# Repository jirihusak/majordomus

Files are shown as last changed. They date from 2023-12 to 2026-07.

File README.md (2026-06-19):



# Majordmus - Open source system for Smart Home
 
## About
 
**Majordomus** is a modular automation system built on open standards. It fills the gap between closed, expensive commercial solutions and unreliable consumer-grade components — designed to be repairable, expandable, and to last for decades.
  
## Features
 
- 🧩 **Modular hardware** — base unit + interchangeable modules ( I/O, sensors)
- 🔌 **Standardized interface** — RS-485 / ModBus HW interface, MQTT SW interface
- 🔓 **Vendor lock-in free** — open hardware, open software, your choice
- 🧠 **Node-RED inside** — visual programming for automation flows
- 🧠 **Home Assistant interface** — MQTT integration for popular platform
- 📡 **Offline-first** — works without internet, cloud is optional
## Use Cases
 
| Domain | Examples |
|---|---|
| 🏠 Smart home | lighting, heating, blinds, security, energy management |
| 🏭 Industry | machine control, data acquisition, monitoring, alarms |
| 📊 Monitoring | weather, air quality, energy meters, IoT sensors |
 
## Architecture
 
```
   ┌─────────────────────┐
   │      node-RED       │
   │   Home Assistant    │
   └──────────┬──────────┘
              │
             MQTT
              │
   ┌──────────┴──────────┐
   │ Majordomus Control  │
   │    MQTT bridge      │
   └──────────┬──────────┘
              │
       Modbus / RS-485
              │
    ┌─────────┼─────────┐
    │         │         │
   Unit A   Unit B   Unit C
  (+ modules) (+ modules) (+ modules)
```
 
## Hardware
 
### 🌡️ RoomSensor
 
All-in-one ambient monitoring unit for indoor environments.
 
- 🌡️ Temperature & humidity
- 💨 CO₂, VOC & NOx measurement
- 🚶 PIR motion detection
- ☀️ Ambient light (lux)
- 🔊 Ambient noise measurement
- 🖥️ Display with 3 buttons
- 🔔 Piezo buzzer for acoustic signaling
- 🔌 Digital I/O for door/window contacts or local buttons
- 🔗 I²C port for external sensors
- 🏠 Wall-mount
RoomSensor

### 🔲 BoxIO
 
Compact relay & input unit for in-wall or junction-box installation.
 
- ⚡ Replaceable relay outputs (electromagnetic or SSR)
- 🔘 Digital inputs for buttons
- 📊 Hardware input counters for energy monitoring
- 🎛️ Manual control of all outputs (AUTO / MAN ON / MAN OFF)
- 🔗 I²C port for external sensors
BoxIO

### 🎛️ RoomIO
 
Multi-purpose I/O unit for room-level automation and control.
 
- 🔘 Digital inputs & outputs
- 📥 Analog inputs (ADC) — 0–10 V
- 📤 Analog outputs (DAC) — 0–10 V for dimming, fan speed, valves
- 📊 Hardware input counters for energy monitoring
- 🔗 I²C port for external sensors
RoomIO

Schematics and BOMs live in [`hardware/`](hardware/).
 
## Software
 
### **Majordomus Control**
Bridge from HW modules to MQTT interface

obrazek

### **Node-RED - Custom Node-RED nodes**

## Documentation

- [Documentation web](https://jirihusak.github.io/majordomus/cs/) 

## Contributing
 
Contributions welcome — hardware, firmware, Node-RED flows, or docs.

## Contact
 
- **Web:** [majordomus.tech](https://majordomus.tech)

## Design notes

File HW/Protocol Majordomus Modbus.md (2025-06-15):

# Protocol Majordomus Modbus
This document describes the communication protocol between Majordomus devices and Main computer. The communication is based on RS-485 physical layer. 
|Serial settings| value|
|--|--|
| Baud rate | 115 200 kbps|
| Data bits | 8 |
| Stop bits | 1 |
| Parity | None |

On the bus is one master computer and the master requests data from all devices. The device sends no data without previous request.
Every Device has Modbus Address (1 - 247). See more information about Modbus protocol: https://en.wikipedia.org/wiki/Modbus

## RoomSensor

| Logical address | Register | Action | Size B | Type | Note |
|--|--|--|--|--|--|
| 0x41001  | 0x1000 | Read | 2 | INT16 | Temperature from front cover [*10 °C] |
| 0x41002  | 0x1001 | Read | 2 | INT16 | Temperature from humidity sensor [*10 °C] |
| 0x41003  | 0x1002 | Read | 2 | UINT16 | Relative humidity [*10 %] |
| 0x41004  | 0x1003 | Read | 2 | INT16 | Temperature from 1-Wire sensor 0 [*10 °C] |
| 0x41005  | 0x1004 | Read | 2 | INT16 | Temperature from 1-Wire sensor 1 [*10 °C] |
| 0x41006  | 0x1005 | Read | 2 | UINT16 | Air Quality VOC index [0-500] |
| 0x41007  | 0x1006 | Read | 2 | UINT16 | CO2 [ppm] |
| 0x41008  | 0x1007 | Read | 4 | UINT32 | Light intensity [lux] |
| 0x4100A  | 0x1009 | Read | 2 | UINT16 | Noise level [db] |
| 0x4100B  | 0x100A | Read | 2 | UINT16 | Motion detector PIR [0/1] |
| 0x4100C  | 0x100B | Read | 2 | UINT16 | Digital inputs state bit array |
| 0x4100D  | 0x100C | Read | 2 | UINT16 | Button inputs bit array rising edge detection |
| 0x4100E  | 0x100D | Read | 2 | UINT16 | ADC0 Analog input voltage [mV] |
| 0x4100F  | 0x100E | Read | 2 | UINT16 | ADC1 Analog input voltage [mV] |
| 0x41010  | 0x100F | Read | 2 | UINT16 | Power voltage voltage [mV] |
| 0x41011  | 0x1010 | Read | 2 | UINT16 | Power voltage for outputs voltage [mV] |
| 0x62001  | 0x2000 | Write | 2 | UINT16 | Digital outputs array |
| 0x62002  | 0x2001 | Write | 2 | UINT16 | DAC0 analog outputs [mV] |
| 0x62003  | 0x2002 | Write | 2 | UINT16 | DAC1 analog outputs [mV] |
| 0x62004  | 0x2003 | Write | 2 | UINT16 | Beep tone [0-4] |
| 0x62005  | 0x2004 | Write | 2 | UINT16 | LED light [0/1] |
| 0x62006  | 0x2005 | Write | 2 | INT16 | LCD Requested temperature [*10 °C] |

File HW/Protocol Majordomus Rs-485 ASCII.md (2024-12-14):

# Protocol Majordomus Rs-485 ASCII
This document describes the communication protocol between Majordomus devices and Main computer. The communication is based on RS-485 physical layer. 
|Serial settings| value|
|--|--|
| Baud rate | 115 200 kbps|
| Data bits | 8 |
| Stop bits | 1 |
| Parity | None |

On the bus is one master computer and the master requests data from all devices. The device sends no data without previous request.
Every Device has `id` string with maximum length of 32 characters.

```mermaid
sequenceDiagram
Master->>Device A: id:A,msg:data,crc:XX
Device A -->>Master: id:A,msg:data,crc:XX
Master->>Device B: id:B,msg:data,crc:XX
Device B-->>Master: id:B,msg:data,crc:XX
```

## Generic message format for all devices
- Message starts with `id:deviceName`. 
- Message ends with `CR LF` characters.
- Message has properties separed by `,` and one property has format `key:value`.
- Last property is `crc`. [CRC Calculation](#crc-calculation)

### Example 1 - Read device status
Main computer sends message to request status from device `test`:
 `id:test,msg:status,crc:8b\r\n`
 Response from device (FW version, power voltages):
`id:test,type:RoomSens,version:0.3(Nov  2 2024),pwr:12.05,pwrOut:12.11,crc:f0`

 ### Example 2 - Read device data
Main computer sends message to request from device `test` data:
 `id:test,msg:data,crc:ea`
 Response from device (digital inputs, temperatures, humidity, etc.. ):
`id:test,di:0,btn:0,t:210,t2:211,rh:540,mo:0,voc:95,lux:569,nl:278,adc0:0.00,adc1:0.00,crc:22`

 ### Example 3 - Read and write device data
Main computer sends message to request from device `test` data and write data to device (digital outputs, DAC, led light etc.. ):
 `id:test,msg:data,do:3,dac0:5.4,dac1:1.2,light:1,reqT:225,crc:93`
 Response from device (digital inputs, temperatures, humidity, etc.. ):
`id:test,di:0,btn:0,t:210,t2:211,rh:540,mo:0,voc:95,lux:569,nl:278,adc0:0.00,adc1:0.00,crc:22`

### Example 4 - Change device id
Main computer sends config message to device `test` to change id to `test2`.
 `id:test,msg:config,newId:test2,crc:ea`

### Example 5 - Restart device
Main computer sends config message to device `test` to restart
 `id:test,msg:config,cmd:reset,crc:07`

> If you don't know device `id`, you can replace `deviceName` with string `all`. So the message is for all devices on the bus. In this case respond all devices for the request. To prevent bus colision on RS-485 every device add random delay before start sending response. This fetature is not recomended for normal operation.

### Status message
    id:device_id,msg:status,...
| From RoomIO| Note|
|--|--|
| type | type of device (RoomIO) |
| version | FW version X.Y (Build date) |
| pwr | Power voltage in volts |
| pwrOut | Power voltage in volts after fuse for digital outputs and inputs |
### Config message
    id:device_id,msg:config,...
| To RoomIO| Note|
|--|--|
| newId | Change id to new string (max 32 characters) |
| newId5050| The same as newID, but the commands will executed with 50:50 propability (depends on random generator on device). This command can be helpful when we have two same id on the bus|
| reset| Restart the device |

## RoomIO
### Data message

    id:device_id,msg:data,...

| From RoomIO| Note|
|--|--|
| adc0  | Analog input voltage |
| adc1  | Analog input voltage |
| di  | Digital inputs bit array |
| btn | Digital buttons bit array. Sends only once rising edges. |
| t0| Temperature in °C from 1-Wire sensor|
| t1| Temperature in °C from 1-Wire sensor|

| To RoomIO| note|
|--|--|
| dac0 | Set Digital to Analog voltage |
| dac1 | Set Digital to Analog voltage |
| do | Set digital outputs bit array (bit 0 = digital output 0, etc.. )|

## RoomSensor
### Data message

    id:device_id,msg:data,...

| From RoomSensor| Note|
|--|--|
| adc0  | Analog input voltage |
| adc1  | Analog input voltage |
| di  | Digital inputs bit array |
| btn | Digital buttons bit array. Sends only once rising edges. |
| t0| Temperature in °C from front cover|
| t1| Temperature in °C from humidity sensor|
| t2| Temperature in °C from 1-Wire sensor|
| t3| Temperature in °C from 1-Wire sensor|
| rh| Relative humidity in % |
| mo| Motion detector PIR [0/1] |
| voc| Air Quality VOC [0-500] |
| lux| Light intensity in lux |
| nl| Noise level in db |
| newReqT| New Temperature set request from display - send once when user confirm |

| To RoomSensor| note|
|--|--|
| dac0 | Set Digital to Analog voltage |
| dac1 | Set Digital to Analog voltage |
| do | Set digital outputs bit array (bit 0 = digital output 0, etc.. )|
| reqT| Actual temperature set displayed on LCD |
| beep| Start beeping [0-4] |
| light| Control LED light [0-1] |

## TinySensor
### Data message

    id:device_id,msg:data,...

| From TinySensor| Note|
|--|--|
| di  | Digital inputs bit array |
| btn | Digital buttons bit array. Sends only once rising edges. |
| t0| Temperature in °C |
| rh| Relative humidity in % |
| t1| Temperature in °C from 1-Wire sensor|
| t2| Temperature in °C from 1-Wire sensor|

| To RoomSensor| note|
|--|--|
| do | Set digital outputs bit array (bit 0 = digital output 0, etc.. )|

### CRC calculation

    static unsigned char const crc8_table[] = {
	    0xea, 0xd4, 0x96, 0xa8, 0x12, 0x2c, 0x6e, 0x50, 0x7f, 0x41, 0x03, 0x3d,
	    0x87, 0xb9, 0xfb, 0xc5, 0xa5, 0x9b, 0xd9, 0xe7, 0x5d, 0x63, 0x21, 0x1f,
	    0x30, 0x0e, 0x4c, 0x72, 0xc8, 0xf6, 0xb4, 0x8a, 0x74, 0x4a, 0x08, 0x36,
	    0x8c, 0xb2, 0xf0, 0xce, 0xe1, 0xdf, 0x9d, 0xa3, 0x19, 0x27, 0x65, 0x5b,
	    0x3b, 0x05, 0x47, 0x79, 0xc3, 0xfd, 0xbf, 0x81, 0xae, 0x90, 0xd2, 0xec,
	    0x56, 0x68, 0x2a, 0x14, 0xb3, 0x8d, 0xcf, 0xf1, 0x4b, 0x75, 0x37, 0x09,
	    0x26, 0x18, 0x5a, 0x64, 0xde, 0xe0, 0xa2, 0x9c, 0xfc, 0xc2, 0x80, 0xbe,
	    0x04, 0x3a, 0x78, 0x46, 0x69, 0x57, 0x15, 0x2b, 0x91, 0xaf, 0xed, 0xd3,
	    0x2d, 0x13, 0x51, 0x6f, 0xd5, 0xeb, 0xa9, 0x97, 0xb8, 0x86, 0xc4, 0xfa,
	    0x40, 0x7e, 0x3c, 0x02, 0x62, 0x5c, 0x1e, 0x20, 0x9a, 0xa4, 0xe6, 0xd8,
	    0xf7, 0xc9, 0x8b, 0xb5, 0x0f, 0x31, 0x73, 0x4d, 0x58, 0x66, 0x24, 0x1a,
	    0xa0, 0x9e, 0xdc, 0xe2, 0xcd, 0xf3, 0xb1, 0x8f, 0x35, 0x0b, 0x49, 0x77,
	    0x17, 0x29, 0x6b, 0x55, 0xef, 0xd1, 0x93, 0xad, 0x82, 0xbc, 0xfe, 0xc0,
	    0x7a, 0x44, 0x06, 0x38, 0xc6, 0xf8, 0xba, 0x84, 0x3e, 0x00, 0x42, 0x7c,
	    0x53, 0x6d, 0x2f, 0x11, 0xab, 0x95, 0xd7, 0xe9, 0x89, 0xb7, 0xf5, 0xcb,
	    0x71, 0x4f, 0x0d, 0x33, 0x1c, 0x22, 0x60, 0x5e, 0xe4, 0xda, 0x98, 0xa6,
	    0x01, 0x3f, 0x7d, 0x43, 0xf9, 0xc7, 0x85, 0xbb, 0x94, 0xaa, 0xe8, 0xd6,
	    0x6c, 0x52, 0x10, 0x2e, 0x4e, 0x70, 0x32, 0x0c, 0xb6, 0x88, 0xca, 0xf4,
	    0xdb, 0xe5, 0xa7, 0x99, 0x23, 0x1d, 0x5f, 0x61, 0x9f, 0xa1, 0xe3, 0xdd,
	    0x67, 0x59, 0x1b, 0x25, 0x0a, 0x34, 0x76, 0x48, 0xf2, 0xcc, 0x8e, 0xb0,
	    0xd0, 0xee, 0xac, 0x92, 0x28, 0x16, 0x54, 0x6a, 0x45, 0x7b, 0x39, 0x07,
	    0xbd, 0x83, 0xc1, 0xff};
	    
	uint8_t crc8(uint8_t seed = 0, unsigned char const *data, size_t len)
	{
		uint8_t crc = seed;
		if (data == NULL)
	        return 0;
	    crc &= 0xff;
	    unsigned char const *end = data + len;
	    while (data < end)
	        crc = crc8_table[crc ^ *data++];
	    return crc;
	}

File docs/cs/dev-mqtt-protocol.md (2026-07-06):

# MQTT protokol

Referenční popis MQTT rozhraní, které poskytuje Majordomus Control. Hodí se všem, kdo chtějí systém integrovat mimo Home Assistant — do Node-RED, openHAB, vlastních skriptů nebo čehokoliv dalšího, co umí MQTT.

Majordomus Control funguje jako brána: čte data z jednotek po RS-485 a publikuje je do MQTT témat. Zároveň odebírá příkazová témata a přijaté příkazy předává zpět jednotkám.

```
[RS-485 jednotky] <--serial--> [Majordomus Control] <--MQTT--> [Broker] <--> [HA / Node-RED / klient]
```

Anglický originál této reference: [MQTT_PROTOCOL.md](https://github.com/jirihusak/majordomus/blob/main/SW/MajordomusControl/MQTT_PROTOCOL.md)

---

## Struktura témat

Každé téma má tvar:

```
<prefix>/<zařízení>/<kategorie>/<klíč>
```

| Segment | Popis | Příklad |
|---|---|---|
| `<prefix>` | Nastavený MQTT prefix včetně koncového `/` | `majordomus/` |
| `<zařízení>` | Název zařízení dle konfigurace | `living_room` |
| `<kategorie>` | `tele`, `evt`, `state` nebo `cmd` | `tele` |
| `<klíč>` | Konkrétní vlastnost | `temperature0` |

**Příklad:** `majordomus/living_room/tele/temperature0`

### Kategorie témat

| Kategorie | Kdy se publikuje | Retained | Účel |
|---|---|---|---|
| `tele` | Periodicky (každý cyklus vyčítání RS-485) | **Ano** | Naměřené hodnoty senzorů |
| `evt` | Pouze při změně | **Ne** | Události: stisk tlačítka, pohyb |
| `state` | Při změně | **Ano** | Metadata zařízení a stavy výstupů |
| `cmd` | Publikuje klient (vy) | — | Příkazy pro zařízení |

Všechny zprávy se posílají s **QoS 0**. Payload je vždy UTF-8 řetězec — číslo (`22.5`, `420`), řetězec, nebo JSON pole.

---

## Odesílání příkazů

Příkaz zařízení pošlete publikováním do tématu:

```
<prefix>/<zařízení>/cmd/<klíč_příkazu>
```

**Příklad — zapnutí digitálního výstupu 0 na zařízení `living_room`:**

```
Téma:    majordomus/living_room/cmd/do0
Payload: 1
```

---

## Dostupnost zařízení

Každé zařízení publikuje svůj stav do retained tématu:

```
<prefix>/<zařízení>/state/online
```

| Payload | Význam |
|---|---|
| `online` | Zařízení odpovídá na dotazy po RS-485 |
| `offline` | Bez odpovědi déle než 3 sekundy |

Toto téma se používá jako `availability_topic` v Home Assistant discovery.

---

## Konvence hodnot

**NaN** — firmware používá hodnotu `INT16_MIN` (`-32768`) pro senzor, který není dostupný (nepřipojen, chyba čtení). Brána ji před publikováním převádí na řetězec `"NaN"`. Payload `"NaN"` vždy interpretujte jako nedostupnou hodnotu.

**Škálované hodnoty** — některá zařízení posílají po sběrnici celočíselné hodnoty, které je nutné dělit koeficientem. Převod provádí brána — přes MQTT vždy dostanete finální hodnotu jako float.

**Pocitová teplota** — pokud jsou platné `temperature0` i `humidity`, brána automaticky počítá a publikuje pocitovou teplotu (Steadmanův vzorec) do tématu `tele/apparentTemperature`.

---

## Mapy témat podle typu zařízení

### RoomIO

Univerzální I/O jednotka s teploměry, digitálními vstupy/výstupy, analogovými vstupy a čítači impulsů.

**Publikuje — `tele/` (retained):**

| Klíč | Jednotka | Typ | Poznámka |
|---|---|---|---|
| `temperature0` – `temperature2` | °C | float | Teploměry; `NaN` pokud nedostupný |
| `humidity` | % | float | Relativní vlhkost |
| `voc` | index | int | Kvalita vzduchu VOC |
| `co2` | ppm | int | Koncentrace CO₂ |
| `illuminance` | lux | int | Osvětlení |
| `distance` | — | float | Snímač vzdálenosti |
| `analog0`, `analog1` | V | float | Analogové vstupy |
| `counter0` – `counter7` | — | int | Čítače impulsů |
| `input0` – `input7` | — | `0`/`1` | Stavy digitálních vstupů |
| `apparentTemperature` | °C | float | Vypočtená pocitová teplota |

**Publikuje — `evt/` (bez retain):** `button0` – `button7` (`0`/`1`) při změně stavu tlačítka.

**Publikuje — `state/` (retained):** `version` (verze FW), `power` (napájecí napětí, V), `powerOut` (napětí za pojistkou výstupů, V), `online`.

**Příkazy — `cmd/`:**

| Klíč | Payload | Účinek |
|---|---|---|
| `do0` – `do7` | `0` / `1` | Nastavení digitálního výstupu |
| `dac0`, `dac1` | `0`–`255` | Úroveň analogového výstupu (DAC/PWM) |
| `setCnt0` – `setCnt7` | celé číslo | Přednastavení hodnoty čítače |
| `reboot` | cokoliv | Restart zařízení |

---

### RoomSensor

Pokojová jednotka se senzory prostředí, detekcí pohybu, kapacitními tlačítky a výstupy.

**Publikuje — `tele/` (retained):**

| Klíč | Jednotka | Typ | Poznámka |
|---|---|---|---|
| `temperature0` – `temperature3` | °C | float | Až 4 teploměry |
| `humidity` | % | float | Relativní vlhkost |
| `voc` | index | int | VOC index (SGP41) |
| `nox` | index | int | NOx index (SGP41) |
| `co2` | ppm | int | Koncentrace CO₂ |
| `illuminance` | lux | int | Osvětlení (VEML7700) |
| `noise` | dB | int | Hladina hluku |
| `analog0`, `analog1` | V | float | Analogové vstupy |
| `input0` – `input3` | — | `0`/`1` | Stavy digitálních vstupů |
| `apparentTemperature` | °C | float | Vypočtená pocitová teplota |

**Publikuje — `evt/` (bez retain):**

| Klíč | Typ | Kdy |
|---|---|---|
| `motion` | `0`/`1` | Změna stavu PIR čidla |
| `lastMotion` | ISO datetime | Čas poslední detekce pohybu |
| `button0` – `button3` | `0`/`1` | Stisk kapacitního tlačítka |

**Publikuje — `state/` (retained):** `version`, `power`, `powerOut`, `requestedTemperature` (aktuální žádaná teplota), `online`.

**Příkazy — `cmd/`:**

| Klíč | Payload | Účinek |
|---|---|---|
| `do0` – `do3` | `0` / `1` | Nastavení digitálního výstupu |
| `dac0`, `dac1` | `0`–`255` | Úroveň analogového výstupu |
| `beep` | celé číslo | Pípnutí piezo pípáku |
| `reqT` | float `10`–`35` | Nastavení žádané teploty |
| `light` | `0`–`100` | Úroveň LED přísvitu (%) |
| `reboot` | cokoliv | Restart zařízení |

---

### TempOutBoard

Deska pro venkovní měření s až 8 teploměry DS18B20 a digitálními výstupy.

**Publikuje — `tele/` (retained):** `temperature0` – `temperature7` (°C, float).

**Publikuje — `state/` (retained):** `version`, `power`, `powerOut`, `online`.

**Příkazy — `cmd/`:** `do0` – `do9` (`0`/`1`), `ro` (`0`–`255`, PWM výstup).

---

### RoomIR

Modul termální infrakamery (MLX90640, 32×24 pixelů).

**Publikuje — `tele/` (retained):** `irImage` — JSON pole 768 hodnot (32 sloupců × 24 řádků, po řádcích zleva shora), teploty v °C:

```json
[25.1, 25.3, 24.8, 26.0, ...]
```

**Publikuje — `state/` (retained):** `version`, `resolution` (škálovací faktor), `offset`, `online`.

---

## Home Assistant discovery

Po připojení k brokeru publikuje brána automaticky discovery zprávy pro všechna nakonfigurovaná zařízení — Home Assistant si díky nim vytvoří entity bez ručního YAML.

**Formát tématu:** `<ha_prefix>/<typ_entity>/<unique_id>/config` — např. `homeassistant/sensor/living_room_t0/config`.

**Payload (JSON, retained):**

```json
{
  "name": "temperature0",
  "unique_id": "living_room_t0",
  "state_topic": "majordomus/living_room/tele/temperature0",
  "unit_of_measurement": "°C",
  "device_class": "temperature",
  "state_class": "measurement",
  "availability_topic": "majordomus/living_room/state/online",
  "payload_available": "online",
  "payload_not_available": "offline",
  "device": {
    "identifiers": ["living_room"],
    "manufacturer": "Majordomus",
    "model": "RoomSensor",
    "name": "living_room"
  }
}
```

Discovery zprávy se znovu publikují při každém obnovení spojení s brokerem (řeší restart brokeru).

---

## Připojení k brokeru

| Parametr | Hodnota |
|---|---|
| Verze MQTT | 3.1.1 |
| URL brokeru | `tcp://host:1883` nebo `ssl://host:8883` |
| QoS | 0 (všechny zprávy) |
| Timeout připojení | 30 s |
| Keep-alive | 5 s |
| Automatický reconnect | Ano |
| TLS | Systémový Java TrustStore, nebo vlastní PEM CA certifikát |

---

## Rychlý tahák

```
ČTENÍ hodnoty senzoru:
  Subscribe: <prefix>/<zařízení>/tele/<klíč>
  Subscribe: <prefix>/<zařízení>/state/<klíč>

POSLECH událostí:
  Subscribe: <prefix>/<zařízení>/evt/<klíč>

PŘÍKAZ:
  Publish:   <prefix>/<zařízení>/cmd/<klíč>   payload: <hodnota>

DOSTUPNOST:
  Subscribe: <prefix>/<zařízení>/state/online   → "online" | "offline"

VŠE NAJEDNOU:
  Subscribe: <prefix>/#
```

!!! tip "Rychlý test z příkazové řádky"
    ```bash
    # sledování všech dat
    mosquitto_sub -h localhost -t "majordomus/#" -v

    # zapnutí výstupu do0 na zařízení living_room
    mosquitto_pub -h localhost -t "majordomus/living_room/cmd/do0" -m "1"
    ```

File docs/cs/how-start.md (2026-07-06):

# Co potřebuji pro start

Majordomus je navržen tak, aby ho zvládl zprovoznit i nadšenec bez hlubokých znalostí elektroniky nebo programování. Přesto je dobré vědět, jaké základní vybavení budete potřebovat.

---

## Minimální hardware

Pro první spuštění a vyzkoušení systému vám stačí:

- **Řídící jednotka** — například Raspberry Pi 4 nebo jakýkoliv mini PC s Linuxem. Pro první test postačí i běžný stolní počítač nebo notebook.
- **[Převodník USB → RS-485](https://majordomus.tech/rs485-2-usb/)** — propojuje řídící jednotku se sběrnicí Majordomus.
- **Modul Majordomus** — pro test stačí jeden kus [RoomIO](https://majordomus.tech/roomio/) nebo [RoomSensor](https://majordomus.tech/roomsensor/).
- **Napájecí zdroj** — 12 V DC (systém akceptuje rozsah 7–27 V DC).
- **Propojovací kabel** — běžný UTP kabel (Cat5e nebo Cat6) pro napájení a komunikaci.
- **Volitelně pro testování** — tlačítka, 12V LED indikátory, senzory apod.

!!! tip "Chci to jen vyzkoušet"
    Nepotřebujete hned kupovat Raspberry Pi ani tahat kabely po domě. Stačí notebook, USB převodník, jeden modul a kus UTP kabelu na stole — a za pár minut máte funkční systém, se kterým si můžete hrát.

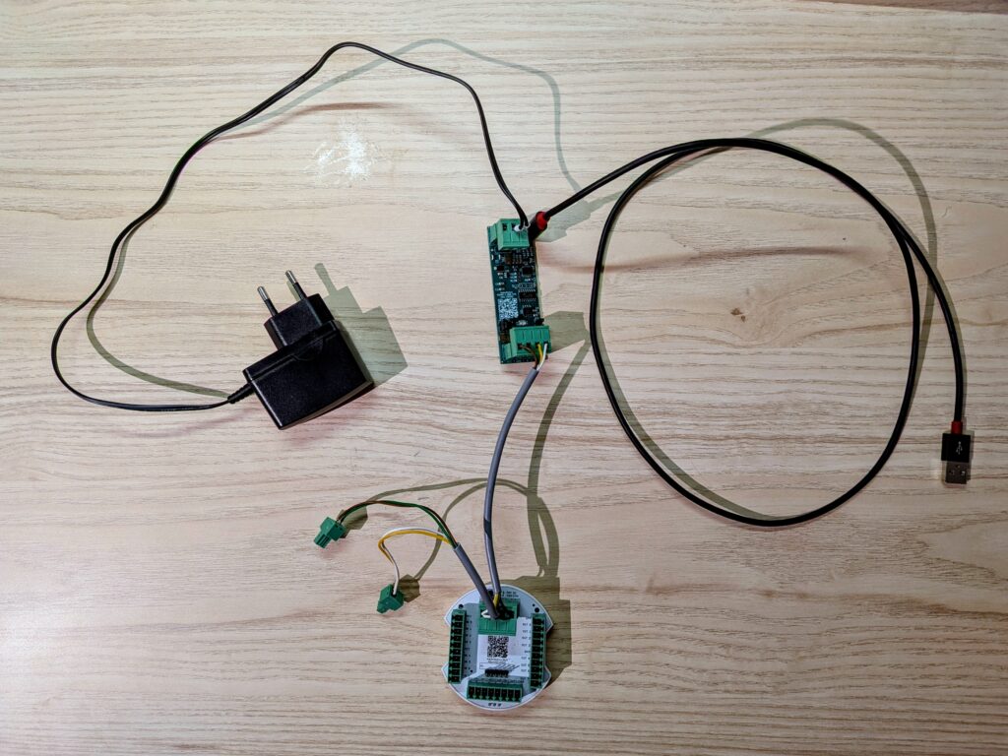
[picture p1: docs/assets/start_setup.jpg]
Minimální zapojení na vyzkoušení


---

## Software

Majordomus využívá výhradně open-source software. Nemusíte kupovat žádné licence ani řídící software — všechny nástroje jsou zdarma ke stažení.

- **OS Linux nebo Windows** — řídící jednotka běží na obojím.
- **[MajordomusControl](sw-architecture.md)** — jádro systému, které komunikuje s hardwarem a poskytuje MQTT rozhraní.
- **Aplikační software** — například [Node-RED](sw-node-red.md) pro tvorbu logiky a automatizací.

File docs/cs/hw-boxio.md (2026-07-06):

# BoxIO

BoxIO je multifunkční jednotka do rozvaděče s rozhraním RS-485 a USB. Poskytuje 8 digitálních vstupů, 6 silových výstupů a 2 analogové vstupy a výstupy. Montuje se na DIN lištu a zabírá šířku 6 modulů.

Silové výstupy jsou řešeny jako **výměnné moduly** — podle potřeby je osadíte elektromagnetickým relé (max. 16 A) nebo polovodičovým SSR (max. 2 A).

---

## Vlastnosti

- Průmyslové rozhraní RS-485
- Rozhraní USB-C (vestavěný FTDI převodník) — jednotku lze připojit i přímo do PC
- **Manuální ovládání výstupů** — třístavový přepínač pro každý výstup: manuálně zapnuto / manuálně vypnuto / automatika (řízení ze sběrnice)
- LED indikace aktivních vstupů a výstupů
- 8× digitální vstup s optickým oddělením
- Funkce čítače digitálních vstupů s pamětí FRAM
- 6× výměnný modul výstupu (relé max. 16 A, nebo SSR max. 2 A)
- 2× analogový vstup 0–30 V
- 2× analogový výstup 0–10 V
- 2× port 1-Wire pro externí teploměry DS18B20
- 1× port I2C pro externí zařízení

!!! tip "Manuální režim — dům funguje i bez serveru"
    Třístavové přepínače umožňují ovládat výstupy ručně přímo v rozvaděči. Pokud řídící počítač vypadne nebo probíhá servis, zapnete topení či světla přepínačem — bez software, bez počítače.

---

## Parametry

| Parametr | Hodnota |
|---|---|
| Vstupní napájení | 10–30 V DC |
| Komunikační rozhraní | RS-485 (ASCII protokol), Modbus, USB-C |
| Instalace | DIN lišta (šířka 6 modulů) |
| Mikrokontrolér | PIC18F57K42 |
| Aktualizace FW po RS-485 | Ano |
| Stupeň krytí | IP20 |
| Teplotní rozsah | −20 až +60 °C |

---

## Typické použití

BoxIO je určen do rozvaděče — tam, kde se sbíhá silová elektroinstalace:

- Spínání okruhů osvětlení přes relé moduly
- Ovládání ventilů topení, čerpadel a bojleru
- Spínání zásuvkových okruhů
- Odečty elektroměrů a vodoměrů s impulsním výstupem (čítače na digitálních vstupech)
- Řízení stmívatelných LED zdrojů a proporcionálních ventilů přes výstupy 0–10 V

!!! tip "Objednání a aktuální ceny"
    Aktuální ceny a objednávkový formulář najdete na [majordomus.tech/boxio](https://majordomus.tech/boxio/).

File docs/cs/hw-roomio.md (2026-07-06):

# RoomIO

RoomIO je multifunkční jednotka vstupů a výstupů s rozhraním RS-485. Poskytuje 8 digitálních vstupů, 8 digitálních výstupů, 2 analogové vstupy, 2 analogové výstupy a 2 open-drain výstupy. Lze ji rozšířit o teploměry a další senzory přes 1-Wire a I2C.

Díky kompaktnímu designu je možné jednotku snadno skrýt — instaluje se přímo do instalační krabice (KP 68) a překryje záslepkou, případně se umístí do podhledu.

---

## Vlastnosti

- Průmyslové rozhraní RS-485
- 8× digitální vstup s optickým oddělením
- Funkce čítače digitálních vstupů s pamětí FRAM (64bit čítač — hodnoty přežijí výpadek napájení)
- 8× digitální výstup (6–30 V dle napájení, do 100 mA)
- 2× analogový vstup 0–30 V
- 2× analogový výstup 0–10 V
- 2× port 1-Wire pro externí teploměry DS18B20
- 1× port I2C pro externí zařízení
- 2× open-drain výstup pro ovládání RGB LED WS2812

---

## Parametry

| Parametr | Hodnota |
|---|---|
| Vstupní napájení | 6–30 V DC |
| Komunikační rozhraní | RS-485 (ASCII protokol), Modbus |
| Instalační krabice | Přístrojová krabice KP 68 |
| Mikrokontrolér | PIC18F57K42 |
| Aktualizace FW po RS-485 | Ano |
| Stupeň krytí | IP30 |
| Teplotní rozsah | −20 až +60 °C |

---

## Typické použití

**Digitální vstupy** — připojení tlačítek, magnetických (okenních/dveřních) kontaktů nebo mikrospínačů. Každý vstup má 64bitový čítač impulsů s pamětí FRAM — ideální pro odečty elektroměrů, vodoměrů a plynoměrů s impulsním výstupem.

**Digitální výstupy** — spínání elektromagnetických relé, SSR relé nebo indikačních LED. Vstupy i výstupy pracují s napájecím napětím jednotky (typicky 12 nebo 24 V DC).

**Analogové vstupy 0–30 V** — snímače tlaku, ultrazvukové snímače vzdálenosti (např. hladina v nádrži) a podobně.

**Analogové výstupy 0–10 V** — stmívatelné zdroje LED osvětlení nebo proporcionální ventily topení.

**1-Wire** — až několik teploměrů DS18B20 na jednom portu, např. pro měření teploty podlahy nebo venkovní teploty.

!!! tip "Objednání a aktuální ceny"
    Aktuální ceny a objednávkový formulář najdete na [majordomus.tech/roomio](https://majordomus.tech/roomio/).

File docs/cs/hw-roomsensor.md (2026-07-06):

# RoomSensor

RoomSensor je švýcarský nožík mezi senzory do místnosti. Instaluje se do běžné elektroinstalační krabice (KP 68) a v jediném kompaktním zařízení pokryje vše, co v místnosti potřebujete — místo čtyř různých krabiček stačí jeden RoomSensor:

- **Jednotka vstupů a výstupů** — 4× digitální vstup, 4× digitální výstup, 2× analogový vstup, 2× analogový výstup
- **Měření veličin prostředí** — teplota, relativní vlhkost, kvalita vzduchu (VOC, NOx, CO₂)
- **Detekce přítomnosti** — PIR senzor, hlukoměr, intenzita osvětlení
- **Rozhraní pro uživatele** — grafický displej, kapacitní tlačítka a akustická signalizace

---

## Vlastnosti

### Senzory prostředí

| Veličina | Senzor |
|---|---|
| Teplota | TMP1075 |
| Relativní vlhkost | SHT-45 (s ochrannou membránou) |
| CO₂ | STCC4 |
| VOC a NOx | SGP-41 |
| Intenzita osvětlení | VEML7700 |
| Hluk | MEMS mikrofon MP34DT05-A |
| Pohyb | PIR EKMC1607113 |

### Vstupy a výstupy

- 4× digitální vstup s optickým oddělením
- 4× digitální výstup
- 2× analogový vstup 0–30 V
- 2× analogový výstup 0–10 V
- 2× port 1-Wire pro externí teploměry DS18B20
- 1× port I2C pro externí zařízení

### Uživatelské rozhraní

- Grafický displej 128×32 px (NHD-C12832A1Z)
- 3 kapacitní tlačítka (mínus, enter, plus)
- Piezo pípák pro akustické upozornění
- LED přísvit

---

## Parametry

| Parametr | Hodnota |
|---|---|
| Vstupní napájení | 7–27 V DC |
| Komunikační rozhraní | RS-485 (ASCII protokol), Modbus |
| Instalační krabice | Přístrojová krabice KP 68 |
| Design | ABB Tango |
| Mikrokontrolér | PIC18F57K42 |
| Aktualizace FW po RS-485 | Ano |
| Stupeň krytí | IP30 |
| Teplotní rozsah | −20 až +60 °C |

---

## Typické použití

Jeden RoomSensor v každé obytné místnosti — obývák, ložnice, dětský pokoj, kuchyň:

- Řízení topení podle skutečné teploty v místnosti
- Spouštění ventilace / rekuperace podle CO₂ a vlhkosti
- Automatické osvětlení podle přítomnosti a intenzity denního světla
- Ovládání světel a žaluzií kapacitními tlačítky
- Zobrazení teploty a dalších hodnot na displeji

Přes digitální a analogové vstupy/výstupy lze navíc přímo z jednotky ovládat stmívatelné LED osvětlení (0–10 V), číst okenní kontakty nebo spínat relé.

!!! tip "Objednání a aktuální ceny"
    Aktuální ceny a objednávkový formulář najdete na [majordomus.tech/roomsensor](https://majordomus.tech/roomsensor/).

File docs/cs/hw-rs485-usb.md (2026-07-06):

# Převodník RS485 2 USB

RS485 2 USB propojuje řídící počítač (Raspberry Pi, mini PC) se sběrnicí RS-485. Do počítače se připojuje konektorem USB-C a poskytuje jednu galvanicky izolovanou linku RS-485 — na ni doporučujeme připojit maximálně 10 jednotek Majordomus.

Každá linka (sběrnice) v domě potřebuje svůj převodník — viz [Topologie](topology.md).

---

## Vlastnosti

- Průmyslové rozhraní RS-485 s **galvanickým oddělením** — rušení z dlouhých linek se nepřenáší do řídícího počítače
- 1 nebo 4 komunikační linky včetně rozvodu napájení
- **Vratná pojistka** — chrání UTP kabel při zkratu na lince
- Indikační LED pro RX a TX — okamžitá vizuální kontrola komunikace
- Zakončovací odpor volitelný jumperem
- Vyrovnání GND potenciálu linky přes impedanci na PE
- Možnost připojit se přímo na UART

---

## Parametry

| Parametr | Hodnota |
|---|---|
| Vstupní napájení | 7–27 V DC |
| Komunikační rozhraní | USB (konektor USB-C) |
| Převodník | FTDI FT230XS |
| Montáž | DIN lišta |
| Stupeň krytí | IP30 |
| Teplotní rozsah | −20 až +60 °C |

---

## Připojení k počítači

Převodník používá čip FTDI, který mají Linux i Windows ve výbavě — po připojení se objeví jako sériový port bez instalace ovladačů:

| Systém | Název portu |
|---|---|
| Linux / Raspberry Pi OS | `/dev/ttyUSB0` (další převodníky `ttyUSB1`, `ttyUSB2`...) |
| Windows | `COM3`, `COM4`... |

Tento port poté nastavíte v Majordomus Control v sekci **Serial Connections** — viz [Konfigurace SW](sw-configuration.md).

!!! note "Práva k sériovému portu na Linuxu"
    Pokud Majordomus Control nemůže port otevřít, přidejte uživatele do skupiny `dialout` a znovu se přihlaste:

    ```bash
    sudo usermod -a -G dialout $USER
    ```

!!! tip "Objednání a aktuální ceny"
    Aktuální ceny a objednávkový formulář najdete na [majordomus.tech/rs485-2-usb](https://majordomus.tech/rs485-2-usb/).

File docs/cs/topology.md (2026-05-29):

# Topologie systému
 
Základem je jeden hlavní počítač (např. Raspberry Pi), ke kterému jsou přes USB připojeny RS485 převodníky. Každý převodník obsluhuje jednu **linku** — sběrnici, na které visí zařízení v dané části domu.
 
Typické rozložení pro rodinný dům:
 
```mermaid
graph TD
    PC[Mini PC / Raspberry Pi] -->|USB| L1[Linka 1 — 1. NP]
    PC -->|USB| L2[Linka 2 — 2. NP]
    PC -->|USB| L3[Linka 3 — podkroví / zahrada]
    
    L1 -->|RS-485| R1[RoomSensor — obývák]
    R1 -->|RS-485| R2[RoomSensor — kuchyň]
    R2 -->|RS-485| R3[RoomIO — chodba]
    R3 -->|RS-485| B1[BoxIO — rozvaděč 1. NP]
    
    L2 -->|RS-485| R4[RoomSensor — ložnice]
    R4 -->|RS-485| R5[RoomSensor — dětský pokoj]
    R5 -->|RS-485| R6[RoomSensor — koupelna]
    R6 -->|RS-485| B2[BoxIO — rozvaděč 2. NP]
```
 
Doporučujeme **jednu linku na patro** (nebo logickou zónu — zahrada, garáž, dílna). Na každé lince může být přibližně **10–15 zařízení**. Tento limit není technický, ale praktický — zajišťuje rychlou odezvu tlačítek a spínačů.
 
---
 
## Kabeláž
 
### Doporučený kabel
 
Sběrnice RS485 využívá standardní ethernetový kabel, který je levný, všude dostupný a snadno se s ním pracuje:
 
- **Typ:** UTP-S (stíněný) nebo UTP-F (fóliově stíněný), kategorie Cat5e nebo Cat6
- **Provedení:** doporučujeme **lanko** (flexible), ne drát (solid) — snadnější manipulace v instalačních krabicích

### Zapojení vodičů
 
UTP kabel má 8 vodičů, vždy 2 vodiče tvoří barevný pár. Vodiče zdvojíme podle barev a využijeme 4 páry:
 
| Signál | Barva vodiče | Popis |
|---|---|---|
| **+12 V** | oranžový pár | Napájení zařízení |
| **GND** | modrý pár | Zem |
| **A** | zelený pár | RS485 datový vodič A |
| **B** | hnědý pár | RS485 datový vodič B |
 
!!! tip "Proč zrovna tyto barvy?"
    Barevné přiřazení vychází ze standardního značení UTP kabelů a je jednotné napříč celým systémem Majordomus. Díky tomu se při zapojování nemůžete splést — a pokud vám někdy bude zapojení dělat někdo jiný, okamžitě se zorientuje.
 
### Maximální délka linky
 
Sběrnice RS485 při komunikační rychlosti 115 200 Bd zvládne teoreticky až **1 000 m** v ideálních podmínkách. Pro běžné domácí instalace doporučujeme:
 
- **Do 200 m na linku** — spolehlivý provoz bez kompromisů

---
 
## Napájení
 
Všechna zařízení na sběrnici se napájí přímo z linky napětím **12 V DC**. Stačí jeden zdroj na celý systém.
 
- **Standardní instalace:** 12V spínaný zdroj s dostatečným výkonem pro všechna zařízení na lince (např. 25W - 75W)
- **Instalace s UPS:** zdroj s akumulátorovou zálohou na napětí **13,8 V** — systém běží i při výpadku elektřiny
 
---

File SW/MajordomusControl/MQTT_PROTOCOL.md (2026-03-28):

# MajordomusControl — MQTT Protocol Reference

**Version:** 1.0
**System:** MajordomusControl — RS-485 to MQTT Gateway
**Protocol:** MQTT v3.1.1

---

## Overview

MajordomusControl is a gateway that bridges RS-485 sensor devices to an MQTT broker.
It reads sensor data from physical devices over serial RS-485 and publishes it to MQTT topics.
It also subscribes to command topics and forwards received commands back to devices via RS-485.

```
[RS-485 Devices] <--serial--> [MajordomusControl] <--MQTT--> [Broker] <--> [HA / AI / Client]
```

---

## Table of Contents

1. [Topic Structure](#1-topic-structure)
2. [Topic Categories](#2-topic-categories)
3. [QoS and Retain Policy](#3-qos-and-retain-policy)
4. [Sending Commands](#4-sending-commands)
5. [Availability](#5-availability)
6. [Sensor Value Conventions](#6-sensor-value-conventions)
7. [Device Types and Topic Maps](#7-device-types-and-topic-maps)
   - [RoomIO](#71-roomio)
   - [RoomSensor](#72-roomsensor)
   - [TempOutBoard](#73-tempoutboard)
   - [RoomIR](#74-roomir)
8. [Home Assistant Discovery](#8-home-assistant-discovery)
9. [Connection and Configuration](#9-connection-and-configuration)
10. [Quick Reference Cheatsheet](#10-quick-reference-cheatsheet)

---

## 1. Topic Structure

Every topic follows this pattern:

```
<prefix>/<device_name>/<category>/<key>
```

| Segment | Description | Example |
|---|---|---|
| `<prefix>` | Configured MQTT topic prefix, including trailing `/` | `majordomus/` |
| `<device_name>` | Device name as defined in `config.xml` | `living_room` |
| `<category>` | One of: `tele`, `evt`, `state` | `tele` |
| `<key>` | Specific property name | `temperature0` |

**Full example:**
```
majordomus/living_room/tele/temperature0
```

---

## 2. Topic Categories

| Category | Trigger | Retained | Purpose |
|---|---|---|---|
| `tele` | Periodic polling (every RS-485 poll cycle) | **Yes** | Sensor measurements |
| `evt` | On-change only | **No** | Events: button presses, motion |
| `state` | On change | **Yes** | Device metadata and output states |

---

## 3. QoS and Retain Policy

- **QoS:** `0` (at most once) for all messages
- **Retain:**
  - `tele/` → `true`
  - `state/` → `true`
  - `evt/` → `false`
  - Home Assistant discovery → `true`

---

## 4. Sending Commands

To control a device, publish to:

```
<prefix>/<device_name>/cmd/<command_key>
```

**Payload:** plain UTF-8 string (numeric value or string constant)

The gateway subscribes to `<prefix>/#` to receive all commands under the prefix.

**Command routing:**
- Topic must have at least 4 levels
- Level `[2]` must be exactly `cmd`
- Level `[1]` is the device name
- Level `[3]` is the command key
- Payload is the command value

**Example — turn on digital output 0 on device `living_room`:**
```
Topic:   majordomus/living_room/cmd/do0
Payload: 1
```

---

## 5. Availability

Every device publishes its online status to:

```
<prefix>/<device_name>/state/online
```

| Payload | Meaning |
|---|---|
| `online` | Device is responding to RS-485 polls |
| `offline` | No response for more than 3 seconds |

- Retained: **Yes**
- This topic is used as `availability_topic` in Home Assistant discovery configs.

---

## 6. Sensor Value Conventions

### Payload format

All payloads are UTF-8 encoded strings.

| Data type | Example payload |
|---|---|
| Float | `22.5` |
| Integer | `420` |
| Unavailable sensor | `NaN` |
| JSON array | `[25.1, 25.3, ...]` |

### NaN sentinel

The firmware uses `INT16_MIN` (`-32768`) to indicate that a sensor is not available
(hardware not connected, read error, etc.).
The gateway converts this value to the string `"NaN"` before publishing.

**Rule for consumers:** If the payload is `"NaN"`, the reading should be treated as unavailable/unknown.

### Scaled values

Some devices (e.g., TempOutBoard) transmit raw integer values that must be divided by a scaling factor.
This conversion is done by the gateway before publishing — consumers always receive the final scaled float.

### Apparent temperature

When both `temperature0` (key `t0`) and `humidity` (key `rh`) are valid,
the gateway automatically calculates and publishes an apparent ("feels like") temperature using the Steadman formula:

```
e  = (rh / 100) × 6.105 × exp(17.27 × T / (237.7 + T))
AT = T + 0.33 × e − 4.00
```

Published to: `<prefix>/<device_name>/tele/apparentTemperature`

---

## 7. Device Types and Topic Maps

### 7.1 RoomIO

General-purpose I/O module with temperature sensors, digital inputs/outputs, analog inputs, and pulse counters.

#### Published — `tele/` (retained)

| Topic key | Unit | Type | Notes |
|---|---|---|---|
| `temperature0` | °C | float | Sensor 0; `NaN` if unavailable |
| `temperature1` | °C | float | Sensor 1; `NaN` if unavailable |
| `temperature2` | °C | float | Sensor 2 (optional); `NaN` if unavailable |
| `humidity` | % | float | Relative humidity; `NaN` if unavailable |
| `voc` | index | integer | VOC air quality index; `NaN` if unavailable |
| `co2` | ppm | integer | CO₂ concentration; `NaN` if unavailable |
| `illuminance` | lux | integer | Ambient light; `NaN` if unavailable |
| `distance` | unit | float | Distance sensor; `NaN` if unavailable |
| `analog0` | V | float | ADC channel 0 |
| `analog1` | V | float | ADC channel 1 |
| `counter0` – `counter7` | — | integer | Pulse counters 0–7 |
| `input0` – `input7` | — | `0`/`1` | Digital input states (decoded from bitfield) |
| `apparentTemperature` | °C | float | Calculated; published when `temperature0` and `humidity` are valid |

#### Published — `evt/` (not retained)

| Topic key | Type | Trigger |
|---|---|---|
| `button0` – `button7` | `0`/`1` | Published on button state change (decoded from bitfield) |

#### Published — `state/` (retained)

| Topic key | Type | Notes |
|---|---|---|
| `version` | string | Firmware version string |
| `power` | V | Supply voltage |
| `powerOut` | V | Output supply voltage |
| `online` | `online`/`offline` | Device availability |

#### Commands — `cmd/` (subscribe)

| Command key | Payload | Effect |
|---|---|---|
| `do0` – `do7` | `0` or `1` | Set digital output state |
| `dac0`, `dac1` | `0`–`255` | Set DAC/PWM analog output level |
| `setCnt0` – `setCnt7` | integer string | Preset pulse counter value |
| `reboot` | any | Reboot the device |

---

### 7.2 RoomSensor

Room sensor unit with temperature, humidity, air quality, motion, light, and noise sensors,
plus capacitive touch buttons and optional heating/lighting outputs.

#### Published — `tele/` (retained)

| Topic key | Unit | Type | Notes |
|---|---|---|---|
| `temperature0` – `temperature3` | °C | float | Up to 4 temperature sensors; `NaN` if unavailable |
| `humidity` | % | float | Relative humidity; `NaN` if unavailable |
| `voc` | index | integer | VOC index (Sensirion SGP40/41); `NaN` if unavailable |
| `nox` | index | integer | NOx index (Sensirion SGP41); `NaN` if unavailable |
| `co2` | ppm | integer | CO₂ concentration; `NaN` if unavailable |
| `illuminance` | lux | integer | Ambient light (VEML7700); `NaN` if unavailable |
| `noise` | dB | integer | Ambient noise level; `NaN` if unavailable |
| `analog0`, `analog1` | V | float | ADC channels |
| `input0` – `input3` | — | `0`/`1` | Digital input states |
| `apparentTemperature` | °C | float | Calculated; published when `temperature0` and `humidity` are valid |

#### Published — `evt/` (not retained)

| Topic key | Type | Trigger |
|---|---|---|
| `motion` | `0`/`1` | Motion detector (PIR) state change |
| `lastMotion` | ISO datetime string | Timestamp of last motion event |
| `button0` – `button3` | `0`/`1` | Capacitive touch button state change |

#### Published — `state/` (retained)

| Topic key | Type | Notes |
|---|---|---|
| `version` | string | Firmware version |
| `power` | V | Supply voltage |
| `powerOut` | V | Output supply voltage |
| `requestedTemperature` | °C | Current setpoint (floor heating / HVAC) |
| `online` | `online`/`offline` | Device availability |

#### Commands — `cmd/` (subscribe)

| Command key | Payload | Effect |
|---|---|---|
| `do0` – `do3` | `0` or `1` | Set digital output |
| `dac0`, `dac1` | `0`–`255` | Set DAC output level |
| `beep` | integer | Trigger piezo beep (duration or pattern code) |
| `reqT` | float `10`–`35` | Set requested temperature setpoint |
| `light` | `0`–`100` | Set light level (%) |
| `reboot` | any | Reboot the device |

---

### 7.3 TempOutBoard

Outdoor temperature board with up to 8 temperature sensors (DS18B20) and digital outputs.

#### Published — `tele/` (retained)

| Topic key | Unit | Type | Notes |
|---|---|---|---|
| `temperature0` – `temperature7` | °C | float | DS18B20 sensors; `NaN` if unavailable |

#### Published — `state/` (retained)

| Topic key | Type | Notes |
|---|---|---|
| `version` | string | Firmware version |
| `power` | V | Supply voltage |
| `powerOut` | V | Output supply voltage |
| `online` | `online`/`offline` | Device availability |

#### Commands — `cmd/` (subscribe)

| Command key | Payload | Effect |
|---|---|---|
| `do0` – `do9` | `0` or `1` | Set digital output |
| `ro` | `0`–`255` | Set resistor/PWM output level |

---

### 7.4 RoomIR

Thermal infrared camera module (MLX90640, 32×24 pixels).

#### Published — `tele/` (retained)

| Topic key | Type | Notes |
|---|---|---|
| `irImage` | JSON array string | 768 float values (32×24 pixels) representing temperature in °C |

**IR image format:**
```json
[25.1, 25.3, 24.8, 26.0, ...]
```
- Array length: **768 elements** (32 columns × 24 rows)
- Row-major order, top-left first
- Values in °C (float)
- Raw bytes from device are received as base64-encoded RS-485 chunks,
  assembled in memory, scaled by the device's resolution factor,
  then published as a single JSON array string.

#### Published — `state/` (retained)

| Topic key | Type | Notes |
|---|---|---|
| `version` | string | Firmware version |
| `resolution` | float | Scaling factor used for raw→°C conversion |
| `offset` | integer | Byte offset (internal assembly parameter) |
| `online` | `online`/`offline` | Device availability |

---

## 8. Home Assistant Discovery

When the gateway connects to the broker, it automatically publishes
MQTT discovery messages for all configured devices.
This allows Home Assistant to auto-configure entities without manual YAML.

### Discovery topic format

```
<ha_prefix>/<entity_type>/<unique_id>/config
```

| Segment | Example |
|---|---|
| `<ha_prefix>` | `homeassistant` (configured separately from MQTT prefix) |
| `<entity_type>` | `sensor`, `binary_sensor`, `switch`, `number` |
| `<unique_id>` | `living_room_t0` |

### Discovery payload (JSON, retained)

```json
{
  "name": "temperature0",
  "unique_id": "living_room_t0",
  "state_topic": "majordomus/living_room/tele/temperature0",
  "unit_of_measurement": "°C",
  "device_class": "temperature",
  "state_class": "measurement",
  "availability_topic": "majordomus/living_room/state/online",
  "payload_available": "online",
  "payload_not_available": "offline",
  "device": {
    "identifiers": ["living_room"],
    "manufacturer": "Majordomus",
    "model": "RoomSensor",
    "name": "living_room"
  }
}
```

### Re-publish trigger

Discovery configs are re-published on every MQTT reconnect
(`connectComplete` callback) to handle broker restarts.

---

## 9. Connection and Configuration

### Broker URL formats

| Scheme | Description |
|---|---|
| `tcp://host:port` | Plain TCP (default port: 1883) |
| `ssl://host:port` | TLS/SSL (default port: 8883) |

### Connection parameters

| Parameter | Value |
|---|---|
| MQTT version | 3.1.1 |
| QoS (all messages) | 0 |
| Connection timeout | 30 s |
| Keep-alive interval | 5 s |
| Automatic reconnect | Yes |

### SSL/TLS options

| Setting | Description |
|---|---|
| Default CA | Uses system Java TrustStore |
| Self-signed CA | Path to a PEM-encoded CA certificate file |

### config.xml structure

```xml
<MQTT>
  <broker
    address="tcp://broker.example.com:1883"
    username="user"
    passwd="password"
    topic="majordomus/"
    selfsigned="false"
    cert="/path/to/ca.crt"
  />
</MQTT>

<HomeAssistant>
  <settings
    enable="true"
    topic="homeassistant/"
  />
</HomeAssistant>
```

---

## 10. Quick Reference Cheatsheet

```
READ sensor value:
  Subscribe: <prefix>/<device>/tele/<key>
  Subscribe: <prefix>/<device>/state/<key>

LISTEN for events:
  Subscribe: <prefix>/<device>/evt/<key>

SEND command:
  Publish:   <prefix>/<device>/cmd/<key>   payload: <value>

CHECK availability:
  Subscribe: <prefix>/<device>/state/online   → "online" | "offline"

WILDCARD (all devices, all data):
  Subscribe: <prefix>/#
```

### Common sensor keys across device types

| MQTT key | Description | Unit |
|---|---|---|
| `tele/temperature0` | Primary temperature | °C |
| `tele/humidity` | Relative humidity | % |
| `tele/voc` | VOC air quality index | — |
| `tele/co2` | CO₂ concentration | ppm |
| `tele/illuminance` | Ambient light | lux |
| `tele/noise` | Ambient noise | dB |
| `tele/apparentTemperature` | Feels-like temperature | °C |
| `evt/motion` | Motion detection | `0`/`1` |
| `evt/button0` | Button 0 press | `0`/`1` |
| `state/online` | Availability | `online`/`offline` |
| `state/version` | Firmware version | string |
| `cmd/do0` | Digital output 0 | `0`/`1` |
| `cmd/reboot` | Reboot device | any |

---

*Generated from MajordomusControl source code analysis.*

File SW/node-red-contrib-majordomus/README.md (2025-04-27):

# Majordomus for node-red

## Light

The Light node allows control your light with buttons, presense senor and luxmeter. The node supports ON/OFF or dimmable light.

### Features
- Control with buttons (toggle output)
- Automatic turn on the light on motion
- Automatic on only in night based on luxmeter
- Automatic turn off the light after no presense timeout
- Fade in and fade out for dimmable lights

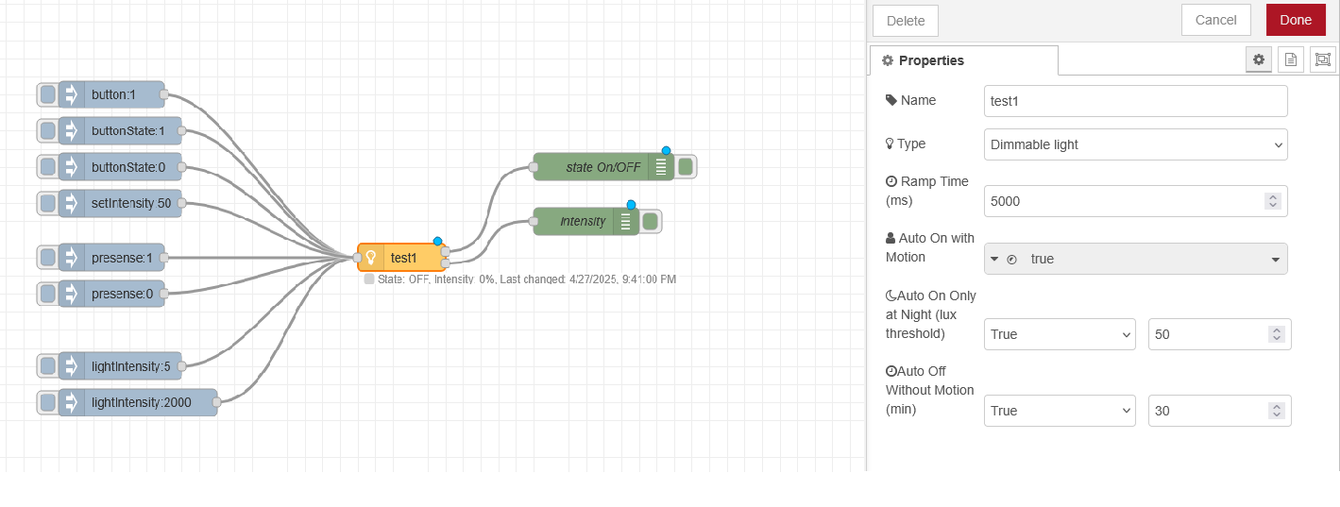
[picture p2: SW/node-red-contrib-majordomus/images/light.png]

Scheduler

## Scheduler

The Scheduler node allows you to configure time-based rules to control your application.

### Features
- Define rules for specific days or day ranges.
- Set start and end times for each rule.
- Assign a value to output during active periods.
- Visualize rules in a weekly schedule preview.

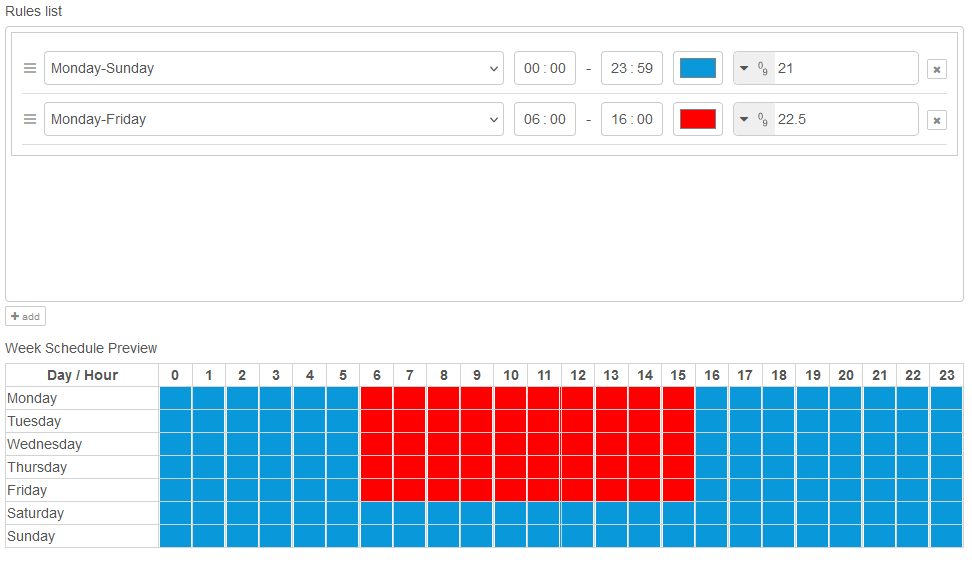
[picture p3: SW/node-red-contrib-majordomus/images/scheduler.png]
Scheduler

Scheduler

### Configuration Options

### Name
Specify a unique name for the node.

### Rules List
Manage a list of time-based rules:
- **Day Range**: Select specific days or day ranges (e.g., Monday-Sunday).
- **Start Time**: Define when the rule becomes active.
- **End Time**: Define when the rule becomes inactive.
- **Value**: Set the value to output during the active period.
- **Color**: Assign a color to visualize the rule in the preview table.

### Outputs
The node outputs a value defined in the rules when the current time falls within a rule's active period.

##### Examples

### Workday Schedule
- **Day Range**: Monday-Friday
- **Time**: 09:00 - 17:00
- **Output Value**: "Working Hours"

### Weekend Relaxation
- **Day Range**: Saturday-Sunday
- **Time**: 10:00 - 22:00
- **Output Value**: "Relaxing"

### Status Indicators
- **Green dot**: Indicates an active rule is being executed.
- **Gray ring**: No active rules match the current time.

## More Information
Visit the [project's GitHub repository](https://github.com/jirihusak/majordomus) or (https://www.majordomus.tech)

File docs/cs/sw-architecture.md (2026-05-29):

# Architektura software

Softwarová vrstva systému Majordomus běží na nízkoenergetickém počítači (typicky Raspberry Pi). Celý systém je navržen tak, aby byl spolehlivý, otevřený, snadno rozšiřitelný a **nezávislý na cloudu** — vše běží lokálně u vás doma.

---

## Majordomus Control

Jádro celého systému. Majordomus Control je most mezi fyzickým hardwarem a světem aplikací.

- Komunikuje přímo s HW jednotkami po sběrnici RS-485
- Překládá zprávy mezi jednotkami a **MQTT** protokolem
- Řídí konfiguraci, aktualizaci firmware a diagnostiku jednotek
- Poskytuje **webové rozhraní** pro konfiguraci a servis
- Běží na Raspberry Pi nebo jakémkoliv jiném PC s Linuxem/Windows

!!! info "Majordomus Control je jediný software, který potřebujete od Majordomu"
    Vše ostatní — MQTT broker, Node-RED, Home Assistant — jsou standardní open-source nástroje, které si nainstalujete sami podle svých potřeb.

---

## MQTT Broker

Komunikační páteř mezi Majordomus Control a všemi aplikacemi. Doporučujeme [Eclipse Mosquitto](https://mosquitto.org/) — lehký, spolehlivý a ověřený miliony instalací po celém světě.

- Slouží jako komunikační vrstva mezi Majordomus Control a aplikacemi třetích stran
- Umožňuje integraci s Home Assistant, Node-RED, openHAB a dalšími
- Standardní protokol — jakýkoliv software s podporou MQTT se dokáže připojit

---

## Aplikace pro automatizaci

Majordomus vám nediktuje, jaký software máte používat. Díky MQTT si zvolíte to, co vám vyhovuje:

### Node-RED

Vizuální programovací nástroj pro tvorbu automatizací. Ideální pro řízení klíčových funkcí domu — topení, osvětlení, žaluzie, ventilace. Logiku vytváříte přetahováním bloků, bez nutnosti psát kód.

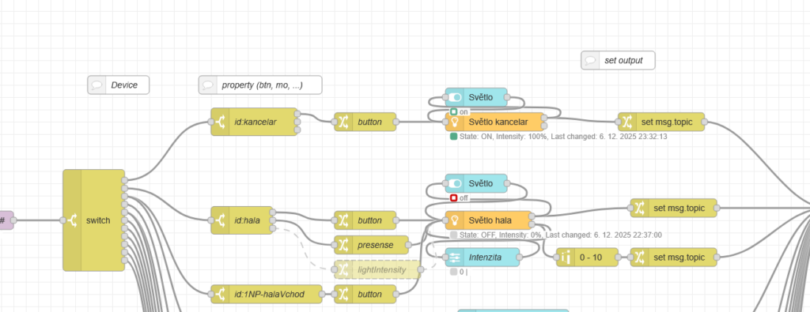
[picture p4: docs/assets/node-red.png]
Majordomus COntrol Web interface


### Home Assistant

Populární platforma pro chytrou domácnost. Slouží jako uživatelské rozhraní — mobilní aplikace, dashboardy, hlasové ovládání. Umožňuje také integraci s dalšími zařízeními mimo Majordomus (televize, FVE, elektromobil, meteostanice a stovky dalších).

### Jiný software

Díky otevřenému MQTT rozhraní můžete použít jakýkoliv systém, který MQTT podporuje — openHAB, Domoticz, vlastní skripty v Pythonu nebo cokoliv dalšího.

---

## Jak spolu jednotlivé vrstvy komunikují

```mermaid
graph LR
    HW[HW jednotky] -->|RS-485| MC[Majordomus Control]
    MC -->|MQTT| BR[MQTT Broker]
    BR -->|MQTT| NR[Node-RED]
    BR -->|MQTT| HA[Home Assistant]
    BR -->|MQTT| OTHER[Další software]
    NR -->|MQTT| BR
    HA -->|MQTT| BR
```

Komunikace je **obousměrná** — aplikace čtou data ze senzorů (teplota, pohyb, stav tlačítka) a zároveň posílají příkazy zpět do systému (rozsvítit světlo, spustit žaluzii, přepnout relé).

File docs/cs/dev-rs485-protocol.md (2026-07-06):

# Protokol RS-485

Referenční popis komunikace mezi jednotkami Majordomus a řídícím počítačem po sběrnici RS-485. Jednotky podporují dva protokoly:

- **ASCII protokol** — nativní protokol systému Majordomus, používá ho Majordomus Control
- **Modbus RTU** — standardní průmyslový protokol pro integraci s PLC a SCADA systémy

Anglické originály: [ASCII protokol](https://github.com/jirihusak/majordomus/blob/main/HW/Protocol%20Majordomus%20Rs-485%20ASCII.md) · [Modbus](https://github.com/jirihusak/majordomus/blob/main/HW/Protocol%20Majordomus%20Modbus.md)

---

## Parametry sériové linky

| Parametr | Hodnota |
|---|---|
| Rychlost | 115 200 bps |
| Datové bity | 8 |
| Stop bity | 1 |
| Parita | žádná |

Na sběrnici je jeden **master** (řídící počítač) — jednotky nikdy nevysílají samy od sebe, pouze odpovídají na dotaz. Každé zařízení má textové `id` o maximální délce 32 znaků.

```mermaid
sequenceDiagram
    Master->>Zařízení A: id:A,msg:data,crc:XX
    Zařízení A-->>Master: id:A,msg:data,crc:XX
    Master->>Zařízení B: id:B,msg:data,crc:XX
    Zařízení B-->>Master: id:B,msg:data,crc:XX
```

---

## ASCII protokol

### Formát zprávy

- Zpráva začíná `id:<název_zařízení>`.
- Končí znaky `CR LF`.
- Vlastnosti jsou odděleny čárkou, každá má formát `klíč:hodnota`.
- Poslední vlastností je vždy `crc` — [výpočet níže](#vypocet-crc).

### Příklady

**Čtení stavu zařízení** (verze FW, napájecí napětí):

```
→  id:test,msg:status,crc:8b\r\n
←  id:test,type:RoomSens,version:0.3(Nov  2 2024),pwr:12.05,pwrOut:12.11,crc:f0
```

**Čtení dat:**

```
→  id:test,msg:data,crc:ea
←  id:test,di:0,btn:0,t:210,t2:211,rh:540,mo:0,voc:95,lux:569,nl:278,adc0:0.00,adc1:0.00,crc:22
```

**Čtení a zápis v jedné zprávě** (digitální výstupy, DAC, přísvit, žádaná teplota):

```
→  id:test,msg:data,do:3,dac0:5.4,dac1:1.2,light:1,reqT:225,crc:93
←  id:test,di:0,btn:0,t:210,t2:211,rh:540,mo:0,voc:95,lux:569,nl:278,adc0:0.00,adc1:0.00,crc:22
```

**Změna id zařízení:**

```
→  id:test,msg:config,newId:test2,crc:ea
```

**Restart zařízení:**

```
→  id:test,msg:config,cmd:reset,crc:07
```

!!! tip "Neznám id zařízení"
    Místo názvu zařízení lze použít `all` — zprávu pak zpracují všechna zařízení na sběrnici. Aby nedošlo ke kolizi, každé zařízení před odpovědí čeká náhodnou dobu. Pro běžný provoz se to nedoporučuje, hodí se pro prvotní zjištění zařízení na lince.

### Zpráva `status`

```
id:<zařízení>,msg:status,...
```

| Odpověď | Význam |
|---|---|
| `type` | Typ zařízení (např. `RoomSens`) |
| `version` | Verze FW: `X.Y (datum sestavení)` |
| `pwr` | Napájecí napětí ve voltech |
| `pwrOut` | Napájecí napětí za pojistkou vstupů/výstupů |

### Zpráva `config`

```
id:<zařízení>,msg:config,...
```

| Klíč | Význam |
|---|---|
| `newId` | Změna id na nový řetězec (max. 32 znaků) |
| `newId5050` | Jako `newId`, ale zařízení příkaz provede s pravděpodobností 50 % — řeší situaci, kdy mají dvě zařízení na sběrnici stejné id |
| `cmd:reset` | Restart zařízení |

### Zpráva `data` — RoomIO

| Ze zařízení | Význam |
|---|---|
| `adc0`, `adc1` | Napětí analogových vstupů |
| `di` | Bitové pole digitálních vstupů |
| `btn` | Bitové pole tlačítek — posílá se jednou při náběžné hraně |
| `t0`, `t1` | Teploty z 1-Wire senzorů (°C) |

| Do zařízení | Význam |
|---|---|
| `dac0`, `dac1` | Nastavení analogových výstupů |
| `do` | Bitové pole digitálních výstupů (bit 0 = výstup 0, ...) |

### Zpráva `data` — RoomSensor

| Ze zařízení | Význam |
|---|---|
| `adc0`, `adc1` | Napětí analogových vstupů |
| `di` | Bitové pole digitálních vstupů |
| `btn` | Bitové pole tlačítek — posílá se jednou při náběžné hraně |
| `t0` | Teplota z předního krytu (°C) |
| `t1` | Teplota ze senzoru vlhkosti (°C) |
| `t2`, `t3` | Teploty z 1-Wire senzorů (°C) |
| `rh` | Relativní vlhkost (%) |
| `mo` | PIR detektor pohybu (`0`/`1`) |
| `voc` | Kvalita vzduchu VOC (0–500) |
| `lux` | Intenzita osvětlení (lux) |
| `nl` | Hladina hluku (dB) |
| `newReqT` | Nová žádaná teplota zadaná uživatelem na displeji — posílá se jednou při potvrzení |

| Do zařízení | Význam |
|---|---|
| `dac0`, `dac1` | Nastavení analogových výstupů |
| `do` | Bitové pole digitálních výstupů |
| `reqT` | Žádaná teplota zobrazená na LCD |
| `beep` | Spuštění pípání (0–4) |
| `light` | Ovládání LED přísvitu (`0`/`1`) |

### Zpráva `data` — TinySensor

| Ze zařízení | Význam |
|---|---|
| `di` | Bitové pole digitálních vstupů |
| `btn` | Bitové pole tlačítek |
| `t0` | Teplota (°C) |
| `rh` | Relativní vlhkost (%) |
| `t1`, `t2` | Teploty z 1-Wire senzorů (°C) |

| Do zařízení | Význam |
|---|---|
| `do` | Bitové pole digitálních výstupů |

!!! note "Formát číselných hodnot"
    Teploty a vlhkost se po sběrnici posílají jako celá čísla ×10 — např. `t:210` znamená 21,0 °C, `rh:540` znamená 54,0 %.

### Výpočet CRC

Kontrolní součet je CRC-8 počítaný tabulkou z celé zprávy před vlastností `crc`:

```c
static unsigned char const crc8_table[] = {
    0xea, 0xd4, 0x96, 0xa8, 0x12, 0x2c, 0x6e, 0x50, 0x7f, 0x41, 0x03, 0x3d,
    0x87, 0xb9, 0xfb, 0xc5, 0xa5, 0x9b, 0xd9, 0xe7, 0x5d, 0x63, 0x21, 0x1f,
    0x30, 0x0e, 0x4c, 0x72, 0xc8, 0xf6, 0xb4, 0x8a, 0x74, 0x4a, 0x08, 0x36,
    0x8c, 0xb2, 0xf0, 0xce, 0xe1, 0xdf, 0x9d, 0xa3, 0x19, 0x27, 0x65, 0x5b,
    0x3b, 0x05, 0x47, 0x79, 0xc3, 0xfd, 0xbf, 0x81, 0xae, 0x90, 0xd2, 0xec,
    0x56, 0x68, 0x2a, 0x14, 0xb3, 0x8d, 0xcf, 0xf1, 0x4b, 0x75, 0x37, 0x09,
    0x26, 0x18, 0x5a, 0x64, 0xde, 0xe0, 0xa2, 0x9c, 0xfc, 0xc2, 0x80, 0xbe,
    0x04, 0x3a, 0x78, 0x46, 0x69, 0x57, 0x15, 0x2b, 0x91, 0xaf, 0xed, 0xd3,
    0x2d, 0x13, 0x51, 0x6f, 0xd5, 0xeb, 0xa9, 0x97, 0xb8, 0x86, 0xc4, 0xfa,
    0x40, 0x7e, 0x3c, 0x02, 0x62, 0x5c, 0x1e, 0x20, 0x9a, 0xa4, 0xe6, 0xd8,
    0xf7, 0xc9, 0x8b, 0xb5, 0x0f, 0x31, 0x73, 0x4d, 0x58, 0x66, 0x24, 0x1a,
    0xa0, 0x9e, 0xdc, 0xe2, 0xcd, 0xf3, 0xb1, 0x8f, 0x35, 0x0b, 0x49, 0x77,
    0x17, 0x29, 0x6b, 0x55, 0xef, 0xd1, 0x93, 0xad, 0x82, 0xbc, 0xfe, 0xc0,
    0x7a, 0x44, 0x06, 0x38, 0xc6, 0xf8, 0xba, 0x84, 0x3e, 0x00, 0x42, 0x7c,
    0x53, 0x6d, 0x2f, 0x11, 0xab, 0x95, 0xd7, 0xe9, 0x89, 0xb7, 0xf5, 0xcb,
    0x71, 0x4f, 0x0d, 0x33, 0x1c, 0x22, 0x60, 0x5e, 0xe4, 0xda, 0x98, 0xa6,
    0x01, 0x3f, 0x7d, 0x43, 0xf9, 0xc7, 0x85, 0xbb, 0x94, 0xaa, 0xe8, 0xd6,
    0x6c, 0x52, 0x10, 0x2e, 0x4e, 0x70, 0x32, 0x0c, 0xb6, 0x88, 0xca, 0xf4,
    0xdb, 0xe5, 0xa7, 0x99, 0x23, 0x1d, 0x5f, 0x61, 0x9f, 0xa1, 0xe3, 0xdd,
    0x67, 0x59, 0x1b, 0x25, 0x0a, 0x34, 0x76, 0x48, 0xf2, 0xcc, 0x8e, 0xb0,
    0xd0, 0xee, 0xac, 0x92, 0x28, 0x16, 0x54, 0x6a, 0x45, 0x7b, 0x39, 0x07,
    0xbd, 0x83, 0xc1, 0xff};

uint8_t crc8(uint8_t seed, unsigned char const *data, size_t len)
{
    uint8_t crc = seed;
    if (data == NULL)
        return 0;
    crc &= 0xff;
    unsigned char const *end = data + len;
    while (data < end)
        crc = crc8_table[crc ^ *data++];
    return crc;
}
```

---

## Modbus

Jednotky podporují i standardní protokol **Modbus RTU** se stejnými parametry sériové linky. Každé zařízení má Modbus adresu 1–247.

### Registry — RoomSensor

| Logická adresa | Registr | Přístup | Velikost | Typ | Význam |
|--|--|--|--|--|--|
| 0x41001 | 0x1000 | čtení | 2 B | INT16 | Teplota z předního krytu [×10 °C] |
| 0x41002 | 0x1001 | čtení | 2 B | INT16 | Teplota ze senzoru vlhkosti [×10 °C] |
| 0x41003 | 0x1002 | čtení | 2 B | UINT16 | Relativní vlhkost [×10 %] |
| 0x41004 | 0x1003 | čtení | 2 B | INT16 | Teplota z 1-Wire senzoru 0 [×10 °C] |
| 0x41005 | 0x1004 | čtení | 2 B | INT16 | Teplota z 1-Wire senzoru 1 [×10 °C] |
| 0x41006 | 0x1005 | čtení | 2 B | UINT16 | Kvalita vzduchu VOC index [0–500] |
| 0x41007 | 0x1006 | čtení | 2 B | UINT16 | CO₂ [ppm] |
| 0x41008 | 0x1007 | čtení | 4 B | UINT32 | Intenzita osvětlení [lux] |
| 0x4100A | 0x1009 | čtení | 2 B | UINT16 | Hladina hluku [dB] |
| 0x4100B | 0x100A | čtení | 2 B | UINT16 | PIR detektor pohybu [0/1] |
| 0x4100C | 0x100B | čtení | 2 B | UINT16 | Bitové pole digitálních vstupů |
| 0x4100D | 0x100C | čtení | 2 B | UINT16 | Bitové pole tlačítek (náběžná hrana) |
| 0x4100E | 0x100D | čtení | 2 B | UINT16 | ADC0 — napětí analogového vstupu [mV] |
| 0x4100F | 0x100E | čtení | 2 B | UINT16 | ADC1 — napětí analogového vstupu [mV] |
| 0x41010 | 0x100F | čtení | 2 B | UINT16 | Napájecí napětí [mV] |
| 0x41011 | 0x1010 | čtení | 2 B | UINT16 | Napájecí napětí výstupů [mV] |
| 0x62001 | 0x2000 | zápis | 2 B | UINT16 | Bitové pole digitálních výstupů |
| 0x62002 | 0x2001 | zápis | 2 B | UINT16 | DAC0 — analogový výstup [mV] |
| 0x62003 | 0x2002 | zápis | 2 B | UINT16 | DAC1 — analogový výstup [mV] |
| 0x62004 | 0x2003 | zápis | 2 B | UINT16 | Pípák [0–4] |
| 0x62005 | 0x2004 | zápis | 2 B | UINT16 | LED přísvit [0/1] |
| 0x62006 | 0x2005 | zápis | 2 B | INT16 | Žádaná teplota na LCD [×10 °C] |

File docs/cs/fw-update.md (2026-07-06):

# Aktualizace firmware

Všechny jednotky Majordomus podporují **aktualizaci firmware přímo po sběrnici RS-485**. Nemusíte nic demontovat ze zdi, nepotřebujete programátor — nový firmware nahrajete z webového rozhraní Majordomus Control a jednotka se aktualizuje na dálku.

Jak to funguje: každá jednotka obsahuje kromě aplikačního firmware i **zavaděč (bootloader)**, který se stará o přijetí nového firmware po sběrnici. Majordomus Control rozparsuje soubor `.hex`, po blocích ho odešle jednotce a po dokončení jednotku restartuje do nové aplikace.

---

## 1. Stažení firmware

Aktuální soubory firmware najdete na GitHubu v sekci Releases pod tagem **FW**:

→ [github.com/jirihusak/majordomus/releases](https://github.com/jirihusak/majordomus/releases)

Např. `RoomSens.v0.2.hex` pro RoomSensor nebo `RoomIO.v0.2.hex` pro RoomIO.

---

## 2. Umístění souborů do složky `updateFW`

Majordomus Control hledá firmware ve složce `updateFW` ve svém pracovním adresáři (u klasické instalace tedy typicky `~/majordomus/updateFW`). Uvnitř vytvořte podsložku **s přesným názvem typu zařízení** a do ní vložte soubor `.hex`:

```
~/majordomus/
├── config.xml
└── updateFW/
    ├── RoomSensor/
    │   └── RoomSens.v0.2.hex
    └── RoomIO/
        └── RoomIO.v0.2.hex
```

Název podsložky musí odpovídat typu zařízení tak, jak je uveden v konfiguraci:

| Typ zařízení | Název složky |
|---|---|
| RoomSensor | `updateFW/RoomSensor/` |
| RoomIO | `updateFW/RoomIO/` |
| BoxIO | `updateFW/BoxIO/` |
| TempOutBoard | `updateFW/TempOutBoard/` |
| RoomIR | `updateFW/RoomIR/` |

!!! note "Instalace v Dockeru"
    Pracovní adresář aplikace v kontejneru je `/app`. Přimapujte složku s firmwarem jako volume v `docker-compose.yml`:

    ```yaml
    volumes:
      - ./majordomus:/config
      - ./updateFW:/app/updateFW
    ```

---

## 3. Spuštění aktualizace

1. Otevřete webové rozhraní Majordomus Control (`http://<IP_ADRESA>:8899`).
2. Přejděte do sekce **Firmware Update**.
3. V poli **Device** vyberte jednotku, kterou chcete aktualizovat — nabídka firmware se automaticky omezí na soubory odpovídající jejímu typu.
4. V poli **Select Firmware** vyberte verzi.
5. Klikněte na **Start Update** a sledujte průběh na ukazateli.

Během aktualizace je jednotka mimo provoz (neodpovídá na dotazy, výstupy drží poslední stav). Aktualizace trvá řádově desítky sekund až jednotky minut.

!!! warning "Během aktualizace"
    Neodpojujte napájení jednotky ani převodník RS-485 a nerestartujte Majordomus Control. Pokud se aktualizace přesto přeruší, jednotka zůstane v zavaděči — nic se neztratí, aktualizaci jednoduše spusťte znovu.

---

## 4. Ověření

Po dokončení se jednotka restartuje do nového firmware. Verzi ověříte:

- ve **webovém rozhraní** Majordomus Control v detailu zařízení, nebo
- přes MQTT v tématu `<prefix>/<zařízení>/state/version`.

Verze obsahuje číslo a datum sestavení, např. `0.3(Nov  2 2024)`.

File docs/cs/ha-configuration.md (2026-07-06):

# Konfigurace Home Assistant

Po instalaci zbývají dva kroky: nastavit doplněk Majordomus a propojit Home Assistant s MQTT brokerem. Poté se všechna zařízení Majordomus objeví v Home Assistantu automaticky.

---

## Konfigurace doplňku Majordomus

Nastavení najdete v **Nastavení → Aplikace → Majordomus → Konfigurace** (při instalaci přes Docker odpovídají tyto volby proměnným prostředí v `docker-compose.yml`).

| Volba | Výchozí hodnota | Význam |
|---|---|---|
| `mqtt_host` | `core-mosquitto` | Adresa MQTT brokeru. Výchozí hodnota ukazuje na doplněk Mosquitto v HAOS. |
| `mqtt_port` | `1883` | Port MQTT brokeru. |
| `mqtt_user` | *(prázdné)* | Uživatelské jméno pro MQTT. |
| `mqtt_password` | *(prázdné)* | Heslo pro MQTT. |
| `mqtt_topic` | `majordomus/` | Kořenové MQTT téma, pod kterým Majordomus publikuje data. |
| `ha_discovery` | `true` | Automatické ohlašování zařízení do Home Assistantu (auto-discovery). |
| `ha_topic` | `homeassistant/` | Téma pro auto-discovery — musí odpovídat nastavení MQTT integrace v HA (výchozí hodnotu neměňte). |

Po změně konfigurace doplněk restartujte.

!!! note "Nastavení HW jednotek"
    Sériové porty a seznam HW jednotek se nenastavují zde, ale ve webovém rozhraní Majordomus Control (položka **Majordomus** v bočním panelu). Podrobnosti v kapitole [Konfigurace SW](sw-configuration.md).

---

## Připojení Home Assistant k MQTT

Aby Home Assistant viděl data z Majordomu, musí se připojit ke stejnému MQTT brokeru:

1. Přejděte do **Nastavení → Zařízení a služby**.
2. Pokud používáte doplněk Mosquitto, Home Assistant broker sám objeví — stačí kliknout na **Konfigurovat** u nalezené integrace MQTT a potvrdit.
3. Jinak klikněte na **Přidat integraci**, vyhledejte **MQTT** a zadejte adresu brokeru, uživatelské jméno a heslo ručně.

!!! tip "Ověření komunikace"
    V integraci MQTT klikněte na **Konfigurovat → Naslouchat tématu** a zadejte `majordomus/#`. Pokud vše funguje, uvidíte proud zpráv z vašich jednotek.

---

## Auto-discovery — zařízení se objeví sama

Majordomus Control s povoleným `ha_discovery` ohlašuje všechna zařízení automaticky. V **Nastavení → Zařízení a služby → integrace MQTT** se objeví každá HW jednotka jako samostatné zařízení se všemi svými entitami:

- **RoomSensor** — teplota, vlhkost, CO₂, VOC, osvětlení, hluk, pohyb, tlačítka, stmívání světel
- **RoomIO / BoxIO** — digitální vstupy a výstupy, relé

Žádné YAML soubory, žádná ruční konfigurace entit. Přidáte-li později novou jednotku v Majordomus Control, v Home Assistantu se objeví sama.

---

## Dashboard a mobilní aplikace

Jakmile jsou entity v Home Assistantu, můžete je začít používat:

- **Dashboard** — v **Nastavení → Dashboardy** vytvořte přehled domu; entity Majordomus přidáváte jako jakékoliv jiné (karty s teplotou, grafy, přepínače světel...).
- **Mobilní aplikace** — nainstalujte [Home Assistant Companion](https://companionapp.home-assistant.io/) pro Android nebo iOS a ovládejte dům odkudkoliv.
- **Historie** — data ze všech senzorů se automaticky ukládají; grafy najdete u každé entity nebo v záložce **Historie**.

!!! tip "Automatizace: Home Assistant, nebo Node-RED?"
    Jednoduché automatizace (notifikace na mobil, rozsvícení při pohybu) zvládne Home Assistant sám v **Nastavení → Automatizace**. Kritickou logiku domu — topení, žaluzie, ventilaci — doporučujeme držet v [Node-RED](sw-node-red.md), který běží nezávisle na Home Assistantu.

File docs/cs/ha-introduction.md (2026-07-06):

# Home Assistant

## Co je Home Assistant?

Home Assistant je nejpopulárnější open-source platforma pro chytrou domácnost na světě. Běží lokálně u vás doma, funguje bez cloudu a podporuje **tisíce integrací** — od světel a termostatů přes televize a fotovoltaiku až po elektromobily.

Kolem Home Assistantu existuje obrovská komunita: pravidelné měsíční aktualizace, tisíce návodů a doplňků a aktivní fóra, kde najdete řešení téměř na cokoliv.

Home Assistant je open-source a zcela zdarma → [home-assistant.io](https://www.home-assistant.io/)

---

## Proč Home Assistant v chytrém domě?

V rámci chytré domácnosti slouží Home Assistant především jako **uživatelské rozhraní celého domu**:

- **Dashboardy** — přehled celého domu na jedné obrazovce: teploty, spotřeba, stav světel, žaluzií a topení.
- **Mobilní aplikace** — ovládání domu odkudkoliv, notifikace na mobil (pro Android i iOS).
- **Hlasové ovládání** — propojení s hlasovými asistenty.
- **Integrace třetích stran** — televize, fotovoltaika, elektromobil, meteostanice, chytré spotřebiče a stovky dalších zařízení mimo Majordomus.
- **Historie a grafy** — automatické ukládání a vizualizace dat ze všech senzorů.

---

## Home Assistant a Majordomus

V systému Majordomus má každý nástroj svou roli:

- **Majordomus Control** zajišťuje spolehlivý sběr a řízení dat na úrovni hardwaru (RS-485 → MQTT).
- **Node-RED** zpracovává kritickou logiku domu — topení, osvětlení, žaluzie.
- **Home Assistant** je výkladní skříň celého systému — dashboardy, mobilní aplikace a integrace s okolním světem.

```mermaid
graph LR
    HW[HW jednotky] -->|RS-485| MC[Majordomus Control]
    MC -->|MQTT| BR[MQTT Broker]
    BR -->|MQTT| HA[Home Assistant]
    HA --> APP[Mobilní aplikace / Dashboardy]
```

!!! tip "Auto-discovery — zařízení se objeví sama"
    Majordomus Control podporuje **MQTT auto-discovery**. Všechny senzory, spínače a další zařízení Majordomus se v Home Assistantu objeví automaticky — bez ruční konfigurace, bez psaní YAML souborů.

Home Assistant přitom není podmínkou — systém Majordomus funguje i bez něj. Pokud vám stačí Node-RED a jeho dashboard, Home Assistant instalovat nemusíte. Většina uživatelů ale ocení jeho mobilní aplikaci a snadnou tvorbu přehledných dashboardů.

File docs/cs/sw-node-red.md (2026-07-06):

# Node-RED

## Co je Node-RED?

Node-RED je vizuální nástroj pro tvorbu automatizací a logiky pomocí takzvaných „flow" (toků). Místo klasického programování skládáte jednotlivé funkční bloky (uzly) graficky a propojujete je mezi sebou. Každý uzel má jasně danou funkci — může přijímat data ze senzorů, zpracovávat je, vyhodnocovat podmínky nebo ovládat výstupy.

Výsledek? Přehledné automatizace, které zvládnete vytvořit i bez programátorských zkušeností. A pokud programovat umíte, můžete v jednotlivých uzlech psát vlastní funkce v JavaScriptu.

Node-RED je open-source a zcela zdarma → [nodered.org](https://nodered.org/)

Node-RED rozhraní

---

## Proč Node-RED v chytrém domě?

V rámci chytré domácnosti slouží Node-RED jako **centrální mozek automatizace**. Proudí do něj data ze senzorů — teplota, vlhkost, osvětlení, pohyb, spotřeby — a na jejich základě rozhoduje o akcích:

- Klesla teplota pod 20 °C? → Zapni topení.
- Nikdo není doma déle než 30 minut? → Zhasni všechna světla.
- Vlhkost v koupelně přesáhla 80 %? → Spusť ventilaci.
- Otevřelo se okno? → Vypni topení v dané místnosti.
- CO₂ přesáhl 1000 ppm? → Otevři rekuperaci.

Velkou výhodou je možnost snadno propojit různé technologie a protokoly (MQTT, HTTP, databáze, cloudové služby) na jednom místě.

---

## Node-RED a Majordomus

V systému Majordomus má každý nástroj svou roli:

- **Majordomus Control** zajišťuje spolehlivý sběr a řízení dat na úrovni hardwaru.
- **Node-RED** přebírá tato data a přidává jim smysl — propojuje informace ze senzorů s akcemi, přizpůsobuje chování domu konkrétním potřebám uživatele.

Automatizace tak můžete postupně rozšiřovat, upravovat a ladit **bez zásahu do firmware zařízení**. Přidáte nový senzor? Stačí přidat pár uzlů do flow. Chcete změnit logiku topení? Přepojíte bloky v prohlížeči. Žádné překládání kódu, žádné nahrávání firmware.

!!! tip "Deploy jedním kliknutím"
    Rozhraní Node-RED běží jako webová služba v prohlížeči. Změny v programu se nasadí kliknutím na tlačítko **Deploy** — okamžitě, bez restartu, bez složitého překládání a nahrávání.

---

## Instalace Node-RED

Na Raspberry Pi s Raspberry Pi OS:

```bash
bash <(curl -sL https://raw.githubusercontent.com/node-red/linux-installers/master/deb/update-nodejs-and-nodered)
```

Povolení automatického spouštění:

```bash
sudo systemctl enable nodered.service
sudo systemctl start nodered.service
```

Rozhraní bude dostupné na `http://<IP_ADRESA>:1880`.

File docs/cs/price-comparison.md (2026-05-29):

# Cenové srovnání

Představte si, že kupujete tričko. V obchodě máte tři možnosti: levné tričko za 50 Kč, které se po třech praních roztáhne. Kvalitní tričko za 500 Kč z poctivého materiálu, které vám vydrží roky. A značkové tričko za 1 500 Kč — stejný materiál jako to za 500, ale platíte za logo a krabičku.
Se systémy pro chytrou domácnost je to stejné.

Majordomus je jako to tričko za 500 Kč. Kvalitní komponenty, spolehlivá drátová komunikace, kompaktní návrh — ale bez příplatku za značku a uzavřený ekosystém. Platíte za reálnou hodnotu, ne za krabičku a logo.

Pojďme se podívat na příklad nákupu HW pro modelový dům s 5 zónami od různých výrobců.

## Modelový dům / byt s 5 zónami

Scénář: **5 místností**, v každé pokrýváme vnitřní klima, osvětlení, žaluzie a detekci přítomnosti, integrace s rekuperací, apod.

### Co potřebujeme v každé zóně

**Senzory (měření):** teplota + vlhkost, CO₂, intenzita osvětlení, pohybový senzor, 4 tlačítka na zdi, vstupy na záplavový senzor a okenní kontakty

**Akční členy (ovládání):** spínání 230VAC pro topné ventily, osvětlení, spínání žaluzií, ovládání výstupu 0-10V pro stmívání osvětlení

**Rozhraní pro integraci** Digitální rozhraní ModBus pro integraci rekuperace, klimatizace apod. zařízení třetích stran.

---

### Cena s využitím HW Loxone — 5 zón

| Komponenta | Ks | Cena/ks s DPH (Kč) | Celkem (Kč) |
|---|---|---|---|
| Centrální jednotka (miniserver) | 1 | 19 842 | 19 842 |
| Teplotní + vlhkostní senzor + CO₂ + tlačítka | 5 | 7 350 | 36 750 |
| PIR / přítomnostní senzor + intenzita osvětlení | 5 | 3 321 | 16 605|
| Vstupy níkonapěťové (okenní kontakty, záplavový senzor, tlačítka) | 5 | 2 478 | 12 390 |
| Výstupy 230 VAC (akční člen) | 2 | 10 222 | 20 444 |
| Ovládání AO (0-10V) | 2 | 8 202 | 16 404 |
| Rozhraní ModBus | 2 | 7577 | 15 154 |
| **Celkem** | | | **137 589** |

Cena vychází z oficiálních stránek shop.loxone.com, 2Q/26. V ceně není zahrnut projekt, instalace, SW apod. Cena je pouze za klíčové prvky HW.

---

### Levná asijská řešení ( ZigBee + logika na cloudu) — 5 zón

| Komponenta | Ks | Cena/ks (Kč) | Celkem (Kč) |
|---|---|---|---|
| ZigBee brána (Gateway) | 1 | 500 | 500 |
| Senzor teploty + vlhkosti (ZigBee) | 5 | 300 | 1 500 |
| Senzor CO₂ (ZigBee, většinou pouze eCO₂) | 5 | 1 200 | 6 000 |
| PIR pohybový senzor (ZigBee) | 5 | 250 | 1 250 |
| Senzor osvětlení (ZigBee) | 5 | 350 | 1 750 |
| Tlačítkový ovladač / scény (ZigBee) | 5 | 400 | 2 000 |
| Relé modul 230 V | 10 | 350 | 3 500 |
| **Celkem** | | | **16 500** |

Ceny z AliExpress, 2Q/26. Na první pohled nejlevnější varianta — ale je třeba počítat s tím, co v ceně není vidět:

- **5 krabiček na zeď v každé místnosti** — senzor T+RH, CO₂, PIR, lux a tlačítka jsou samostatná zařízení.
- **Bezdrátové spojení** — závislost na Wi-Fi/ZigBee, výpadky signálu, rušení.
- **Baterie** — většina senzorů běží na CR2450/CR2032, výměna každých 6–12 měsíců × 25 senzorů = nekonečný kolotoč.
- **eCO₂ ≠ CO₂** — levné senzory neměří skutečný CO₂, pouze odhadují z VOC. Přesnost je nesrovnatelná.
- **Žádná záruka dlouhodobé dostupnosti** — výrobce z AliExpressu může kdykoliv zmizet.
- **0–10 V výstupy** — v ZigBee ekosystému prakticky neexistují, nelze ovládat stmívání profesionálních svítidel.
- **Cloudová závislost** — většina Tuya zařízení vyžaduje cloudové připojení. Server vypnou = nefunguje.

---

### Cena s komponenty Majordomus

| Komponenta | Ks | Cena/ks (Kč) | Celkem (Kč) |
|---|---|---|---|
| Mini PC / Raspberry Pi + zdroj | 1 | 4 500 | 4 500 |
| RoomSensor (teplota, vlhkost, CO₂, VOC, světlo, PIR, 4 tlačítka — vše v 1 ks) | 5 | 5 900| 29 500|
| BoxIO (spínání 230 VAC výstupů, AO) | 4 | 3 500 | 14 000 |
| RS485 / ModBus převodník USB | 3 | 850 | 2 550 |
| **Celkem** | | | **50 550**|

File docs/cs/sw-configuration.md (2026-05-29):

# Konfigurace Majordomus Control

Veškerá konfigurace se provádí přes webové rozhraní na adrese `http://<IP_ADRESA>:8899`. Žádné ruční editování konfiguračních souborů není potřeba — vše nastavíte z prohlížeče.

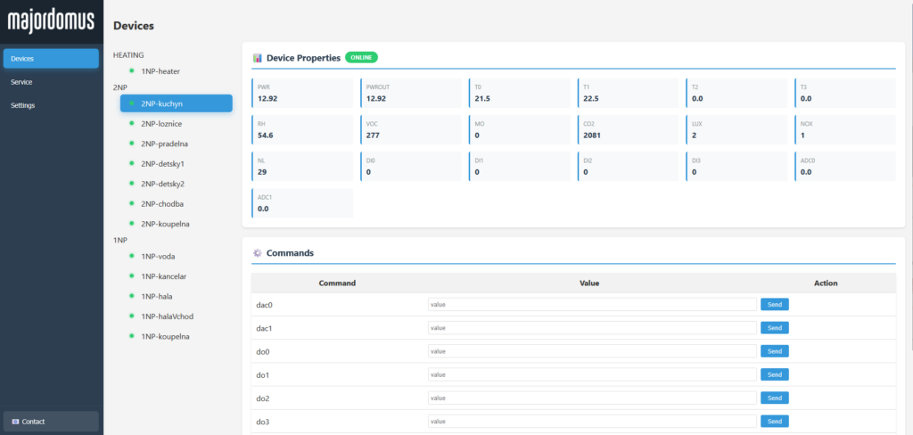
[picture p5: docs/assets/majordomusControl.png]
Webové rozhraní Majordomus Control


---

## MQTT Broker

Nastavení připojení k MQTT brokeru (Mosquitto), který slouží jako komunikační vrstva mezi Majordomus Control a aplikacemi (Node-RED, Home Assistant...).

- **IP adresa a port** — adresa MQTT brokeru (typicky `localhost:1883`, pokud běží na stejném zařízení)
- **Autentizace** — uživatelské jméno a heslo pro připojení
- **TLS certifikáty** — pro šifrovanou komunikaci v produkčním nasazení

---

## Home Assistant Integration

Povolí automatické odesílání konfiguračních informací o zařízeních Majordomus do Home Assistantu. Díky tomu se vaše senzory, spínače a další zařízení **automaticky objeví** v Home Assistantu bez nutnosti ruční konfigurace.

!!! tip "Auto-discovery"
    Po povolení této integrace stačí v Home Assistantu přejít do Nastavení → Zařízení a služby — vaše Majordomus jednotky se tam samy zobrazí.

---

## Serial Connections

Nastavení sériových portů, na kterých jsou připojeny převodníky USB → RS-485. Každý sériový port odpovídá jedné lince sběrnice.

Typické názvy portů:

| Systém | Příklad |
|---|---|
| Linux | `/dev/ttyUSB0`, `/dev/ttyUSB1`, `/dev/ttyUSB2` |
| Windows | `COM3`, `COM4`, `COM5` |

!!! note "Více linek"
    Pokud máte v domě více linek (např. jednu na patro), každá linka má svůj převodník a tedy svůj sériový port. Všechny porty nastavíte zde.

---

## Devices

Seznam všech HW jednotek v systému a jejich přiřazení k jednotlivým sériovým portům (linkám). Podle tohoto seznamu Majordomus Control ví, s jakými zařízeními má komunikovat a na které lince je hledat.

Pro každé zařízení nastavíte:

- **Typ** — RoomSensor, RoomIO, BoxIO
- **Adresa** — unikátní adresa zařízení na sběrnici
- **Sériový port** — na které lince je zařízení připojeno
- **Název** — volitelný popisek pro snadnou orientaci (např. „Obývák", „Koupelna 2.NP")

---

## Konfigurační soubor

Konfigurace se automaticky ukládá do souboru `config.xml` v pracovním adresáři aplikace Majordomus Control (typicky `~/majordomus/config.xml`). Soubor se generuje automaticky přes webové rozhraní — ruční editace není nutná, ale je možná.

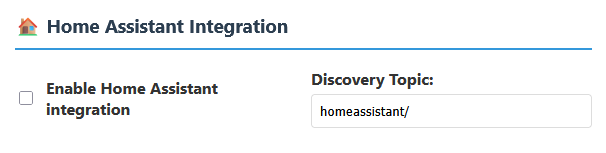
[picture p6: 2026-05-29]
docs/assets/mc_ha.png

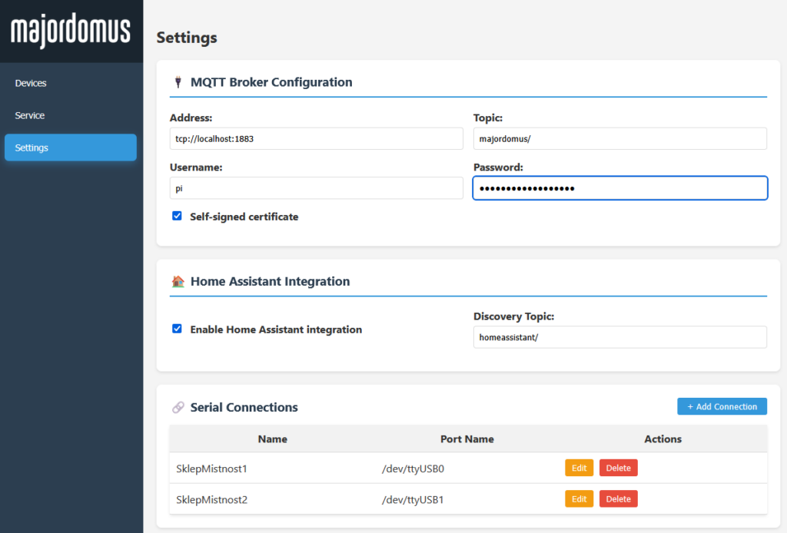
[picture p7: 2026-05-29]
docs/assets/mc_settings.png

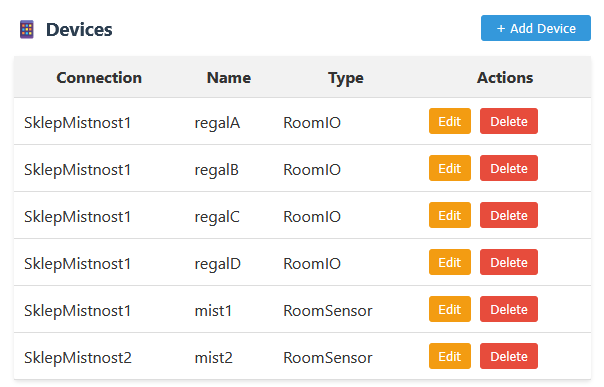
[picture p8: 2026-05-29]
docs/assets/mc_devices.png

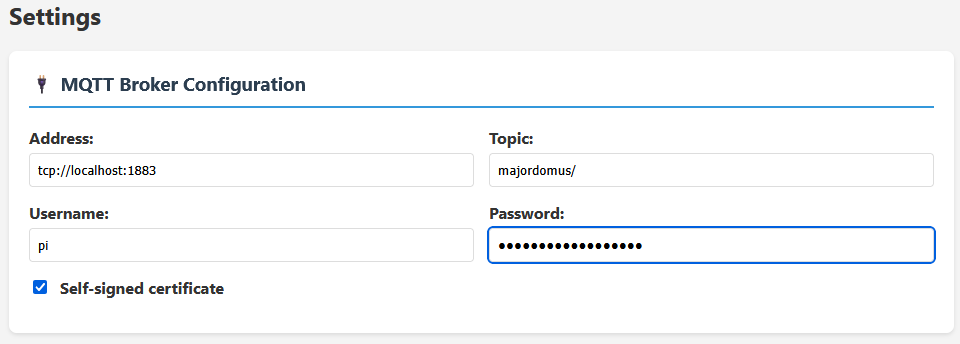
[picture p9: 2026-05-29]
docs/assets/mc_mqtt_broker.png

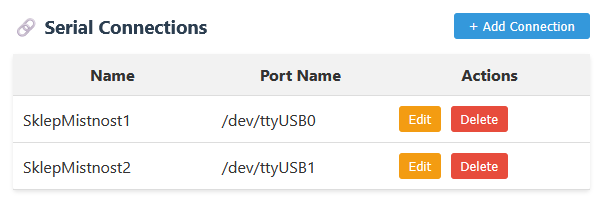
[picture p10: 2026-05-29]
docs/assets/mc_serial.png

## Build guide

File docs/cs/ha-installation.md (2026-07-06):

# Instalace Home Assistant

Home Assistant lze provozovat dvěma základními způsoby a pro oba existuje připravená instalace Majordomus Control:

| Varianta | Pro koho | Majordomus Control |
|---|---|---|
| **Home Assistant OS (HAOS)** | Doporučeno pro většinu uživatelů | Doplněk (add-on) přímo v Home Assistantu |
| **Docker** | Pro pokročilé, kteří už Docker používají | Samostatný kontejner přes Docker Compose |

---

## Varianta A: Home Assistant OS + doplněk Majordomus

Home Assistant OS je kompletní operační systém — nainstalujete ho na Raspberry Pi (nebo jiný mini PC) a o nic dalšího se nestaráte. Aktualizace, zálohy i instalace doplňků probíhají přímo z webového rozhraní.

### 1. Instalace Home Assistant OS

1. Stáhněte si [Raspberry Pi Imager](https://www.raspberrypi.com/software/).
2. Zvolte **Choose OS → Other specific-purpose OS → Home assistants and home automation → Home Assistant**.
3. Zapište systém na SD kartu (doporučujeme min. 32 GB) a vložte ji do Raspberry Pi.
4. Po několika minutách bude Home Assistant dostupný na adrese `http://homeassistant.local:8123`.

Podrobný oficiální návod: [home-assistant.io/installation](https://www.home-assistant.io/installation/)

### 2. Instalace MQTT brokeru (Mosquitto)

Majordomus komunikuje s Home Assistantem přes MQTT. V HAOS nainstalujete broker jedním kliknutím:

1. Přejděte do **Nastavení → Aplikace → Obchod s doplňky**.
2. Vyhledejte **Mosquitto broker** a klikněte na **Nainstalovat**.
3. Po instalaci doplněk **Spusťte** a zapněte **Spustit při startu**.
4. V **Nastavení → Lidé → Uživatelé** vytvořte nového uživatele (např. `mqtt`) — jeho jméno a heslo použijete pro připojení Majordomu k brokeru.

### 3. Přidání repozitáře Majordomus

1. Přejděte do **Nastavení → Aplikace → Obchod s doplňky**.
2. Klikněte na menu **⋮** (vpravo nahoře) → **Repozitáře**.
3. Vložte adresu repozitáře a potvrďte:

```
https://github.com/jirihusak/majordomus-ha-addon
```

### 4. Instalace doplňku Majordomus

1. V obchodě s doplňky se nyní objeví sekce **Majordomus** — klikněte na doplněk **Majordomus**.
2. Klikněte na **Nainstalovat**.
3. Na záložce **Konfigurace** vyplňte přihlašovací údaje k MQTT (uživatel vytvořený v kroku 2). Výchozí `mqtt_host: core-mosquitto` ukazuje na doplněk Mosquitto — ten neměňte.
4. Doplněk **Spusťte** a zapněte **Spustit při startu** a **Zobrazit v bočním panelu**.

V bočním panelu Home Assistantu se objeví položka **Majordomus** — webové rozhraní Majordomus Control, kde nastavíte sériové porty a HW jednotky (viz [Konfigurace SW](sw-configuration.md)).

!!! note "Převodník USB → RS-485"
    Doplněk má povolený přístup k sériovým portům (UART). Převodník stačí připojit do USB — v rozhraní Majordomus Control ho pak najdete typicky jako `/dev/ttyUSB0`.

---

## Varianta B: Docker

Pokud provozujete Home Assistant v Dockeru (Home Assistant Container), doplňky nejsou k dispozici — Majordomus Control spustíte jako samostatný kontejner. Následující `docker-compose.yml` obsahuje kompletní sestavu: MQTT broker, Home Assistant i Majordomus Control.

```yaml
services:

  mosquitto:
    image: eclipse-mosquitto:2
    container_name: mosquitto
    restart: unless-stopped
    ports:
      - "1883:1883"
    volumes:
      - ./mosquitto/config:/mosquitto/config
      - ./mosquitto/data:/mosquitto/data

  homeassistant:
    image: ghcr.io/home-assistant/home-assistant:stable
    container_name: homeassistant
    restart: unless-stopped
    network_mode: host
    environment:
      - TZ=Europe/Prague
    volumes:
      - ./homeassistant:/config

  majordomus:
    image: ghcr.io/jirihusak/majordomus-control-amd64:latest
    container_name: majordomus
    restart: unless-stopped
    ports:
      - "8899:8899"
    devices:
      - /dev/ttyUSB0:/dev/ttyUSB0
    volumes:
      - ./majordomus:/config
    environment:
      MQTT_BROKER: "tcp://mosquitto:1883"
      MQTT_USERNAME: ""
      MQTT_PASSWORD: ""
      MQTT_TOPIC: "majordomus/"
      HA_DISCOVERY: "true"
      HA_TOPIC: "homeassistant/"
```

!!! warning "Zvolte správnou architekturu"
    Image existuje ve dvou variantách — použijte tu, která odpovídá vašemu zařízení:

    - `ghcr.io/jirihusak/majordomus-control-amd64` — běžné PC, NUC, x86 servery
    - `ghcr.io/jirihusak/majordomus-control-aarch64` — Raspberry Pi 4/5 a další ARM 64bit zařízení

Spuštění celé sestavy:

```bash
docker compose up -d
```

Po spuštění bude dostupné:

- **Home Assistant** — `http://<IP_ADRESA>:8123`
- **Majordomus Control** — `http://<IP_ADRESA>:8899`

!!! note "Mosquitto v Dockeru vyžaduje konfiguraci"
    Vytvořte soubor `mosquitto/config/mosquitto.conf` s tímto obsahem (pro první vyzkoušení bez hesla):

    ```
    persistence false
    allow_anonymous true
    listener 1883
    ```

---

## Jak pokračovat

1. V rozhraní Majordomus Control (`:8899` nebo panel v HA) nastavte sériové porty a HW jednotky → [Konfigurace SW](sw-configuration.md)
2. Propojte Home Assistant s MQTT brokerem → [Konfigurace Home Assistant](ha-configuration.md)

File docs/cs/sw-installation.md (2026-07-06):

# Instalace software

Instalace je napsána pro mini PC Raspberry Pi s výchozím operačním systémem Raspberry Pi OS. Postup je ale stejný pro jakoukoliv distribuci založenou na Debianu (Ubuntu, Mint...).

Majordomus Control Web interface

---

## 1. Instalace MQTT brokeru (Mosquitto)

### Update systému

```bash
sudo apt update
sudo apt upgrade -y
```

### Instalace Mosquitto

```bash
sudo apt install -y mosquitto mosquitto-clients
```

### Povolení automatického spouštění

```bash
sudo systemctl enable mosquitto
sudo systemctl start mosquitto
```

### Konfigurace pro testování

Pro rychlé vyzkoušení stačí povolit anonymní přístup bez hesla. Otevřete konfigurační soubor:

```bash
sudo nano /etc/mosquitto/mosquitto.conf
```

Smažte obsah a nahraďte ho tímto:

```
persistence false
allow_anonymous true
listener 1883
```

Uložte (`Ctrl+O`, `Enter`, `Ctrl+X`) a restartujte službu:

```bash
sudo systemctl restart mosquitto.service
```

!!! warning "Pouze pro testování"
    Anonymní přístup bez hesla je vhodný jen pro první vyzkoušení na lokální síti. Pro reálné nasazení je nutné nastavit přihlašování jménem a heslem, případně šifrování komunikace pomocí TLS.

---

## 2. Instalace Majordomus Control

### Instalace Javy

Majordomus Control je napsaný v Javě. Nainstalujte JDK:

```bash
sudo apt install -y openjdk-25-jdk
```

### Stažení a rozbalení

```bash
mkdir -p ~/majordomus
cd ~/majordomus
wget https://github.com/jirihusak/majordomus/releases/latest/download/MajordomusControl.zip
sudo apt install -y unzip
unzip MajordomusControl.zip -d .
```

### Spuštění

```bash
chmod +x run.sh
./run.sh
```

Po spuštění by mělo být webové rozhraní dostupné na adrese `http://<IP_ADRESA>:8899`.

!!! tip "Jak zjistit IP adresu Raspberry Pi?"
    Zadejte v terminálu `hostname -I` — zobrazí se IP adresa vašeho zařízení v lokální síti.

---

## 3. Automatické spouštění po startu

Aby se Majordomus Control spustil automaticky po každém zapnutí nebo restartu Raspberry Pi, vytvořte systemd službu.

### Vytvoření souboru služby

```bash
sudo nano /etc/systemd/system/majordomus.service
```

### Obsah souboru

```ini
[Unit]
Description=Majordomus Control
After=network.target

[Service]
Type=simple
ExecStart=/home/pi/majordomus/run.sh
WorkingDirectory=/home/pi/majordomus
User=pi
Group=pi
Restart=on-failure

[Install]
WantedBy=multi-user.target
```

Uložte: `Ctrl+O`, `Enter`, `Ctrl+X`.

### Aktivace služby

```bash
sudo systemctl daemon-reload
sudo systemctl enable majordomus
sudo systemctl start majordomus
```

### Ověření

Otevřete v prohlížeči `http://<IP_ADRESA>:8899` — mělo by se zobrazit webové rozhraní Majordomus Control.

```bash
# Kontrola stavu služby
sudo systemctl status majordomus
```

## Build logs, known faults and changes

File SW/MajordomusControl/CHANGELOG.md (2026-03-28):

# Changelog

## \[0.5] - 2026-03-28
* HomeAssistant new MQTT protocol

## \[0.4] - 2025-12-06

### Added

* WEB GUI on port 8899
* FW Updates included in SW
* HomeAssistant initial integration

## \[0.3.1] - 2024-11-24

### Added

* Support for SSL in MQTT communication.
* GUI add Reset button and change device ID 50:50 (for fixing duplicate id on bus)
* Split "do" topic to "do0", "do1", ...

## \[0.3.0] - YYYY-MM-DD

### Added

* Initial release of MajordomusControl.
* Basic MQTT communication support.
* Integration with JavaFX for UI.
* Dependency management using Maven.

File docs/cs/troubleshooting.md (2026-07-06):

# Řešení problémů

Když něco nefunguje, postupujte **po vrstvách odspodu nahoru** — od napájení přes sběrnici a sériový port až po aplikace. Každá kapitola končí stavem, který musí platit, než má smysl pokračovat na další vrstvu.

```mermaid
graph LR
    A[1. Napájení] --> B[2. Sběrnice RS-485]
    B --> C[3. Linux — sériový port]
    C --> D[4. Majordomus Control]
    D --> E[5. MQTT]
    E --> F[6. Home Assistant]
```

---

## 1. Napájení

**Co zkontrolovat:**

- Svítí/žije jednotka? RoomSensor po připojení napájení rozsvítí displej. BoxIO má LED indikaci.
- Změřte multimetrem napětí **přímo na svorkách jednotky** (ne u zdroje) — na dlouhém UTP kabelu vzniká úbytek. Napětí musí být v pracovním rozsahu jednotky (RoomSensor 7–27 V, RoomIO 6–30 V, BoxIO 10–30 V).
- Zkontrolujte polaritu — vodiče 12V a GND.
- Pokud je napětí u zdroje v pořádku, ale na jednotce ne: zkrat na lince, nebo příliš tenký/dlouhý kabel. Převodník RS485 2 USB má **vratnou pojistku** — při zkratu odpojí napájení linky a po odstranění zkratu se sama obnoví.

✅ *Dál pokračujte, až má každá jednotka na svorkách napětí v pracovním rozsahu.*

---

## 2. Sběrnice RS-485 a převodník

Převodník RS485 2 USB má **indikační LED pro TX a RX** — to je nejrychlejší diagnostika sběrnice:

| TX | RX | Význam |
|---|---|---|
| bliká | bliká | Vše v pořádku — master se ptá, jednotky odpovídají |
| bliká | nesvítí | Dotazy odchází, ale nikdo neodpovídá → problém na lince nebo v jednotkách |
| nesvítí | nesvítí | Majordomus Control nekomunikuje → pokračujte kapitolou 3 a 4 |

**Když TX bliká a RX ne:**

- **Prohozené vodiče A a B** — nejčastější chyba. Zkuste je na převodníku prohodit.
- Zkontrolujte průchodnost vodičů A a B po celé délce linky (jednotky jsou zapojené průběžně — přerušení uprostřed odpojí všechny další).
- Zkontrolujte **zakončovací odpor** — na převodníku se aktivuje jumperem.
- Zkuste jednotku připojit **napřímo krátkým kabelem** na stole — oddělíte tak problém kabeláže od problému jednotky.
- Neodpovídá jen jedna jednotka? Může mít špatné/duplicitní `id` — viz Autodetect v kapitole 4.

✅ *Dál pokračujte, až blikají obě LED.*

---

## 3. Linux — sériový port

**Vidí systém převodník?**

```bash
ls /dev/ttyUSB*
```

Měl by se zobrazit `/dev/ttyUSB0` (případně další). Pokud ne:

```bash
# je převodník vidět na USB? (čip FTDI FT230X)
lsusb | grep -i ftdi

# co se stalo po připojení kabelu?
sudo dmesg | tail -20
```

- **`lsusb` převodník nevidí** → problém s USB kabelem (zkuste jiný — některé USB-C kabely jsou jen napájecí), portem nebo převodníkem.
- **`lsusb` ho vidí, ale `/dev/ttyUSB0` neexistuje** → na desktopových distribucích port často zabírá služba `brltty` (podpora braillských řádků). Odinstalujte ji: `sudo apt remove brltty` a převodník znovu připojte.

**Máte práva k portu?** Uživatel musí být ve skupině `dialout`:

```bash
groups                # je tam "dialout"?
sudo usermod -a -G dialout $USER   # přidání; poté se odhlaste a přihlaste
```

**Nesahá na port něco jiného?** Port může držet jen jedna aplikace současně:

```bash
sudo fuser -v /dev/ttyUSB0
```

!!! note "Více převodníků"
    Čísla `ttyUSB0`, `ttyUSB1`... se přidělují podle pořadí připojení a po restartu se mohou prohodit. Pokud máte více linek, ověřte, který port patří které lince (odpojte/připojte převodník a sledujte `dmesg`).

✅ *Dál pokračujte, až existuje `/dev/ttyUSB0` a jste ve skupině `dialout`.*

---

## 4. Majordomus Control (port 8899)

Otevřete webové rozhraní `http://<IP_ADRESA>:8899`.

**Stránka se nenačte?**

```bash
# běží služba?
sudo systemctl status majordomus

# poslouchá na portu?
ss -tlnp | grep 8899
```

Projděte log služby: `journalctl -u majordomus -e`. Typická chyba je špatný název sériového portu v konfiguraci nebo port obsazený jinou aplikací.

**Stránka běží — zkontrolujte zařízení:**

- V sekci **Devices** je u každého zařízení stav **online / offline**.
- Zařízení offline? Zkontrolujte, že souhlasí **id zařízení** (rozlišuje velikost písmen), **typ** a **sériový port** (linka), na kterém je připojené.

!!! tip "Autodetect — nechte zařízení najít automaticky"
    V sekci konfigurace klikněte na **🔍 Autodetect**. Majordomus Control projde všechny sériové porty, osloví zařízení na sběrnici a nabídne nalezenou konfiguraci (porty, id a typy zařízení) k uložení. Je to nejrychlejší způsob, jak zjistit, „co na lince opravdu je".

- Zařízení se objevuje a mizí (střídá online/offline)? Podezření na **duplicitní id** dvou jednotek nebo rušení na dlouhé lince (zkontrolujte zakončovací odpor a kvalitu kabelu).

✅ *Dál pokračujte, až jsou všechna zařízení online.*

---

## 5. MQTT

**Běží broker a chodí do něj data?**

```bash
sudo systemctl status mosquitto

# sledování všech témat Majordomu
mosquitto_sub -h localhost -t "majordomus/#" -v
```

- **Zprávy chodí** → MQTT vrstva je v pořádku, pokračujte kapitolou 6.
- **Nic nechodí** → zkontrolujte v Majordomus Control sekci **MQTT Broker**: adresu (`tcp://localhost:1883`), uživatelské jméno a heslo. Chybu připojení uvidíte v logu (`journalctl -u majordomus -e`).
- **Connection refused** → broker neběží, poslouchá jen na jiné adrese, nebo blokuje anonymní přístup (viz `/etc/mosquitto/mosquitto.conf`).

**Test ovládání** — zapněte výstup ručně:

```bash
mosquitto_pub -h localhost -t "majordomus/<zařízení>/cmd/do0" -m "1"
```

✅ *Dál pokračujte, až v `mosquitto_sub` vidíte proud zpráv.*

---

## 6. Home Assistant

**Zařízení se v HA neobjevují?**

- V Majordomus Control musí být povolená **Home Assistant Integration** (u doplňku volba `ha_discovery: true`).
- Home Assistant musí být připojený ke **stejnému brokeru** — Nastavení → Zařízení a služby → MQTT.
- Discovery prefix musí souhlasit (`homeassistant/` na obou stranách).
- Ověřte, že discovery zprávy odchází: `mosquitto_sub -h localhost -t "homeassistant/#" -v` — po restartu Majordomus Control se musí zobrazit `config` zprávy.

**Entity existují, ale jsou „nedostupné" (unavailable)?**

- Zařízení je offline na RS-485 (téma `state/online` = `offline`) → vraťte se ke kapitole 4.
- Hodnota `NaN` u konkrétního senzoru = senzor není osazen/připojen — to je v pořádku.

---

## Rychlá tabulka nejčastějších problémů

| Příznak | Nejčastější příčina | Řešení |
|---|---|---|
| Jednotka nejeví známky života | Úbytek napětí na kabelu, přehozená polarita | Změřit napětí na svorkách jednotky |
| TX bliká, RX ne | Prohozené vodiče A/B | Prohodit A a B |
| Chybí `/dev/ttyUSB0` | Nabíjecí USB kabel, `brltty` | Vyměnit kabel, `sudo apt remove brltty` |
| „Permission denied" na portu | Uživatel není v `dialout` | `sudo usermod -a -G dialout $USER` + přihlásit znovu |
| Zařízení offline v aplikaci | Špatné id / typ / port v konfiguraci | Spustit **Autodetect** |
| Zařízení střídá online/offline | Duplicitní id, rušení na lince | `newId5050`, zakončovací odpor, kabeláž |
| Žádná data v MQTT | Špatná adresa/přihlášení k brokeru | Zkontrolovat sekci MQTT Broker + log |
| Zařízení nejsou v HA | Vypnuté discovery, jiný broker | Zapnout HA integraci, ověřit MQTT integraci v HA |

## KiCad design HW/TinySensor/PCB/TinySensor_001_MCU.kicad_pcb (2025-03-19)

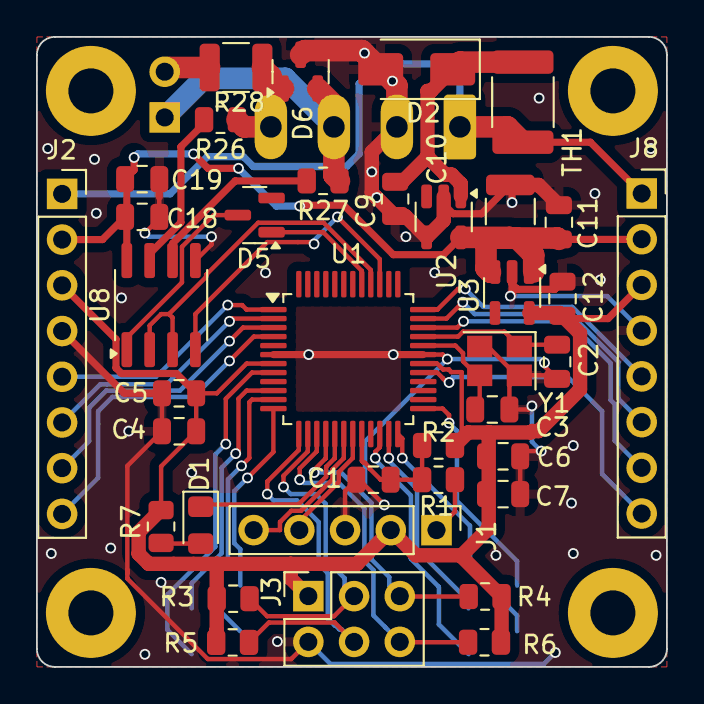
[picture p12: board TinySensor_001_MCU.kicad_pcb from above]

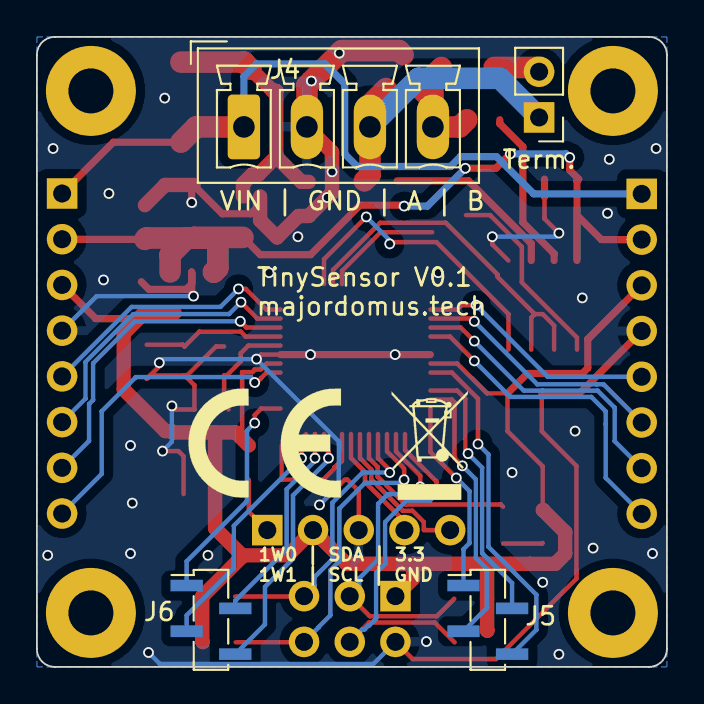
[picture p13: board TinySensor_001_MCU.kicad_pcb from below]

Board: 2 copper layers, 35.0 x 35.0 mm, 45 parts (4 on the bottom side), 42 nets.

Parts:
 : MountingHole_2.5mm_Pad
 #2,  #3,  #4: MountingHole_2.5mm_Pad
C1, C5, C6, C11, C18: 100nF; C_0805_2012Metric
C2, C3: 18pF; C_0805_2012Metric
C4, C7, C9, C12, C19: 1uF; C_0805_2012Metric
C10: 2.2uF; C_1210_3225Metric
D1: LED; LED_0805_2012Metric_Pad1.15x1.40mm_HandSolder
D2: SMAJ28; D_SMA
D5: BAS70LT1G; SOT-23
D6: D_TVS_x2_AAC; SOT-23
J1: CONN_DEBUG; PinHeader_1x05_P2.54mm_Vertical
J2, J8: Conn_01x08; PinSocket_1x08_P2.54mm_Vertical
J3: Conn_02x03_Odd_Even; PinSocket_2x03_P2.54mm_Vertical
J4: Conn_01x04; PhoenixContact_MCV_1,5_4-G-3.5_1x04_P3.50mm_Vertical
J5, J6: Conn_01x04; PinSocket_1x04_P1.27mm_Vertical_SMD_Pin1Left
R1: 10k; R_0805_2012Metric
R2: 100R; R_0805_2012Metric
R3, R4, R5, R6: 4k7; R_0805_2012Metric
R7: 1k; R_0805_2012Metric
R26, R27: 10R; R_0805_2012Metric
R28: 120R; R_1210_3225Metric
TH1: MF-MSMF050-2; Fuse_1812_4532Metric_Pad1.30x3.40mm_HandSolder
Term.: Jumper; PinHeader_1x02_P2.54mm_Vertical
U1: PIC18F57K42; TQFP-48_7x7mm_P0.5mm
U2: TPS709; SOT-23-5
U3: TLV70233DBVR; SOT-23-5
U8: SN65HVD3082EDR; SOIC-8_3.9x4.9mm_P1.27mm
Y1: Crystal_GND24; Crystal_SMD_SeikoEpson_FA238-4Pin_3.2x2.5mm

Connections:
+3.3V: C4.1, C5.1, C6.1, C7.1, C12.1, J1.2, J2.3, J3.1, J8.3, R1.1, R3.1, R4.1, R5.2, R6.2, R7.1, U1.7 (VDD), U1.30 (VDD), U3.5 (OUT)
+5V: C10.1, C11.1, C18.1, C19.1, J2.2, J8.2, U2.5 (OUT), U3.1 (IN), U3.3 (EN), U8.8 (VCC)
+12V: J2.1, J4.1, J8.1, TH1.2
/Connectors/RS485-A: D6.2 (A2), J4.3, R27.1, Term..1
/Connectors/RS485-B: D6.1 (A1), J4.4, R26.1, R28.2
/MCU_PIC18/A1: J6.4, U1.22 (RA1)
/MCU_PIC18/A2: J6.2, U1.23 (RA2)
/MCU_PIC18/A3: J6.3, U1.24 (RA3)
/MCU_PIC18/A4: J6.1, U1.25 (RA4)
/MCU_PIC18/B0: J5.4, U1.8 (RB0)
/MCU_PIC18/B2: J5.2, U1.10 (RB2)
/MCU_PIC18/B3: J5.3, U1.11 (RB3)
/MCU_PIC18/B4: J3.5, R4.2, U1.16 (RB4)
/MCU_PIC18/C0: J8.7, U1.34 (RC0)
/MCU_PIC18/C1: J8.6, U1.35 (RC1)
/MCU_PIC18/C7: J2.5, U1.1 (RC7)
/MCU_PIC18/D4: J2.6, U1.2 (RD4)
/MCU_PIC18/D5: J2.7, U1.3 (RD5)
/MCU_PIC18/D6: J2.8, U1.4 (RD6)
/MCU_PIC18/E2: J8.8, U1.29 (RE2)
/MCU_PIC18/F0: J8.5, U1.36 (RF0)
/MCU_PIC18/F4: J5.1, U1.12 (RF4)
/MCU_PIC18/F5: J3.4, R5.1, U1.13 (RF5)
/MCU_PIC18/F6: J3.3, R3.2, U1.14 (RF6)
/MCU_PIC18/F7: J3.6, R6.1, U1.15 (RF7)
/MCU_PIC18/RS485_RX: U1.39 (RF3), U8.4 (D)
/MCU_PIC18/RS485_TX: D5.2 (A), U1.41 (RC3)
/MCU_PIC18/RS485_TX_ENABLE: U1.40 (RC2), U8.2 (#RE), U8.3 (DE)
GND: C1.2, C2.2, C3.2, C4.2, C5.2, C6.2, C7.2, C9.2, C10.2, C11.2, C12.2, C18.2, C19.2, D2.2 (A), D6.3 (common), J1.3, J2.4, J3.2, J4.2, J8.4, U1.6 (VSS), U1.31 (VSS), U2.2 (GND), U2.4 (GND), U3.2 (GND), U8.5 (GND), Y1.2, Y1.4
ICSPCLK: J1.5, U1.18 (RB6)
ICSPDAT: J1.4, U1.19 (RB7)
LED_WORK: D1.1 (K), U1.17 (RB5)
MCLR: C1.1, R1.2, R2.1, U1.20 (MCLR/RE3)
unnamed: D1.2 (A), R7.2
unnamed: C9.1, D2.1 (K), TH1.1, U2.1 (IN)
unnamed: D5.1 (K), U8.1 (R)
unnamed: J1.1, R2.2
unnamed: R28.1, Term..2
unnamed: C2.1, U1.33 (RA6), Y1.1
unnamed: C3.1, U1.32 (RA7), Y1.3
unnamed: R27.2, U8.6 (A)
unnamed: R26.2, U8.7 (B)

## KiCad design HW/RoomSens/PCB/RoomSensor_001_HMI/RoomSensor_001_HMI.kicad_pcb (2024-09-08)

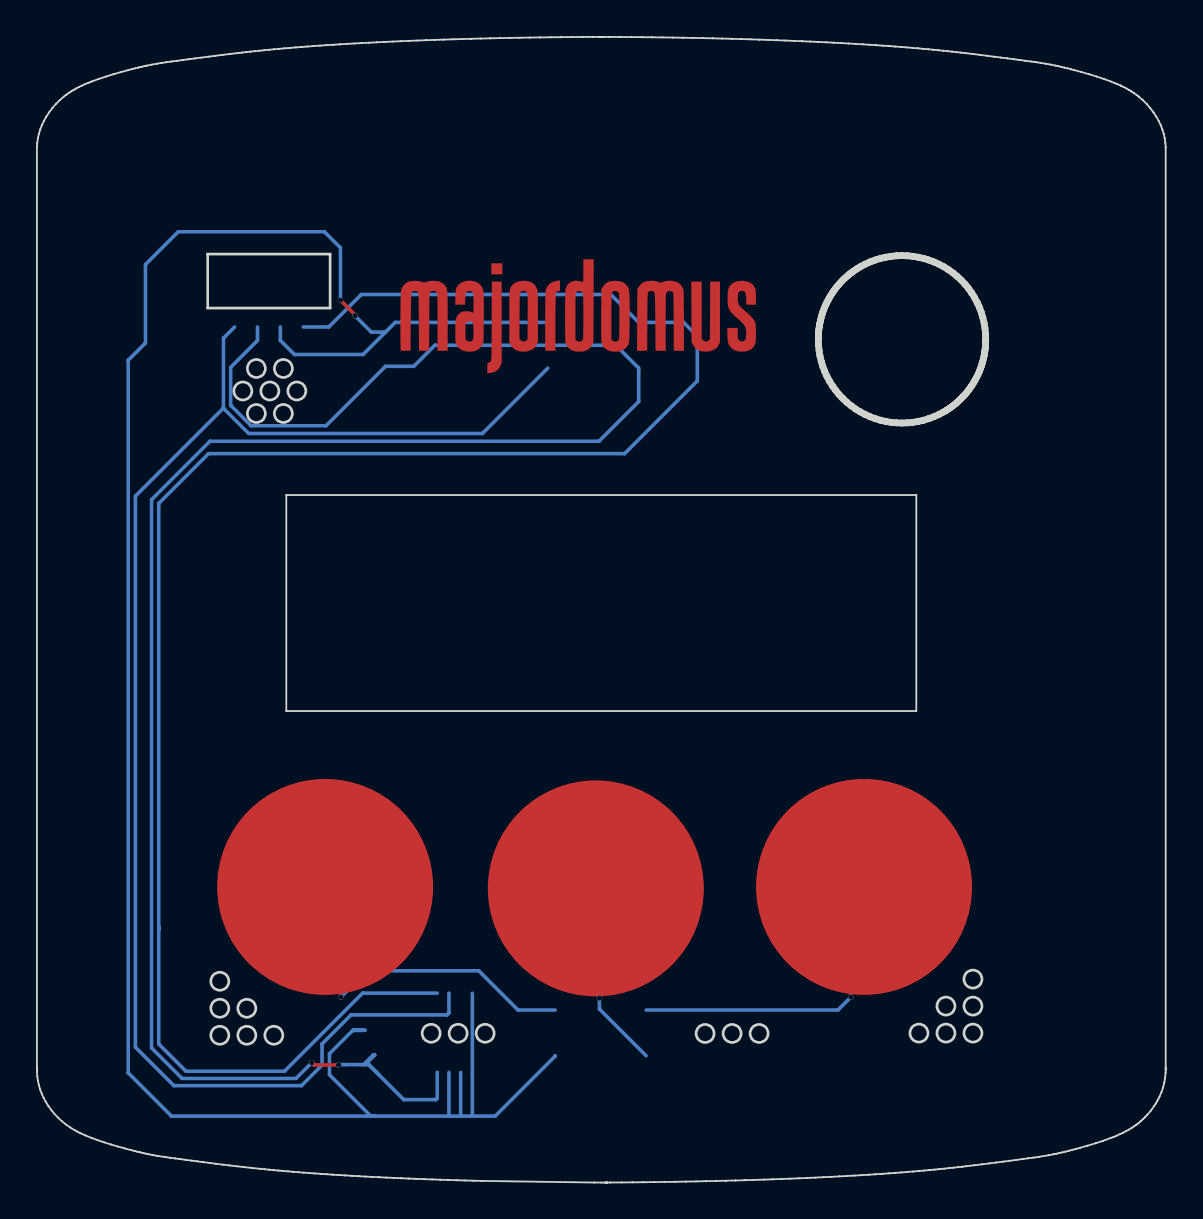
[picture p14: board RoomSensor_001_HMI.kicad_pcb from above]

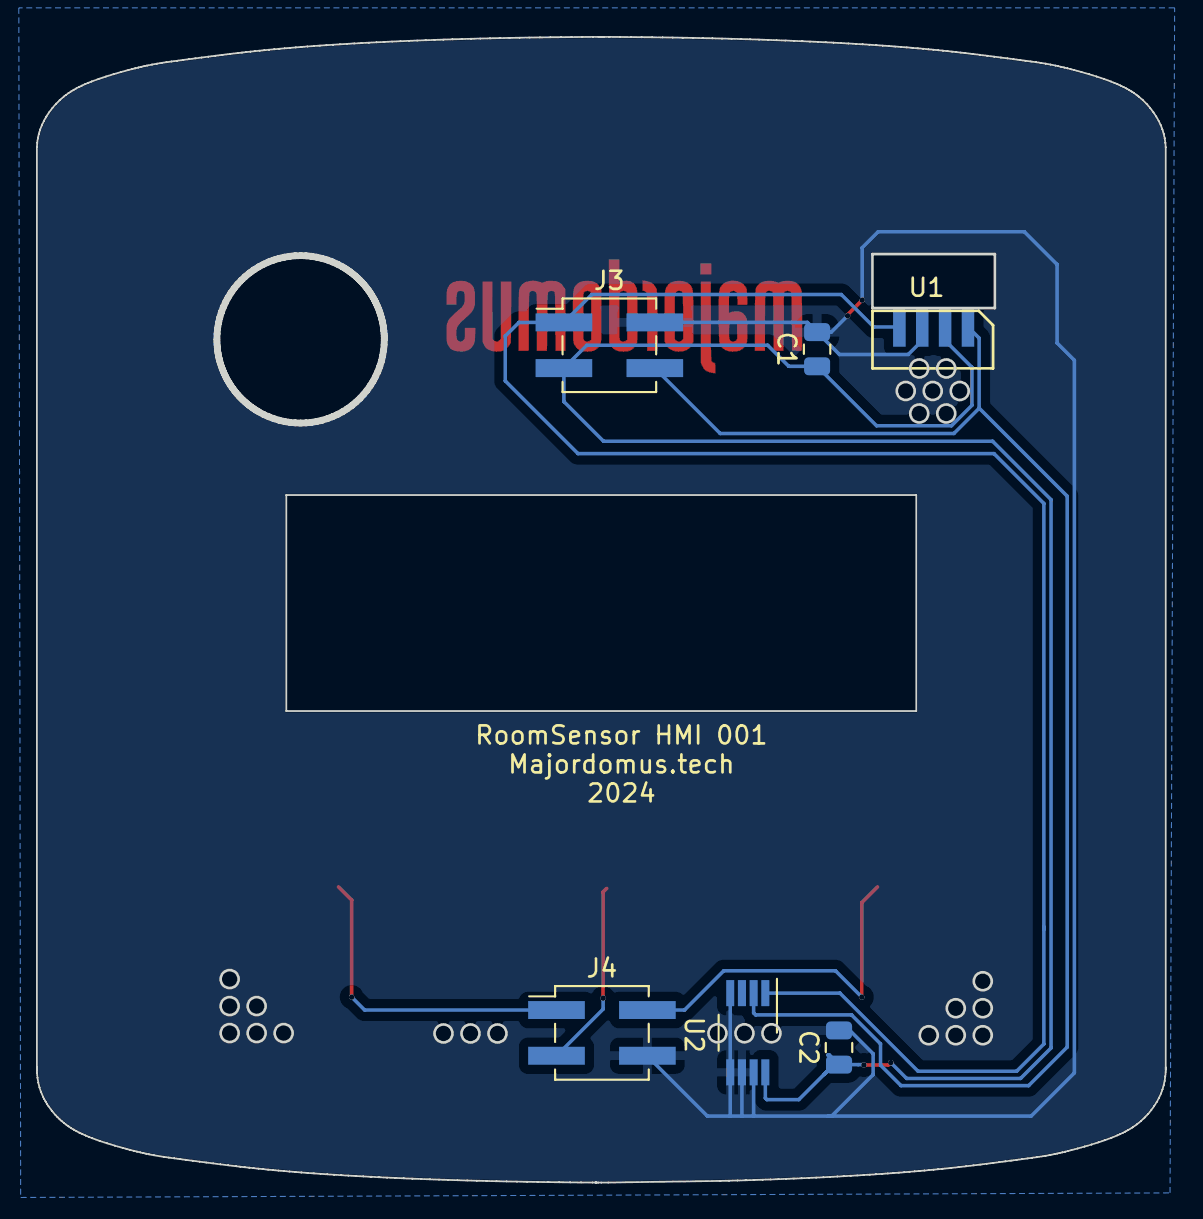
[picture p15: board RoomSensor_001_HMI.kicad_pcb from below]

Board: 2 copper layers, 62.7 x 63.6 mm, 9 parts (6 on the bottom side), 7 nets.

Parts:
 : Antenna; CapButtonMinus
 #2: Antenna; CapButtonEnter
 #3: Antenna; CapButtonPlus
C1, C2: C; C_0805_2012Metric
J3, J4: Conn_02x02_Odd_Even; PinHeader_2x02_P2.54mm_Vertical_SMD
U1: VEML7700-TT; VEML7700
U2: TMP1075DGK; VSSOP-8_3.0x3.0mm_P0.65mm

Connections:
+3.3V: C1.1, C2.1, J3.3, U1.2 (VDD), U2.8 (V+)
GND: C1.2, C2.2, J3.2, J4.4, U1.3 (GND), U2.4 (GND), U2.5 (A2), U2.6 (A1), U2.7 (A0)
I2C_SCL: J3.4, U1.1 (SCL), U2.2 (SCL)
I2C_SDA: J3.1, U1.4 (SDA), U2.1 (SDA)
unnamed: #3.1 (A), J4.1
unnamed: #2.1 (A), J4.3
unnamed: .1 (A), J4.2

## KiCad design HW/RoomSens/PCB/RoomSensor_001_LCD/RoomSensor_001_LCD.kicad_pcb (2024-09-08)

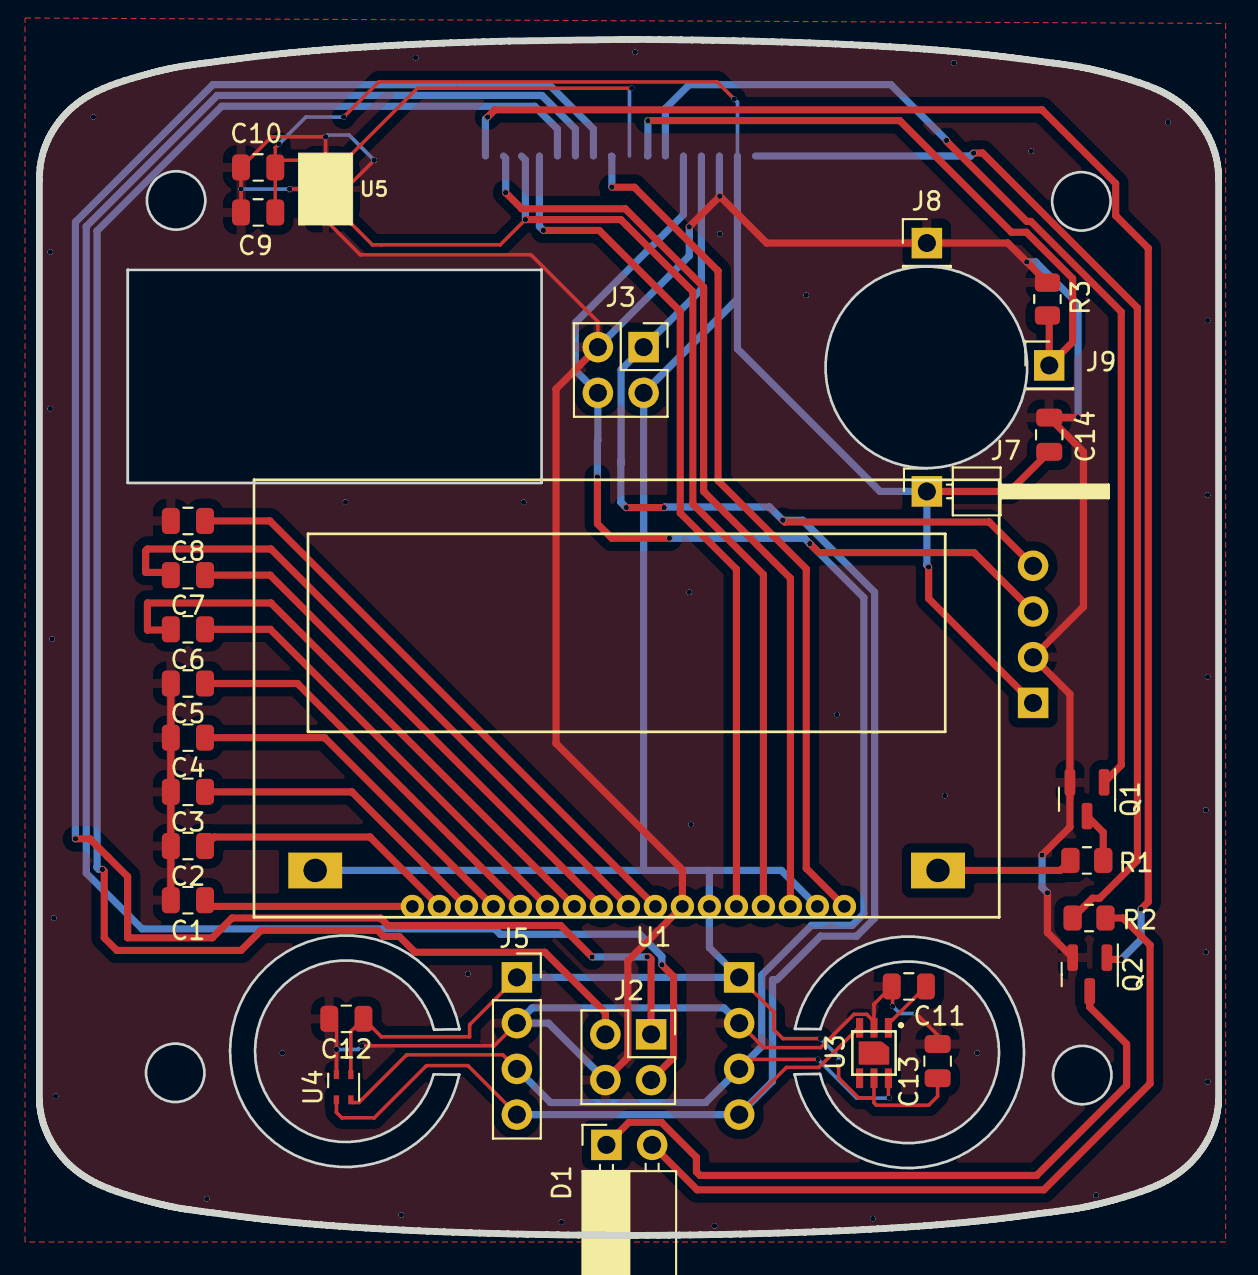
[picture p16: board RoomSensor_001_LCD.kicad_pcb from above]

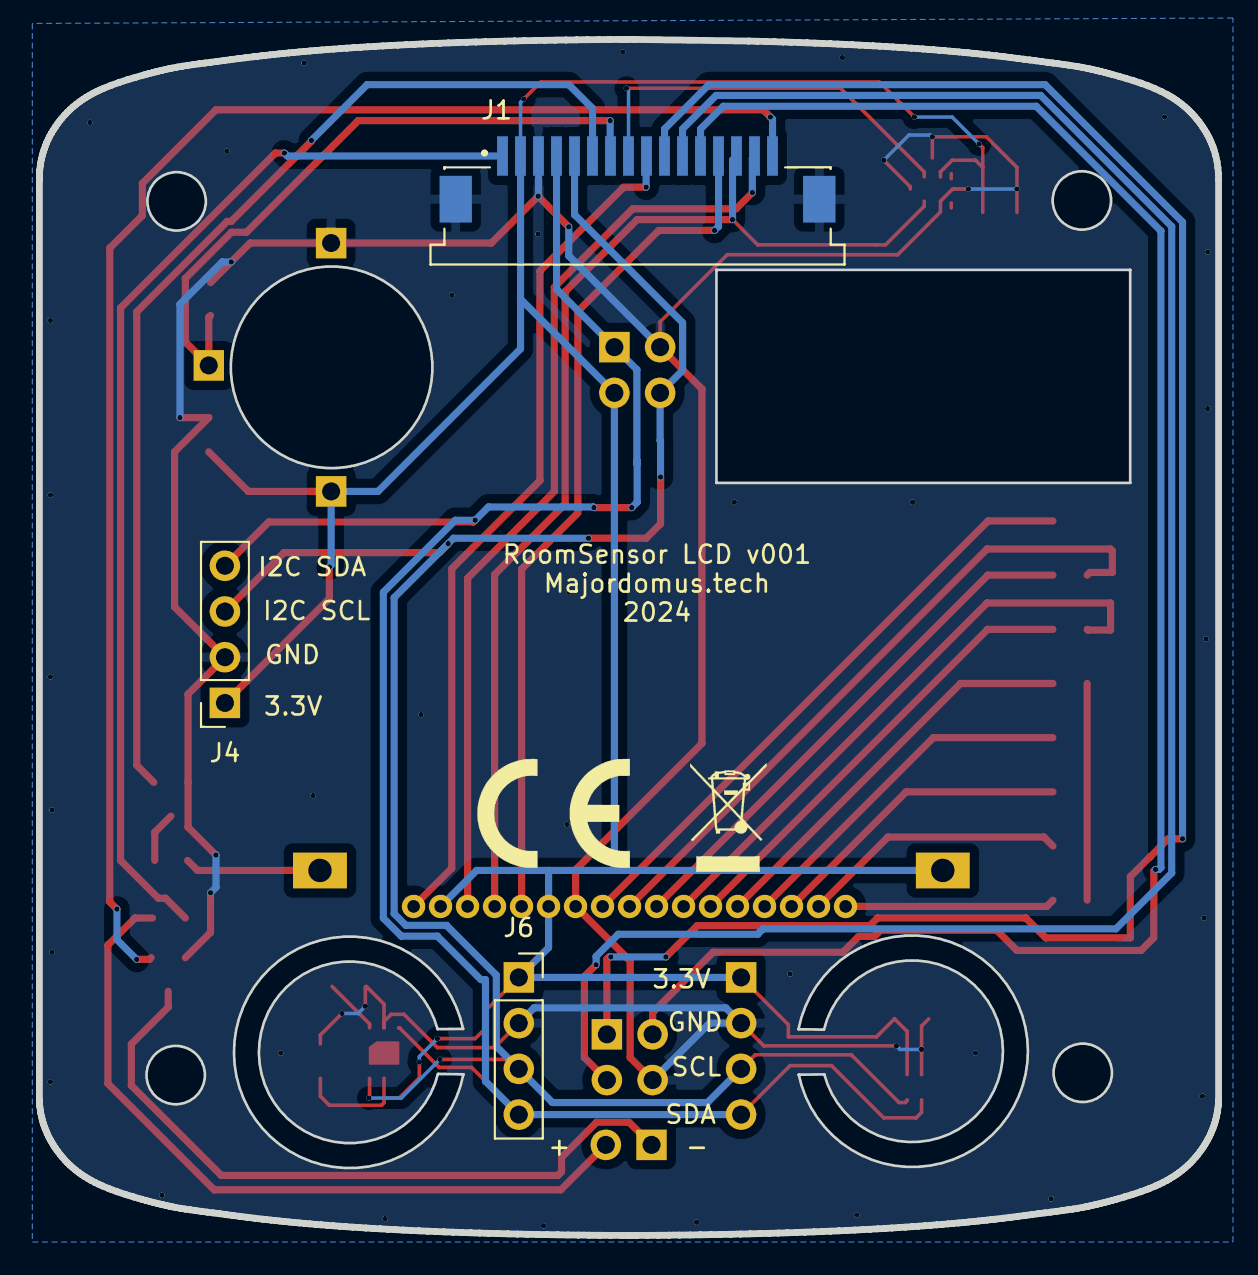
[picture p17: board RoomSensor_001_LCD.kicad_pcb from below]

Board: 2 copper layers, 65.5 x 66.4 mm, 33 parts (3 on the bottom side), 31 nets.

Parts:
C1, C2, C3, C4, C5: 100nF; C_0805_2012Metric
C6, C7, C8, C9, C10, C11, C12, C13, C14: 1uF; C_0805_2012Metric
D1: LED LL-234WC2Q-W5-3P; PinSocket_1x02_P2.54mm_Horizontal
J1: 68611614422; WURTH_68611614422
J2, J3: Conn_02x02_Odd_Even; PinSocket_2x02_P2.54mm_Vertical
J4, J5, J6: Conn_01x04; PinSocket_1x04_P2.54mm_Vertical
J7: Conn_01x01; PinHeader_1x01_P2.54mm_Horizontal
J8, J9: Conn_01x01; PinHeader_1x01_P2.54mm_Vertical
Q1, Q2: MMBF170; SOT-23
R1: 1k5; R_0805_2012Metric
R2: R; R_0805_2012Metric
R3: 100k; R_0805_2012Metric
U1: NHD-C12832A1Z-NSW-BBW-3V3; NHD-C12832A1Z
U3: SGP40
U4: SHT41-AD1F-R2; Sensirion_DFN-4_1.5x1.5mm_P0.8mm_SHT4x_NoCentralPad
U5: MP34DT05-A; MIC-PACK

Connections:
+3.3V: C9.1, C10.1, C12.1, C13.1, C14.1, J1.2, J3.3, J4.1, J5.1, J6.1, J7.1, U1.12 (VDD), U1.16 (/RES), U1.18 (LED_Anode_+), U3.5 (VDD), U4.3 (VDD), U5.VDD
+5V: J1.1, R2.2
/LCD_A0: J1.15, U1.15 (A0)
/LCD_BACKLIGHT: J1.6, Q1.1 (G)
/LCD_CS: J1.9, U1.17 (CS1B)
/LED_AMBIENT: J1.16, Q2.1 (G)
/PIR: J1.7, J9.1, R3.1
/SPI_MISO: J1.8, U5.DOUT
/SPI_MOSI: J1.13, U1.13 (SI)
/SPI_SCLK: J1.14, U1.14 (SCL), U5.CLK
/SW_ENTER: J1.10, J2.1
/SW_MINUS: J1.11, J2.3
/SW_PLUS: J1.12, J2.2
GND: C1.2, C2.2, C3.2, C4.2, C5.2, C8.2, C9.2, C10.2, C11.2, C12.2, C13.2, C14.2, J1.3, J1.S1 (SHIELD), J1.S2 (SHIELD), J2.4, J3.2, J4.2, J5.2, J6.2, J8.1, Q1.2 (S), Q2.2 (S), R3.2, U1.11 (VSS), U3.2 (GND), U4.4 (VSS), U5.GND, U5.GND1 (GND), U5.GND2 (GND), U5.GND3 (GND), U5.LR
I2C_SCL: J1.5, J3.4, J4.3, J5.3, J6.3, U3.6 (SCL), U4.2 (SCL)
I2C_SDA: J1.4, J3.1, J4.4, J5.4, J6.4, U3.3 (SDA), U4.1 (SDA)
unnamed: C11.1, U3.1 (VDD)
unnamed: D1.2 (A), R2.1
unnamed: D1.1 (K), Q2.3 (D)
unnamed: Q1.3 (D), R1.1
unnamed: C7.1, U1.8 (C1+)
unnamed: C7.2, U1.9 (C1-)
unnamed: C6.2, U1.7 (C2+)
unnamed: C6.1, U1.6 (C2-)
unnamed: R1.2, U1.19 (LED_Kathode_+)
unnamed: C1.1, U1.1 (V0)
unnamed: C2.1, U1.2 (V1)
unnamed: C3.1, U1.3 (V2)
unnamed: C4.1, U1.4 (V3)
unnamed: C5.1, U1.5 (V4)
unnamed: C8.1, U1.10 (VOUT)

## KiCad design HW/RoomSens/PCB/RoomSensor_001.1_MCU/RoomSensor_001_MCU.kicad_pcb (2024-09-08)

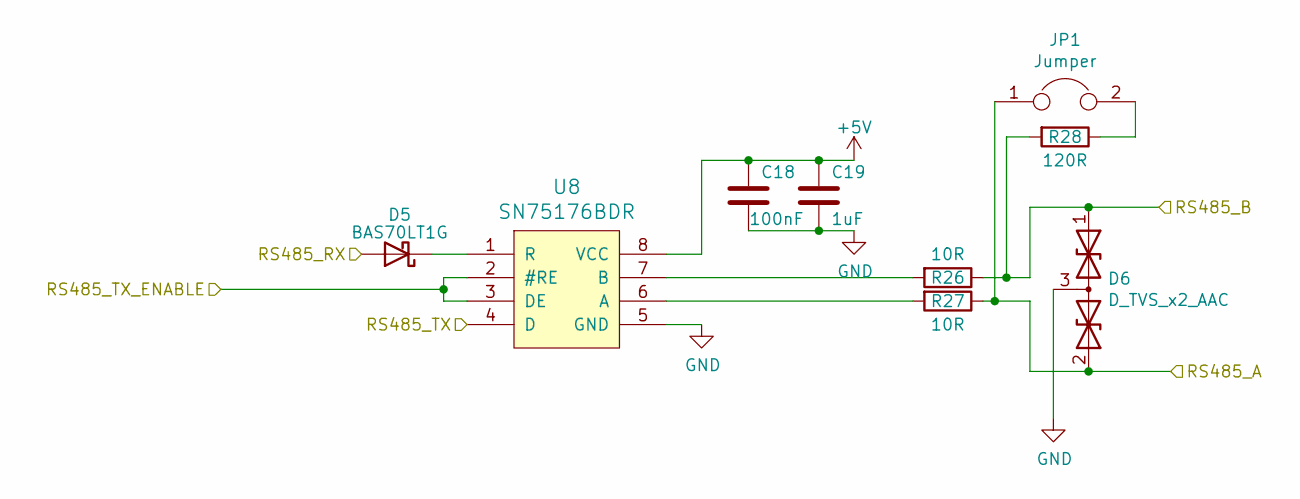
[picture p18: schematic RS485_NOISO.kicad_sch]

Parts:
C18: 100nF; C_0805_2012Metric
C19: 1uF; C_0805_2012Metric
D5: BAS70LT1G; SOT-23
D6: D_TVS_x2_AAC; SOT-23
JP1: Jumper; PinHeader_1x02_P2.54mm_Vertical
R26, R27: 10R; R_0805_2012Metric
R28: 120R; R_1210_3225Metric
U8: SN75176BDR; SOIC-8_3.9x4.9mm_P1.27mm

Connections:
+5V: C18.1, C19.1, U8.8 (VCC); also elsewhere on the board
/Connectors/RS485-A: D6.2 (A2), JP1.1, R27.1; also elsewhere on the board
/Connectors/RS485-B: D6.1 (A1), R26.1, R28.2; also elsewhere on the board
/MCU_PIC18/RS485_RX: U8.4 (D); also elsewhere on the board
/MCU_PIC18/RS485_TX: D5.2 (A); also elsewhere on the board
/MCU_PIC18/RS485_TX_ENABLE: U8.2 (#RE), U8.3 (DE); also elsewhere on the board
GND: C18.2, C19.2, D6.3 (common), U8.5 (GND); also elsewhere on the board
unnamed: D5.1 (K), U8.1 (R)
unnamed 63: JP1.2, R28.1; also elsewhere on the board
unnamed: R27.2, U8.6 (A)
unnamed: R26.2, U8.7 (B)

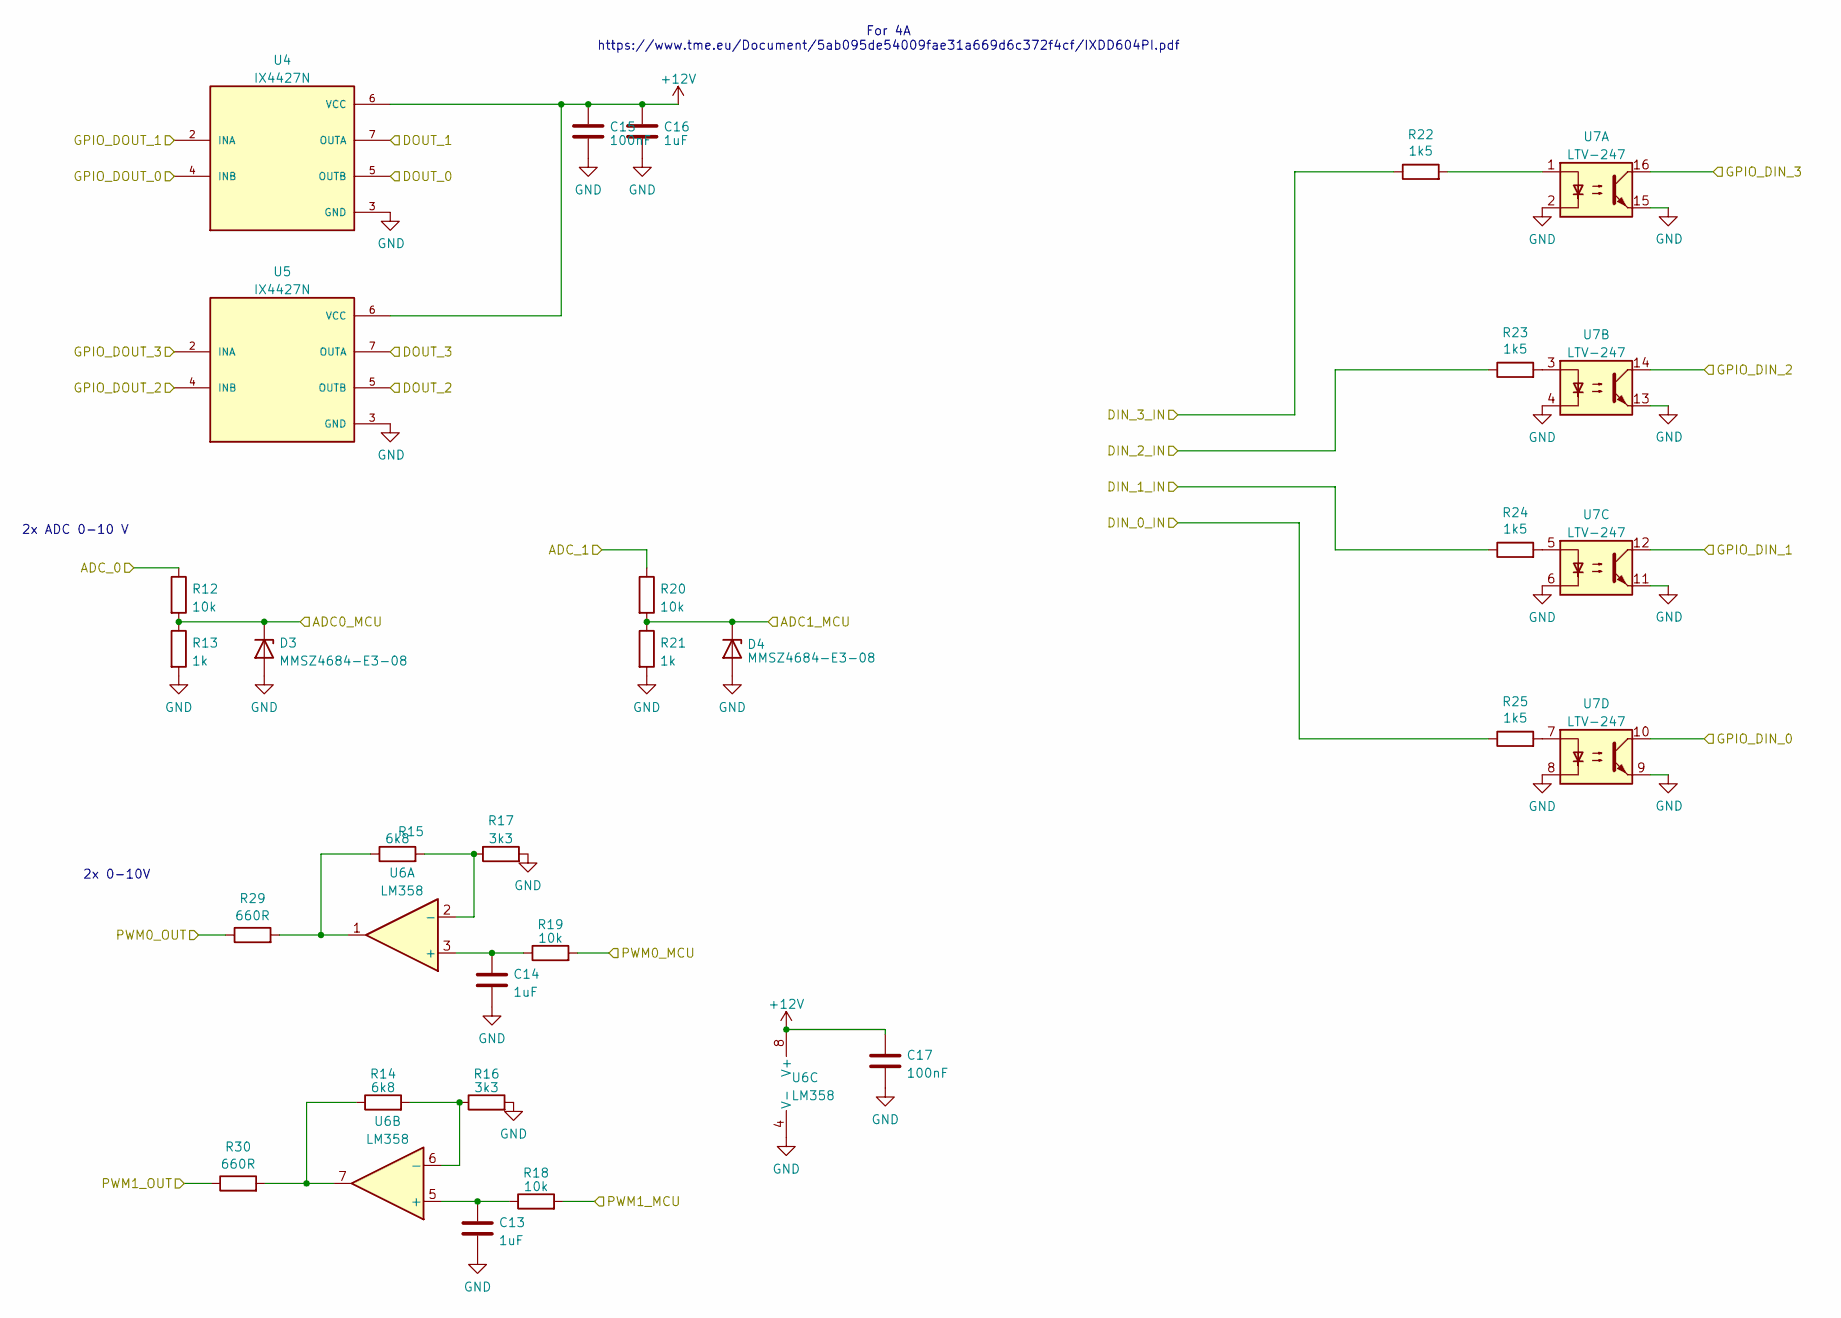
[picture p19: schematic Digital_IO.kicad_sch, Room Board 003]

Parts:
C13, C14, C16: 1uF; C_0805_2012Metric
C15, C17: 100nF; C_0805_2012Metric
D3, D4: MMSZ4684-E3-08; D_SOD-123
R12, R18, R19, R20: 10k; R_0805_2012Metric
R13, R21: 1k; R_0805_2012Metric
R14, R15: 6k8; R_0805_2012Metric
R16, R17: 3k3; R_0805_2012Metric
R22, R23, R24, R25: 1k5; R_0805_2012Metric
R29, R30: 660R; R_0805_2012Metric
U4, U5: IX4427N; SOIC-8_3.9x4.9mm_P1.27mm
U6: LM358; TSSOP-8_4.4x3mm_P0.65mm
U7: LTV-247; SOP-16_4.4x10.4mm_P1.27mm

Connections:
+12V: C15.1, C16.1, C17.1, U4.6 (VCC), U5.6 (VCC), U6.8 (V+); also elsewhere on the board
/Connectors/ADC_0: R12.1; also elsewhere on the board
/Connectors/ADC_1: R20.1; also elsewhere on the board
/Connectors/DAC_0: R29.1; also elsewhere on the board
/Connectors/DAC_1: R30.1; also elsewhere on the board
/Connectors/DIN_0: R25.1; also elsewhere on the board
/Connectors/DIN_1: R24.1; also elsewhere on the board
/Connectors/DIN_2: R23.1; also elsewhere on the board
/Connectors/DIN_3: R22.1; also elsewhere on the board
/Connectors/DOUT_0: U4.5 (OUTB); also elsewhere on the board
/Connectors/DOUT_1: U4.7 (OUTA); also elsewhere on the board
/Connectors/DOUT_2: U5.5 (OUTB); also elsewhere on the board
/Connectors/DOUT_3: U5.7 (OUTA); also elsewhere on the board
/Digital IO/ADC0_MCU: D3.1 (K), R12.2, R13.1; also elsewhere on the board
/Digital IO/ADC1_MCU: D4.1 (K), R20.2, R21.1; also elsewhere on the board
/Digital IO/GPIO_DIN_0: U7.10; also elsewhere on the board
/Digital IO/GPIO_DIN_1: U7.12; also elsewhere on the board
/Digital IO/GPIO_DIN_2: U7.14; also elsewhere on the board
/Digital IO/GPIO_DIN_3: U7.16; also elsewhere on the board
/Digital IO/GPIO_DOUT_0: U4.4 (INB); also elsewhere on the board
/Digital IO/GPIO_DOUT_1: U4.2 (INA); also elsewhere on the board
/Digital IO/GPIO_DOUT_2: U5.4 (INB); also elsewhere on the board
/Digital IO/GPIO_DOUT_3: U5.2 (INA); also elsewhere on the board
/Digital IO/PWM0_MCU: R19.2; also elsewhere on the board
/Digital IO/PWM1_MCU: R18.2; also elsewhere on the board
GND: C13.2, C14.2, C15.2, C16.2, C17.2, D3.2 (A), D4.2 (A), R13.2, R16.2, R17.2, R21.2, U4.3 (GND), U5.3 (GND), U6.4 (V-), U7.2, U7.4, U7.6, U7.8, U7.9, U7.11, U7.13, U7.15; also elsewhere on the board
unnamed: R14.1, R30.2, U6.7
unnamed: R15.1, R29.2, U6.1
unnamed: R22.2, U7.1
unnamed: R23.2, U7.3
unnamed: R24.2, U7.5
unnamed: R25.2, U7.7
unnamed: C14.1, R19.1, U6.3 (+)
unnamed: R15.2, R17.1, U6.2 (-)
unnamed: C13.1, R18.1, U6.5 (+)
unnamed: R14.2, R16.1, U6.6 (-)

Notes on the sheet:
2x 0-10V
2x ADC 0-10 V
For 4A https://www.tme.eu/Document/5ab095de54009fae31a669d6c372f4cf/IXDD604PI.pdf

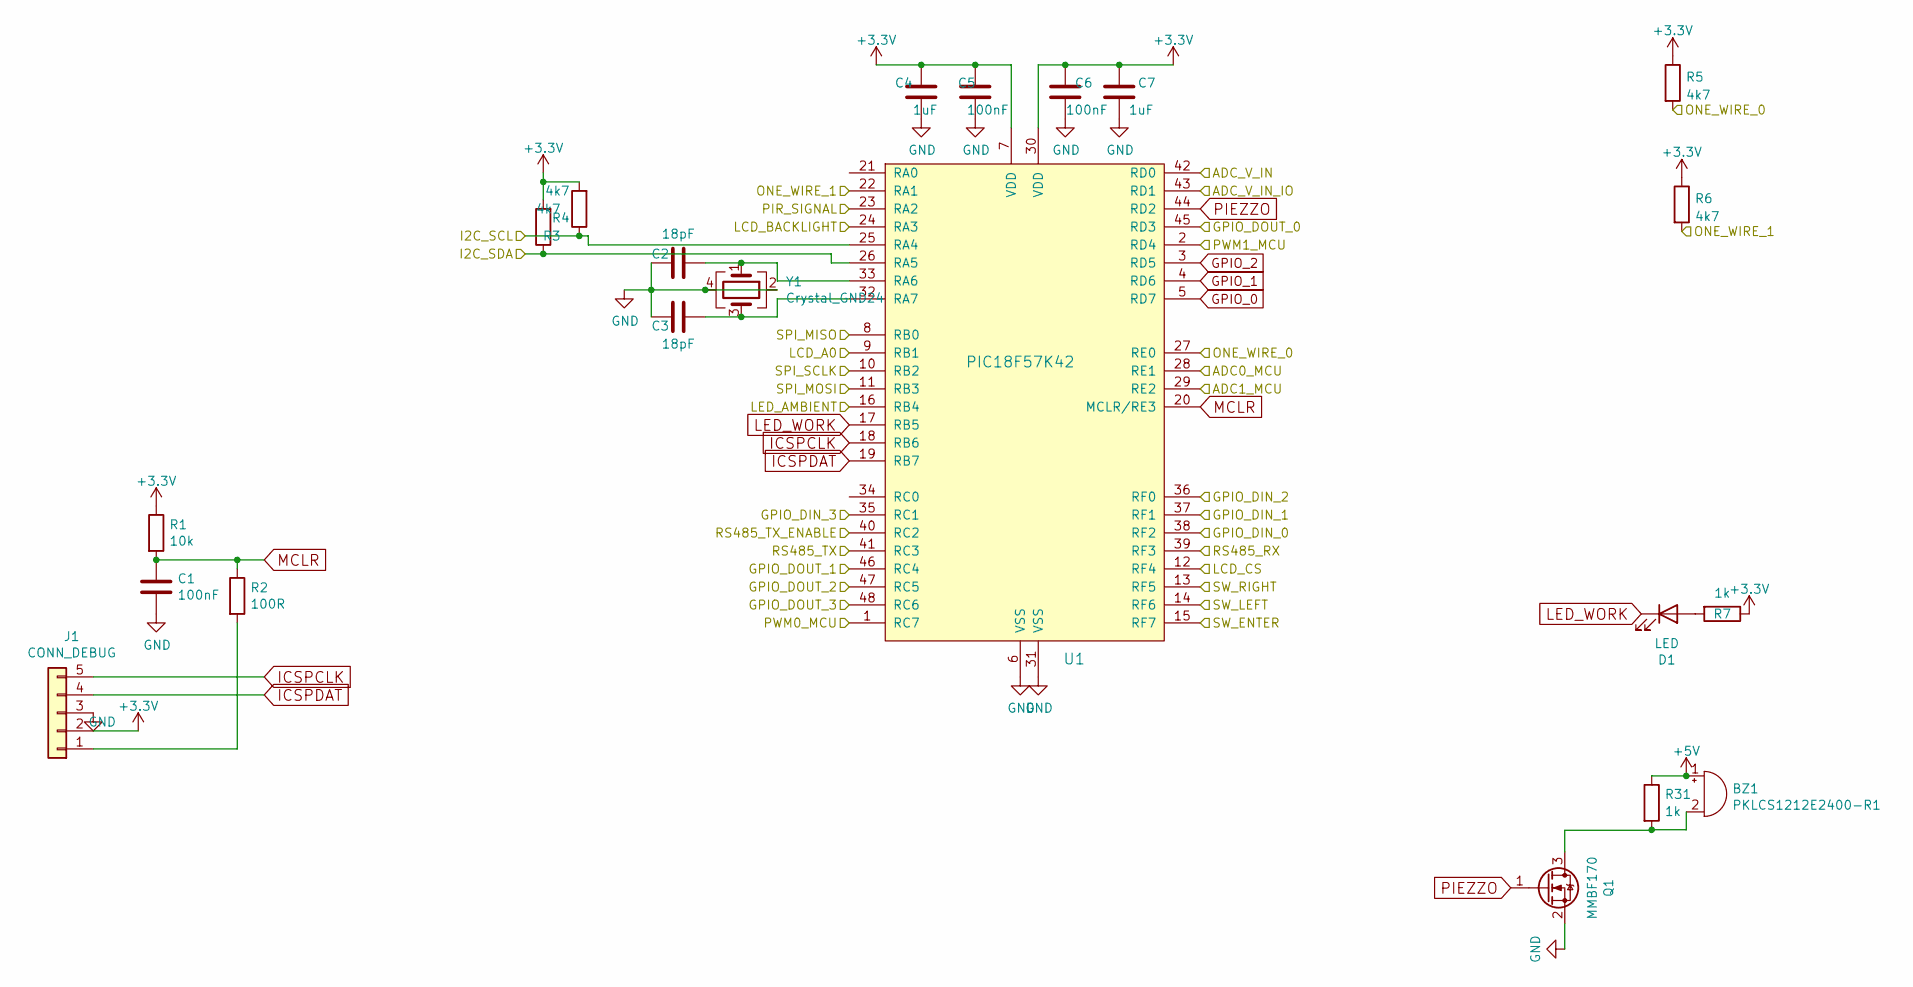
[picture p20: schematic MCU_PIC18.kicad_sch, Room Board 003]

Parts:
BZ1: PKLCS1212E2400-R1; Buzzer_Murata_PKLCS1212E
C1, C5, C6: 100nF; C_0805_2012Metric
C2, C3: 18pF; C_0805_2012Metric
C4, C7: 1uF; C_0805_2012Metric
D1: LED; LED_0805_2012Metric_Pad1.15x1.40mm_HandSolder
J1: CONN_DEBUG; PinHeader_1x05_P2.54mm_Vertical
Q1: MMBF170; SOT-23
R1: 10k; R_0805_2012Metric
R2: 100R; R_0805_2012Metric
R3, R4, R5, R6: 4k7; R_0805_2012Metric
R7, R31: 1k; R_0805_2012Metric
U1: PIC18F57K42; TQFP-48_7x7mm_P0.5mm
Y1: Crystal_GND24; Crystal_SMD_SeikoEpson_FA238-4Pin_3.2x2.5mm

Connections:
+3.3V: C4.1, C5.1, C6.1, C7.1, J1.2, R1.1, R3.2, R4.2, R5.1, R6.1, R7.1, U1.7 (VDD), U1.30 (VDD); also elsewhere on the board
+5V: BZ1.1 (-), R31.1; also elsewhere on the board
/Connectors/I2C_SCL: R4.1, U1.25 (RA4); also elsewhere on the board
/Connectors/I2C_SDA: R3.1, U1.26 (RA5); also elsewhere on the board
/Connectors/LCD_A0: U1.9 (RB1); also elsewhere on the board
/Connectors/LCD_BACKLIGHT: U1.24 (RA3); also elsewhere on the board
/Connectors/LCD_CS: U1.12 (RF4); also elsewhere on the board
/Connectors/LED_AMBIENT: U1.16 (RB4); also elsewhere on the board
/Connectors/ONE_WIRE_0: R5.2, U1.27 (RE0); also elsewhere on the board
/Connectors/ONE_WIRE_1: R6.2, U1.22 (RA1); also elsewhere on the board
/Connectors/PIR: U1.23 (RA2); also elsewhere on the board
/Connectors/SPI_MISO: U1.8 (RB0); also elsewhere on the board
/Connectors/SPI_MOSI: U1.11 (RB3); also elsewhere on the board
/Connectors/SPI_SCLK: U1.10 (RB2); also elsewhere on the board
/Connectors/SW_ENTER: U1.15 (RF7); also elsewhere on the board
/Connectors/SW_MINUS: U1.14 (RF6); also elsewhere on the board
/Connectors/SW_PLUS: U1.13 (RF5); also elsewhere on the board
/Digital IO/ADC0_MCU: U1.28 (RE1); also elsewhere on the board
/Digital IO/ADC1_MCU: U1.29 (RE2); also elsewhere on the board
/Digital IO/GPIO_DIN_0: U1.38 (RF2); also elsewhere on the board
/Digital IO/GPIO_DIN_1: U1.37 (RF1); also elsewhere on the board
/Digital IO/GPIO_DIN_2: U1.36 (RF0); also elsewhere on the board
/Digital IO/GPIO_DIN_3: U1.35 (RC1); also elsewhere on the board
/Digital IO/GPIO_DOUT_0: U1.45 (RD3); also elsewhere on the board
/Digital IO/GPIO_DOUT_1: U1.46 (RC4); also elsewhere on the board
/Digital IO/GPIO_DOUT_2: U1.47 (RC5); also elsewhere on the board
/Digital IO/GPIO_DOUT_3: U1.48 (RC6); also elsewhere on the board
/Digital IO/PWM0_MCU: U1.1 (RC7); also elsewhere on the board
/Digital IO/PWM1_MCU: U1.2 (RD4); also elsewhere on the board
/MCU_PIC18/ADC_V_IN: U1.42 (RD0); also elsewhere on the board
/MCU_PIC18/ADC_V_IN_IO: U1.43 (RD1); also elsewhere on the board
/MCU_PIC18/RS485_RX: U1.39 (RF3); also elsewhere on the board
/MCU_PIC18/RS485_TX: U1.41 (RC3); also elsewhere on the board
/MCU_PIC18/RS485_TX_ENABLE: U1.40 (RC2); also elsewhere on the board
GND: C1.2, C2.2, C3.2, C4.2, C5.2, C6.2, C7.2, J1.3, Q1.2 (S), U1.6 (VSS), U1.31 (VSS), Y1.2, Y1.4; also elsewhere on the board
GPIO_0: U1.5 (RD7)
GPIO_1: U1.4 (RD6)
GPIO_2: U1.3 (RD5)
ICSPCLK: J1.5, U1.18 (RB6); also elsewhere on the board
ICSPDAT: J1.4, U1.19 (RB7); also elsewhere on the board
LED_WORK: D1.1 (K), U1.17 (RB5)
MCLR: C1.1, R1.2, R2.1, U1.20 (MCLR/RE3)
unnamed: BZ1.2 (+), Q1.3 (D), R31.2
unnamed: D1.2 (A), R7.2
unnamed 62: J1.1, R2.2; also elsewhere on the board
unnamed: C2.1, U1.33 (RA6), Y1.1
unnamed: C3.1, U1.32 (RA7), Y1.3
PIEZZO: Q1.1 (G), U1.44 (RD2)

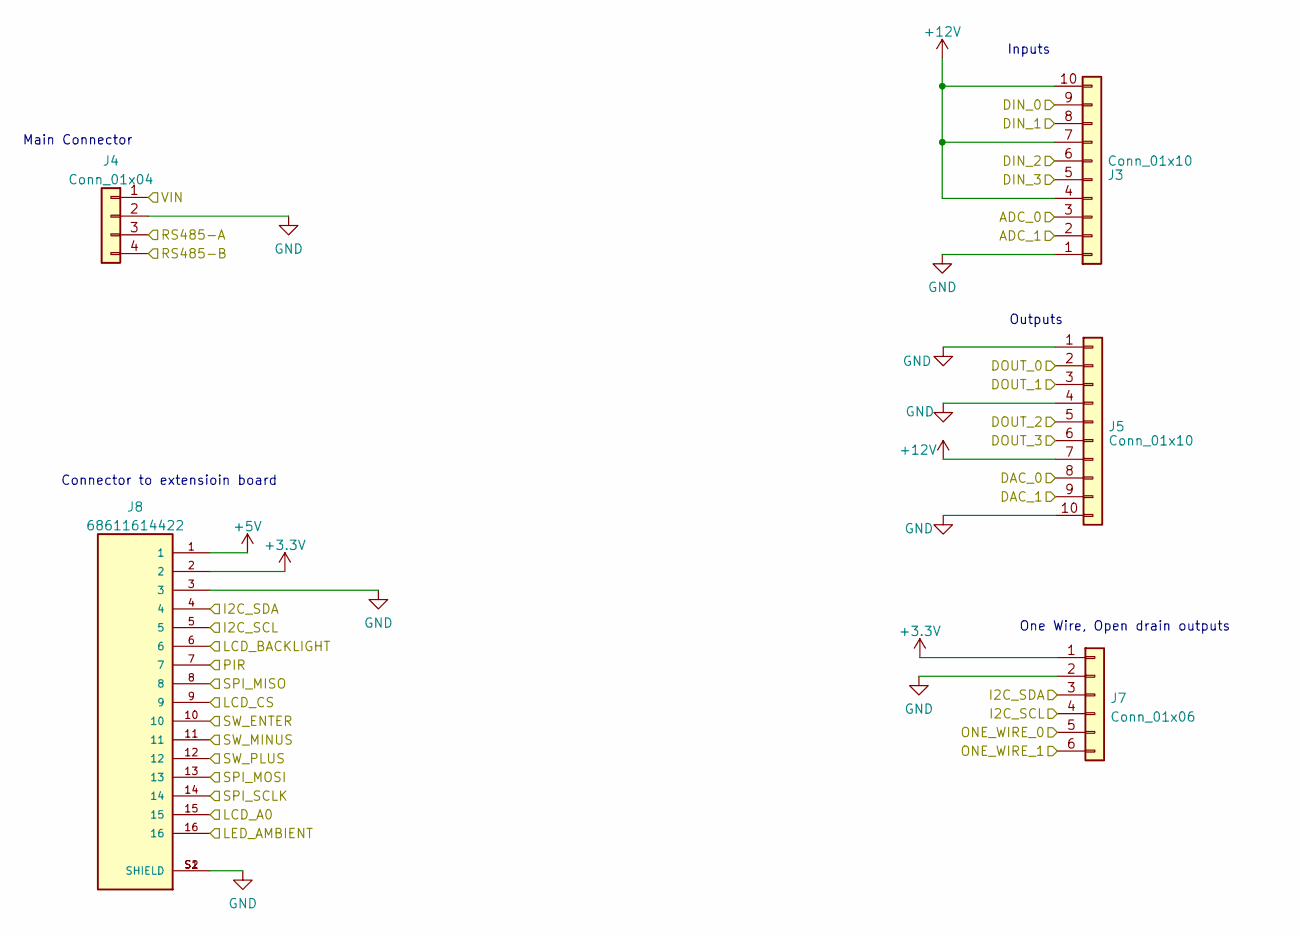
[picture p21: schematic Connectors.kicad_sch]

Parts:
J3, J5: Conn_01x10; PhoenixContact_MCV_1,5_10-G-3.5_1x10_P3.50mm_Vertical
J4: Conn_01x04; PhoenixContact_MSTBVA_2,5_4-G_1x04_P5.00mm_Vertical
J7: Conn_01x06; PinSocket_2x03_P2.54mm_Vertical
J8: 68611614422; WURTH_68611614422; PARTREV 001.006

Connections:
+3.3V: J7.1, J8.2; also elsewhere on the board
+5V: J8.1; also elsewhere on the board
+12V: J3.4, J3.7, J3.10, J5.7; also elsewhere on the board
/Connectors/ADC_0: J3.3; also elsewhere on the board
/Connectors/ADC_1: J3.2; also elsewhere on the board
/Connectors/DAC_0: J5.8; also elsewhere on the board
/Connectors/DAC_1: J5.9; also elsewhere on the board
/Connectors/DIN_0: J3.9; also elsewhere on the board
/Connectors/DIN_1: J3.8; also elsewhere on the board
/Connectors/DIN_2: J3.6; also elsewhere on the board
/Connectors/DIN_3: J3.5; also elsewhere on the board
/Connectors/DOUT_0: J5.2; also elsewhere on the board
/Connectors/DOUT_1: J5.3; also elsewhere on the board
/Connectors/DOUT_2: J5.5; also elsewhere on the board
/Connectors/DOUT_3: J5.6; also elsewhere on the board
/Connectors/I2C_SCL: J7.4, J8.5; also elsewhere on the board
/Connectors/I2C_SDA: J7.3, J8.4; also elsewhere on the board
/Connectors/LCD_A0: J8.15; also elsewhere on the board
/Connectors/LCD_BACKLIGHT: J8.6; also elsewhere on the board
/Connectors/LCD_CS: J8.9; also elsewhere on the board
/Connectors/LED_AMBIENT: J8.16; also elsewhere on the board
/Connectors/ONE_WIRE_0: J7.5; also elsewhere on the board
/Connectors/ONE_WIRE_1: J7.6; also elsewhere on the board
/Connectors/PIR: J8.7; also elsewhere on the board
/Connectors/RS485-A: J4.3; also elsewhere on the board
/Connectors/RS485-B: J4.4; also elsewhere on the board
/Connectors/SPI_MISO: J8.8; also elsewhere on the board
/Connectors/SPI_MOSI: J8.13; also elsewhere on the board
/Connectors/SPI_SCLK: J8.14; also elsewhere on the board
/Connectors/SW_ENTER: J8.10; also elsewhere on the board
/Connectors/SW_MINUS: J8.11; also elsewhere on the board
/Connectors/SW_PLUS: J8.12; also elsewhere on the board
/Connectors/VIN: J4.1; also elsewhere on the board
GND: J3.1, J4.2, J5.1, J5.4, J5.10, J7.2, J8.3, J8.S1 (SHIELD), J8.S2 (SHIELD); also elsewhere on the board

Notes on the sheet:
Connector to extensioin board
Inputs
Main Connector
One Wire, Open drain outputs
Outputs

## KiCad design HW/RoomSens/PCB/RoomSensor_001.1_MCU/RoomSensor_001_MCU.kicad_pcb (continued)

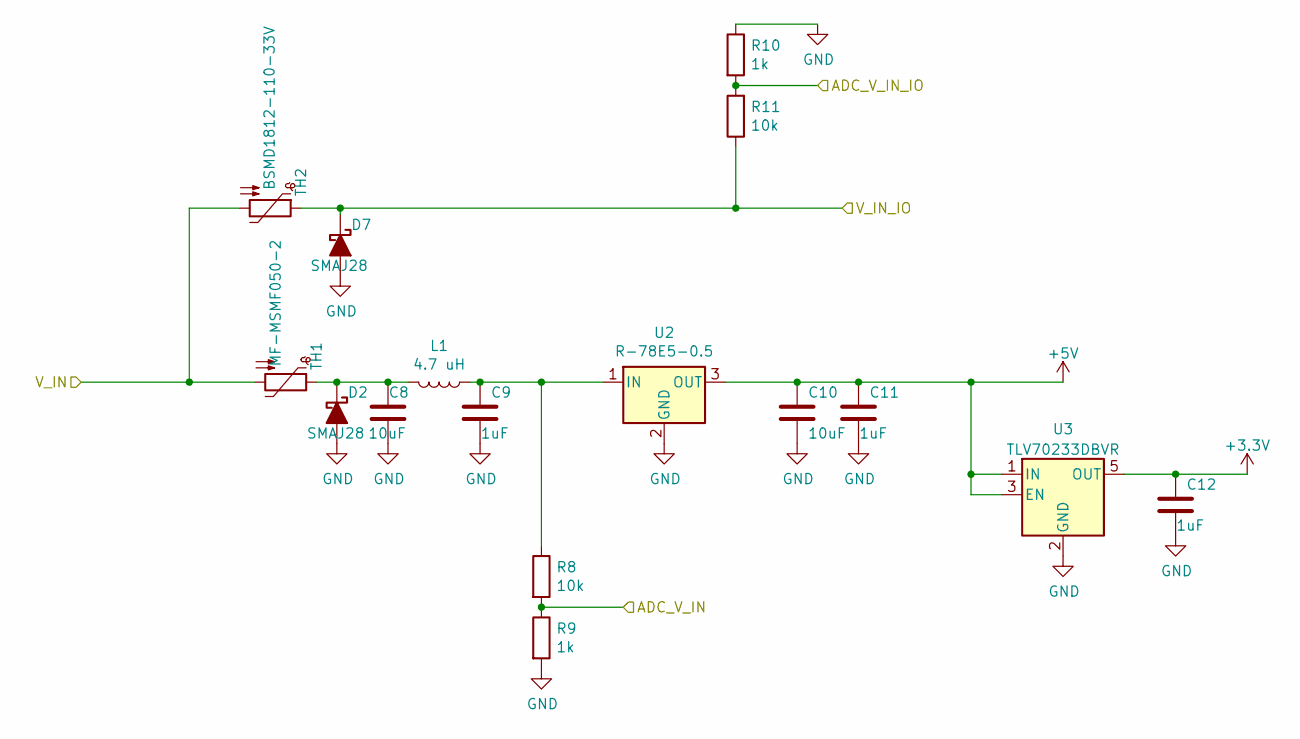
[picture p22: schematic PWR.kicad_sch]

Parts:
C8, C10: 10uF; C_1210_3225Metric
C9, C11, C12: 1uF; C_0805_2012Metric
D2, D7: SMAJ28; D_SMA
L1: 4.7 uH; L_0805_2012Metric
R8, R11: 10k; R_0805_2012Metric
R9, R10: 1k; R_0805_2012Metric
TH1: MF-MSMF050-2; Fuse_1812_4532Metric_Pad1.30x3.40mm_HandSolder
TH2: BSMD1812-110-33V; Fuse_1812_4532Metric_Pad1.30x3.40mm_HandSolder
U2: R-78E5-0.5; Converter_DCDC_RECOM_R-78E-0.5_THT
U3: TLV70233DBVR; SOT-23-5

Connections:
+3.3V: C12.1, U3.5 (OUT); also elsewhere on the board
+5V: C10.1, C11.1, U2.3 (OUT), U3.1 (IN), U3.3 (EN); also elsewhere on the board
+12V: D7.1 (K), R11.1, TH2.1; also elsewhere on the board
/Connectors/VIN: TH1.2, TH2.2; also elsewhere on the board
/MCU_PIC18/ADC_V_IN: R8.2, R9.1; also elsewhere on the board
/MCU_PIC18/ADC_V_IN_IO: R10.2, R11.2; also elsewhere on the board
GND: C8.2, C9.2, C10.2, C11.2, C12.2, D2.2 (A), D7.2 (A), R9.2, R10.1, U2.2 (GND), U3.2 (GND); also elsewhere on the board
unnamed: C8.1, D2.1 (K), L1.2, TH1.1
unnamed: C9.1, L1.1, R8.1, U2.1 (IN)

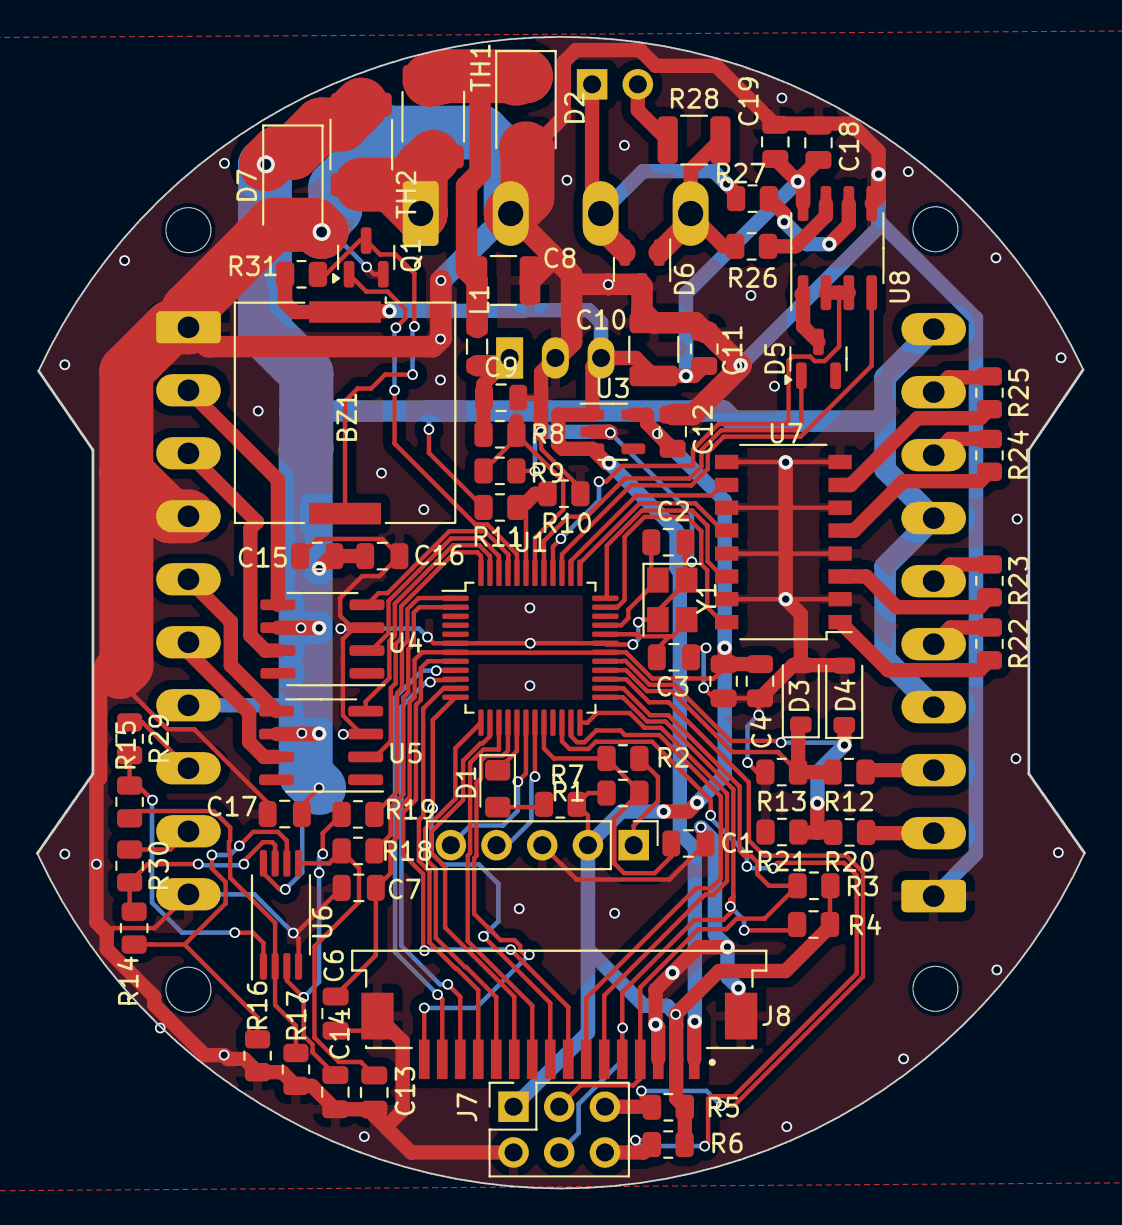
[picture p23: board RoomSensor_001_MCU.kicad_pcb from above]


Board: 2 copper layers, 58.2 x 64.0 mm, 82 parts (5 on the bottom side), 77 nets.

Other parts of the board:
 : MountingHole_2.5mm
 #2,  #3,  #4: MountingHole_2.5mm
MCU: CONN_DEBUG; PinHeader_1x05_P2.54mm_Vertical
Term.: Jumper; PinHeader_1x02_P2.54mm_Vertical

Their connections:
+3.3V: MCU.2; also elsewhere on the board
/Connectors/RS485-A: Term..1; also elsewhere on the board
GND: MCU.3; also elsewhere on the board
ICSPCLK: MCU.5; also elsewhere on the board
ICSPDAT: MCU.4; also elsewhere on the board
unnamed 62: MCU.1; also elsewhere on the board
unnamed 63: Term..2; also elsewhere on the board

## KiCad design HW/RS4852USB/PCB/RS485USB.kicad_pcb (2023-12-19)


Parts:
C1: 100nF / 600V; C_1812_4532Metric_Pad1.57x3.40mm_HandSolder
J1: Conn_01x03; PhoenixContact_MSTBV_2,5_3-GF_1x03_P5.00mm_Vertical_Threade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
J2: USB4145-03-0170-C; GCT_USB4145
R1: 1k / 600V; R_Axial_DIN0309_L9.0mm_D3.2mm_P12.70mm_Horizontal
R2, R3: 5.1 k; R_0805_2012Metric

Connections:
+5V: J2.A4 (VBUS), J2.A9 (VBUS), J2.B4 (VBUS), J2.B9 (VBUS); also elsewhere on the board
/USB HUB 4/USB_DM: J2.A7 (D-), J2.B7 (D-); also elsewhere on the board
/USB HUB 4/USB_DP: J2.A6 (D+), J2.B6 (D+); also elsewhere on the board
Earth: C1.2, J1.3, R1.2
GND: J2.A1 (GND), J2.A12 (GND), J2.B1 (GND), J2.B12 (GND), J2.S1 (SHIELD), R2.2, R3.2; also elsewhere on the board
GND1: C1.1, J1.2, R1.1; also elsewhere on the board
unnamed: J2.A5 (CC1), R2.1
unnamed: J2.B5 (CC2), R3.1
VCC: J1.1; also elsewhere on the board


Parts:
C18, C21: 1uF; C_0805_2012Metric
C19, C20: 16 pF; C_0805_2012Metric
C22, C24, C25, C26, C27, C28, C29, C30, C31, C32: 22pF; C_0805_2012Metric
C23: 100nF; C_0805_2012Metric
R24, R26, R29, R30, R31, R32, R33, R34, R35, R36: 27R; R_0805_2012Metric
R25, R28: 1k5; R_0805_2012Metric
R27: 1.5k; R_0805_2012Metric
R37, R38, R39, R40, R41, R42, R43, R44: 15k; R_0805_2012Metric
U13: USBLC6-2SC6; SOT-23-6
U14: TUSB2046B; LQFP-32_7x7mm_P0.8mm
Y1: AB308-6.000MHZ; Crystal_C38-LF_D3.0mm_L8.0mm_Horizontal

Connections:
+5V: U13.5 (VBUS); also elsewhere on the board
/RS485_ISO1/USB_DM: R32.1, R42.2; also elsewhere on the board
/RS485_ISO1/USB_DP: R31.1, R38.2; also elsewhere on the board
/RS485_ISO2/USB_DM: R34.1, R43.2; also elsewhere on the board
/RS485_ISO2/USB_DP: R33.1, R39.2; also elsewhere on the board
/RS485_ISO3/USB_DM: R36.1, R44.2; also elsewhere on the board
/RS485_ISO3/USB_DP: R35.1, R40.2; also elsewhere on the board
/RS485_ISO/USB_DM: R30.1, R41.2; also elsewhere on the board
/RS485_ISO/USB_DP: R29.1, R37.2; also elsewhere on the board
/USB HUB 4/USB_DM: R26.2; also elsewhere on the board
/USB HUB 4/USB_DP: R24.2; also elsewhere on the board
GND: C18.2, C19.2, C20.2, C21.2, C22.2, C23.2, C24.2, C25.2, C26.2, C27.2, C28.2, C29.2, C30.2, C31.2, C32.2, R27.1, R37.1, R38.1, R39.1, R40.1, R41.1, R42.1, R43.1, R44.1, U13.2 (GND), U14.7 (GND), U14.27 (TSPPLL/48MCLK), U14.28 (GND), U14.31 (TSTMODE); also elsewhere on the board
unnamed: R24.1, U13.6 (IO1)
unnamed: R26.1, U13.4 (IO2)
unnamed: R27.2, U14.6 (EEDATA/GANGED), U14.8 (BUSPWR)
unnamed: C24.1, U13.3 (IO2), U14.2 (DM0)
unnamed: C29.1, R30.2, U14.11 (DM1)
unnamed: C30.1, R32.2, U14.15 (DM2)
unnamed: C31.1, R34.2, U14.19 (DM3)
unnamed: C32.1, R36.2, U14.23 (DM4)
unnamed: C22.1, R28.2, U13.1 (IO1), U14.1 (DP0)
unnamed: C25.1, R29.2, U14.12 (DP1)
unnamed: C26.1, R31.2, U14.16 (DP2)
unnamed: C27.1, R33.2, U14.20 (DP3)
unnamed: C28.1, R35.2, U14.24 (DP4)
unnamed: C18.1, R25.1, U14.4 (RESET)
unnamed: C20.1, U14.30 (XTAL1), Y1.2
unnamed: C19.1, U14.29 (XTAL2), Y1.1

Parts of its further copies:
C8: 100nF; C_0805_2012Metric

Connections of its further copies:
+5VD: C8.1; also elsewhere on the board
GND1: C8.2; also elsewhere on the board


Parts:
C33, C37, C38: 10uF; C_1210_3225Metric
C34, C35, C39, C40: 1uF; C_0805_2012Metric
C36: 100nF; C_0805_2012Metric
D5: SMAJ28A; D_SMA
D6: LED Green; LED_0805_2012Metric
PS1: NML0505SC; NML0505S; PARTREV April 19, 2021
R45: 1.5k; R_0805_2012Metric
TH5: Thermistor_PTC; R_1812_4532Metric
U15: TLV70233DBVR; SOT-23-5
U16: R-78E5.0-1.0; Converter_DCDC_RECOM_R-78E-0.5_THT

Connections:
+5V: C38.1, C40.1, PS1.4 (+VOUT), U15.1 (IN), U15.3 (EN); also elsewhere on the board
+5VD: C37.1, C39.1, D6.2 (A), PS1.2 (+VIN(VCC)), U16.3 (OUT); also elsewhere on the board
GND: C35.2, C36.2, C38.2, C40.2, PS1.3 (-VOUT), U15.2 (GND); also elsewhere on the board
GND1: C33.2, C34.2, C37.2, C39.2, D5.2 (A), PS1.1 (-VIN(GND)), R45.2, U16.2 (GND); also elsewhere on the board
unnamed: C33.1, C34.1, D5.1 (K), TH5.2, U16.1 (IN)
unnamed: D6.1 (K), R45.1
VCC: TH5.1; also elsewhere on the board

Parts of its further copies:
C12: 100nF; C_0805_2012Metric

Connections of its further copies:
+5VD: C12.1; also elsewhere on the board
GND1: C12.2; also elsewhere on the board

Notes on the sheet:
1000mA for 4x RS-485 tranceivers
Power for 1xx USB HUB, 4x FTDI, ISOLATORS


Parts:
C2, C3, C4: 100nF; C_0805_2012Metric
C5: 1uF; C_0805_2012Metric
D1: CDSOT23-T15C; SOT-23
J3: RJ45_LED_Shielded; RJ45_Amphenol_RJHSE3384
R4, R5: 330R; R_0805_2012Metric
R6, R7: 10R; R_0805_2012Metric
R8: 120R; R_1210_3225Metric
TH1: 0ZCG0075BF2B; R_1812_4532Metric
U1: FT230XS; SSOP-16_3.9x4.9mm_P0.635mm
U2: ISO7331C (PAI131M31); SO-16_3.9x9.9mm_P1.27mm
U3: SN75176BDR; SOIC-8_3.9x4.9mm_P1.27mm

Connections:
+5V: C3.1, J3.10, J3.12, U1.12 (VCC); also elsewhere on the board
+5VD: C4.1, C5.1, U2.16 (VCC2), U3.8 (VCC); also elsewhere on the board
/RS485_ISO/RS485_A: D1.2 (A2), J3.6, R7.1, R8.1
/RS485_ISO/RS485_B: D1.1 (A1), J3.3, R6.1, R8.2
/RS485_ISO/USB_DM: U1.9 (USBDM); also elsewhere on the board
/RS485_ISO/USB_DP: U1.8 (USBDP); also elsewhere on the board
GND: C2.2, C3.2, U1.5 (GND), U1.13 (GND), U2.2 (GND1), U2.8 (GND1); also elsewhere on the board
GND1: C4.2, C5.2, D1.3 (common), J3.4, J3.5, J3.SH, U2.9 (GND2), U2.15 (GND2), U3.5 (GND); also elsewhere on the board
unnamed: J3.1, J3.2, TH1.1
unnamed: J3.9, R4.1
unnamed: J3.11, R5.2
unnamed: U1.15 (CBUS0), U2.4 (INB)
unnamed: R4.2, U1.14 (CBUS1)
unnamed: R5.1, U1.7 (CBUS2)
unnamed: U1.4 (RXD), U2.5 (OUTC)
unnamed: U1.1 (TXD), U2.3 (INA)
unnamed: U2.12 (INC), U3.1 (R)
unnamed: U2.14 (OUTA), U3.4 (D)
unnamed: U2.13 (OUTB), U3.2 (#RE), U3.3 (DE)
unnamed: R7.2, U3.6 (A)
unnamed: R6.2, U3.7 (B)
VCC: TH1.2; also elsewhere on the board

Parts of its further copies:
C6, C7, C8, C10, C11, C12, C14, C15, C16: 100nF; C_0805_2012Metric
C9, C13, C17: 1uF; C_0805_2012Metric
D2, D3, D4: CDSOT23-T15C; SOT-23
J4, J5, J6: RJ45_LED_Shielded; RJ45_Amphenol_RJHSE3384
R9, R10, R14, R15, R19, R20: 330R; R_0805_2012Metric
R11, R12, R16, R17, R21, R22: 10R; R_0805_2012Metric
R13, R18, R23: 120R; R_1210_3225Metric
U4, U7, U10: FT230XS; SSOP-16_3.9x4.9mm_P0.635mm
U5, U11: ISO7331C (PAI131M31); SO-16_3.9x9.9mm_P1.27mm
U6, U9, U12: SN75176BDR; SOIC-8_3.9x4.9mm_P1.27mm

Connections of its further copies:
+5V: C7.1, C11.1, C15.1, J4.10, J4.12, J5.10, J5.12, J6.10, J6.12, U4.12 (VCC), U7.12 (VCC), U10.12 (VCC); also elsewhere on the board
+5VD: C8.1, C9.1, C12.1, C13.1, C16.1, C17.1, U5.16 (VCC2), U6.8 (VCC), U9.8 (VCC), U11.16 (VCC2), U12.8 (VCC); also elsewhere on the board
/RS485_ISO1/RS485_A: D2.2 (A2), J4.6, R12.1, R13.1
/RS485_ISO1/RS485_B: D2.1 (A1), J4.3, R11.1, R13.2
/RS485_ISO1/USB_DM: U4.9 (USBDM); also elsewhere on the board
/RS485_ISO1/USB_DP: U4.8 (USBDP); also elsewhere on the board
/RS485_ISO2/RS485_A: D3.2 (A2), J5.6, R17.1, R18.1
/RS485_ISO2/RS485_B: D3.1 (A1), J5.3, R16.1, R18.2
/RS485_ISO2/USB_DM: U7.9 (USBDM); also elsewhere on the board
/RS485_ISO2/USB_DP: U7.8 (USBDP); also elsewhere on the board
/RS485_ISO3/RS485_A: D4.2 (A2), J6.6, R22.1, R23.1
/RS485_ISO3/RS485_B: D4.1 (A1), J6.3, R21.1, R23.2
/RS485_ISO3/USB_DM: U10.9 (USBDM); also elsewhere on the board
/RS485_ISO3/USB_DP: U10.8 (USBDP); also elsewhere on the board
GND: C6.2, C7.2, C10.2, C11.2, C14.2, C15.2, U4.5 (GND), U4.13 (GND), U5.2 (GND1), U5.8 (GND1), U7.5 (GND), U7.13 (GND), U10.5 (GND), U10.13 (GND), U11.2 (GND1), U11.8 (GND1); also elsewhere on the board
GND1: C8.2, C9.2, C12.2, C13.2, C16.2, C17.2, D2.3 (common), D3.3 (common), D4.3 (common), J4.4, J4.5, J4.SH, J5.4, J5.5, J5.SH, J6.4, J6.5, J6.SH, U5.9 (GND2), U5.15 (GND2), U6.5 (GND), U9.5 (GND), U11.9 (GND2), U11.15 (GND2), U12.5 (GND); also elsewhere on the board
unnamed 30: J4.1, J4.2; also elsewhere on the board
unnamed: J4.9, R9.1
unnamed: J4.11, R10.2
unnamed 33: J5.1, J5.2; also elsewhere on the board
unnamed: J5.9, R14.1
unnamed: J5.11, R15.2
unnamed 36: J6.1, J6.2; also elsewhere on the board
unnamed: J6.9, R19.1
unnamed: J6.11, R20.2
unnamed: U4.15 (CBUS0), U5.4 (INB)
unnamed: R9.2, U4.14 (CBUS1)
unnamed: R10.1, U4.7 (CBUS2)
unnamed: U4.4 (RXD), U5.5 (OUTC)
unnamed: U4.1 (TXD), U5.3 (INA)
unnamed: U5.12 (INC), U6.1 (R)
unnamed: U5.14 (OUTA), U6.4 (D)
unnamed: U5.13 (OUTB), U6.2 (#RE), U6.3 (DE)
unnamed: R12.2, U6.6 (A)
unnamed: R11.2, U6.7 (B)
unnamed 61: U7.15 (CBUS0); also elsewhere on the board
unnamed: R14.2, U7.14 (CBUS1)
unnamed: R15.1, U7.7 (CBUS2)
unnamed 64: U7.4 (RXD); also elsewhere on the board
unnamed 65: U7.1 (TXD); also elsewhere on the board
unnamed 66: U9.1 (R); also elsewhere on the board
unnamed 67: U9.4 (D); also elsewhere on the board
unnamed 68: U9.2 (#RE), U9.3 (DE); also elsewhere on the board
unnamed: R17.2, U9.6 (A)
unnamed: R16.2, U9.7 (B)
unnamed: U10.15 (CBUS0), U11.4 (INB)
unnamed: R19.2, U10.14 (CBUS1)
unnamed: R20.1, U10.7 (CBUS2)
unnamed: U10.4 (RXD), U11.5 (OUTC)
unnamed: U10.1 (TXD), U11.3 (INA)
unnamed: U11.12 (INC), U12.1 (R)
unnamed: U11.14 (OUTA), U12.4 (D)
unnamed: U11.13 (OUTB), U12.2 (#RE), U12.3 (DE)
unnamed: R22.2, U12.6 (A)
unnamed: R21.2, U12.7 (B)

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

Board: 2 copper layers, 68.0 x 87.0 mm, 120 parts (0 on the bottom side), 97 nets.

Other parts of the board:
TH2, TH3, TH4: Thermistor_PTC; R_1812_4532Metric
U8: ISO7331C (PAI131M31); SO-16_3.9x9.9mm_P1.27mm

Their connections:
+5VD: U8.16 (VCC2); also elsewhere on the board
GND: U8.2 (GND1), U8.8 (GND1); also elsewhere on the board
GND1: U8.9 (GND2), U8.15 (GND2); also elsewhere on the board
unnamed 30: TH2.1; also elsewhere on the board
unnamed 33: TH3.1; also elsewhere on the board
unnamed 36: TH4.1; also elsewhere on the board
unnamed 61: U8.4 (INB); also elsewhere on the board
unnamed 64: U8.5 (OUTC); also elsewhere on the board
unnamed 65: U8.3 (INA); also elsewhere on the board
unnamed 66: U8.12 (INC); also elsewhere on the board
unnamed 67: U8.14 (OUTA); also elsewhere on the board
unnamed 68: U8.13 (OUTB); also elsewhere on the board
VCC: TH2.2, TH3.2, TH4.2; also elsewhere on the board

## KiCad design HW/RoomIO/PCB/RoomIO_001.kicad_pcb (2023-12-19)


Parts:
C20: 100nF; C_0805_2012Metric
C21: 1uF; C_0805_2012Metric
D5: BAS70; SOT-23
D6: D_TVS_x2_AAC; SOT-23
JP1: Jumper; PinHeader_1x02_P2.54mm_Vertical
R30, R31: 10R; R_0805_2012Metric
R32: 120R; R_1210_3225Metric
U11: SN75176BDR; SOIC-8_3.9x4.9mm_P1.27mm

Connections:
+5V: C20.1, C21.1, U11.8 (VCC); also elsewhere on the board
/Connectors/RS485-A: D6.2 (A2), JP1.1, R31.1; also elsewhere on the board
/Connectors/RS485-B: D6.1 (A1), R30.1, R32.2; also elsewhere on the board
/MCU_PIC18/RS485_RX: U11.4 (D); also elsewhere on the board
/MCU_PIC18/RS485_TX: D5.2 (A); also elsewhere on the board
/MCU_PIC18/RS485_TX_ENABLE: U11.2 (#RE), U11.3 (DE); also elsewhere on the board
GND: C20.2, C21.2, D6.3 (common), U11.5 (GND); also elsewhere on the board
unnamed: D5.1 (K), U11.1 (R)
unnamed 64: JP1.2, R32.1; also elsewhere on the board
unnamed: R31.2, U11.6 (A)
unnamed: R30.2, U11.7 (B)

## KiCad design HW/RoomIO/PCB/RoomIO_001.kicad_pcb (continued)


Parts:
C13, C14, C15, C18: 1uF; C_0805_2012Metric
C16, C17, C19: 100nF; C_0805_2012Metric
D3, D4: MMSZ4684-E3-08; D_SOD-123
R12, R18, R19, R20: 10k; R_0805_2012Metric
R13, R21: 1k; R_0805_2012Metric
R14, R15: 6k8; R_0805_2012Metric
R16, R17: 3k3; R_0805_2012Metric
R22, R23, R24, R25, R26, R27, R28, R29: 1k5; R_0805_2012Metric
U4, U5, U7, U8: IX4427N; SOIC-8_3.9x4.9mm_P1.27mm
U6: LM358; TSSOP-8_4.4x3mm_P0.65mm
U9, U10: LTV-247; SOP-16_4.4x10.4mm_P1.27mm

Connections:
+12V: C15.1, C16.1, C17.1, C18.1, C19.1, U4.6 (VCC), U5.6 (VCC), U6.8 (V+), U7.6 (VCC), U8.6 (VCC); also elsewhere on the board
/Connectors/ADC_0: R12.1; also elsewhere on the board
/Connectors/ADC_1: R20.1; also elsewhere on the board
/Connectors/DAC_0: R15.1, U6.1; also elsewhere on the board
/Connectors/DAC_1: R14.1, U6.7; also elsewhere on the board
/Connectors/DIN_0: R27.1; also elsewhere on the board
/Connectors/DIN_1: R29.1; also elsewhere on the board
/Connectors/DIN_2: R26.1; also elsewhere on the board
/Connectors/DIN_3: R24.1; also elsewhere on the board
/Connectors/DIN_4: R25.1; also elsewhere on the board
/Connectors/DIN_5: R28.1; also elsewhere on the board
/Connectors/DIN_6: R23.1; also elsewhere on the board
/Connectors/DIN_7: R22.1; also elsewhere on the board
/Connectors/DOUT_0: U4.5 (OUTB); also elsewhere on the board
/Connectors/DOUT_1: U4.7 (OUTA); also elsewhere on the board
/Connectors/DOUT_2: U5.5 (OUTB); also elsewhere on the board
/Connectors/DOUT_3: U5.7 (OUTA); also elsewhere on the board
/Connectors/DOUT_4: U7.5 (OUTB); also elsewhere on the board
/Connectors/DOUT_5: U7.7 (OUTA); also elsewhere on the board
/Connectors/DOUT_6: U8.5 (OUTB); also elsewhere on the board
/Connectors/DOUT_7: U8.7 (OUTA); also elsewhere on the board
/Digital IO/ADC0_MCU: D3.1 (K), R12.2, R13.1; also elsewhere on the board
/Digital IO/ADC1_MCU: D4.1 (K), R20.2, R21.1; also elsewhere on the board
/Digital IO/GPIO_DIN_0: U10.10; also elsewhere on the board
/Digital IO/GPIO_DIN_1: U10.12; also elsewhere on the board
/Digital IO/GPIO_DIN_2: U10.14; also elsewhere on the board
/Digital IO/GPIO_DIN_3: U10.16; also elsewhere on the board
/Digital IO/GPIO_DIN_4: U9.10; also elsewhere on the board
/Digital IO/GPIO_DIN_5: U9.12; also elsewhere on the board
/Digital IO/GPIO_DIN_6: U9.14; also elsewhere on the board
/Digital IO/GPIO_DIN_7: U9.16; also elsewhere on the board
/Digital IO/GPIO_DOUT_0: U4.4 (INB); also elsewhere on the board
/Digital IO/GPIO_DOUT_1: U4.2 (INA); also elsewhere on the board
/Digital IO/GPIO_DOUT_2: U5.4 (INB); also elsewhere on the board
/Digital IO/GPIO_DOUT_3: U5.2 (INA); also elsewhere on the board
/Digital IO/GPIO_DOUT_4: U7.4 (INB); also elsewhere on the board
/Digital IO/GPIO_DOUT_5: U7.2 (INA); also elsewhere on the board
/Digital IO/GPIO_DOUT_6: U8.4 (INB); also elsewhere on the board
/Digital IO/GPIO_DOUT_7: U8.2 (INA); also elsewhere on the board
/Digital IO/PWM0_MCU: R19.2; also elsewhere on the board
/Digital IO/PWM1_MCU: R18.2; also elsewhere on the board
GND: C13.2, C14.2, C15.2, C16.2, C17.2, C18.2, C19.2, D3.2 (A), D4.2 (A), R13.2, R16.2, R17.2, R21.2, U4.3 (GND), U5.3 (GND), U6.4 (V-), U7.3 (GND), U8.3 (GND), U9.2, U9.4, U9.6, U9.8, U9.9, U9.11, U9.13, U9.15, U10.2, U10.4, U10.6, U10.8, U10.9, U10.11, U10.13, U10.15; also elsewhere on the board
unnamed: R22.2, U9.1
unnamed: R23.2, U9.3
unnamed: R24.2, U10.1
unnamed: R25.2, U9.7
unnamed: R26.2, U10.3
unnamed: R27.2, U10.7
unnamed: R28.2, U9.5
unnamed: R29.2, U10.5
unnamed: C14.1, R19.1, U6.3 (+)
unnamed: R15.2, R17.1, U6.2 (-)
unnamed: C13.1, R18.1, U6.5 (+)
unnamed: R14.2, R16.1, U6.6 (-)

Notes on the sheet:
2x 0-10V
2x ADC 0-10 V


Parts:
C1, C5, C6: 100nF; C_0805_2012Metric
C2, C3: 18pF; C_0805_2012Metric
C4, C7: 1uF; C_0805_2012Metric
D1: LED; LED_0805_2012Metric_Pad1.15x1.40mm_HandSolder
J1: CONN_DEBUG; PinHeader_1x05_P2.54mm_Vertical
R1: 10k; R_0805_2012Metric
R2: 100R; R_0805_2012Metric
R3, R4, R5, R6: 4k7; R_0805_2012Metric
R7: 1k5; R_0805_2012Metric
U1: PIC18F57K42; TQFP-48_7x7mm_P0.5mm
Y1: Crystal_GND24; Crystal_SMD_SeikoEpson_FA238-4Pin_3.2x2.5mm

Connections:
+3.3V: C4.1, C5.1, C6.1, C7.1, J1.2, R1.1, R3.2, R4.2, R5.1, R6.1, R7.1, U1.7 (VDD), U1.30 (VDD); also elsewhere on the board
/Connectors/I2C_SCL: R4.1, U1.9 (RB1); also elsewhere on the board
/Connectors/I2C_SDA: R3.1, U1.10 (RB2); also elsewhere on the board
/Connectors/ONE_WIRE_0: R5.2, U1.22 (RA1); also elsewhere on the board
/Connectors/ONE_WIRE_1: R6.2, U1.21 (RA0); also elsewhere on the board
/Digital IO/ADC0_MCU: U1.24 (RA3); also elsewhere on the board
/Digital IO/ADC1_MCU: U1.23 (RA2); also elsewhere on the board
/Digital IO/GPIO_DIN_0: U1.38 (RF2); also elsewhere on the board
/Digital IO/GPIO_DIN_1: U1.37 (RF1); also elsewhere on the board
/Digital IO/GPIO_DIN_2: U1.36 (RF0); also elsewhere on the board
/Digital IO/GPIO_DIN_3: U1.35 (RC1); also elsewhere on the board
/Digital IO/GPIO_DIN_4: U1.29 (RE2); also elsewhere on the board
/Digital IO/GPIO_DIN_5: U1.28 (RE1); also elsewhere on the board
/Digital IO/GPIO_DIN_6: U1.27 (RE0); also elsewhere on the board
/Digital IO/GPIO_DIN_7: U1.26 (RA5); also elsewhere on the board
/Digital IO/GPIO_DOUT_0: U1.45 (RD3); also elsewhere on the board
/Digital IO/GPIO_DOUT_1: U1.46 (RC4); also elsewhere on the board
/Digital IO/GPIO_DOUT_2: U1.47 (RC5); also elsewhere on the board
/Digital IO/GPIO_DOUT_3: U1.48 (RC6); also elsewhere on the board
/Digital IO/GPIO_DOUT_4: U1.1 (RC7); also elsewhere on the board
/Digital IO/GPIO_DOUT_5: U1.2 (RD4); also elsewhere on the board
/Digital IO/GPIO_DOUT_6: U1.3 (RD5); also elsewhere on the board
/Digital IO/GPIO_DOUT_7: U1.4 (RD6); also elsewhere on the board
/Digital IO/PWM0_MCU: U1.8 (RB0); also elsewhere on the board
/Digital IO/PWM1_MCU: U1.5 (RD7); also elsewhere on the board
/MCU_PIC18/ADC_V_IN: U1.42 (RD0); also elsewhere on the board
/MCU_PIC18/ADC_V_IN_IO: U1.43 (RD1); also elsewhere on the board
/MCU_PIC18/RS485_RX: U1.39 (RF3); also elsewhere on the board
/MCU_PIC18/RS485_TX: U1.41 (RC3); also elsewhere on the board
/MCU_PIC18/RS485_TX_ENABLE: U1.40 (RC2); also elsewhere on the board
GND: C1.2, C2.2, C3.2, C4.2, C5.2, C6.2, C7.2, J1.3, U1.6 (VSS), U1.31 (VSS), Y1.2, Y1.4; also elsewhere on the board
ICSPCLK: J1.5, U1.18 (RB6)
ICSPDAT: J1.4, U1.19 (RB7)
LED_WORK: D1.1 (K), U1.17 (RB5)
MCLR: C1.1, R1.2, R2.1, U1.20 (MCLR/RE3)
unnamed: D1.2 (A), R7.2
unnamed: J1.1, R2.2
unnamed: C2.1, U1.33 (RA6), Y1.1
unnamed: C3.1, U1.32 (RA7), Y1.3


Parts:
J2: Conn_01x04; PhoenixContact_MSTBVA_2,5_4-G_1x04_P5.00mm_Vertical
J3: Conn_02x03_Odd_Even; PinSocket_2x03_P2.54mm_Vertical
J4, J6: Conn_01x10; PhoenixContact_MCV_1,5_10-G-3.5_1x10_P3.50mm_Vertical
J5: Conn_01x06; PhoenixContact_MCV_1,5_6-G-3.5_1x06_P3.50mm_Vertical

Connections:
+3.3V: J3.1; also elsewhere on the board
+12V: J6.5, J6.10; also elsewhere on the board
/Connectors/ADC_0: J5.5; also elsewhere on the board
/Connectors/ADC_1: J5.6; also elsewhere on the board
/Connectors/DAC_0: J5.2; also elsewhere on the board
/Connectors/DAC_1: J5.3; also elsewhere on the board
/Connectors/DIN_0: J6.9; also elsewhere on the board
/Connectors/DIN_1: J6.8; also elsewhere on the board
/Connectors/DIN_2: J6.7; also elsewhere on the board
/Connectors/DIN_3: J6.6; also elsewhere on the board
/Connectors/DIN_4: J6.4; also elsewhere on the board
/Connectors/DIN_5: J6.3; also elsewhere on the board
/Connectors/DIN_6: J6.2; also elsewhere on the board
/Connectors/DIN_7: J6.1; also elsewhere on the board
/Connectors/DOUT_0: J4.2; also elsewhere on the board
/Connectors/DOUT_1: J4.3; also elsewhere on the board
/Connectors/DOUT_2: J4.4; also elsewhere on the board
/Connectors/DOUT_3: J4.5; also elsewhere on the board
/Connectors/DOUT_4: J4.7; also elsewhere on the board
/Connectors/DOUT_5: J4.8; also elsewhere on the board
/Connectors/DOUT_6: J4.9; also elsewhere on the board
/Connectors/DOUT_7: J4.10; also elsewhere on the board
/Connectors/I2C_SCL: J3.4; also elsewhere on the board
/Connectors/I2C_SDA: J3.3; also elsewhere on the board
/Connectors/ONE_WIRE_0: J3.5; also elsewhere on the board
/Connectors/ONE_WIRE_1: J3.6; also elsewhere on the board
/Connectors/RS485-A: J2.3; also elsewhere on the board
/Connectors/RS485-B: J2.4; also elsewhere on the board
/Connectors/VIN: J2.1; also elsewhere on the board
GND: J2.2, J3.2, J4.1, J4.6, J5.1, J5.4; also elsewhere on the board

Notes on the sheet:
Inputs
Main Connector
One Wire, Open drain outputs
Outputs


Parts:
C8, C10: 10uF; C_1210_3225Metric
C9, C11, C12: 1uF; C_0805_2012Metric
D2: SMAJ28; D_SMA
L1: 3.9 uH; L_0805_2012Metric_Pad1.15x1.40mm_HandSolder
R8, R11: 10k; R_0805_2012Metric
R9, R10: 1k; R_0805_2012Metric
TH1: ECE SL075-33; Fuse_1812_4532Metric_Pad1.30x3.40mm_HandSolder
TH2: MF-MSMF050-2; Fuse_1812_4532Metric_Pad1.30x3.40mm_HandSolder
U2: R-78E5-0.5; Converter_DCDC_RECOM_R-78E-0.5_THT
U3: TLV70233DBVR; SOT-23-5

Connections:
+3.3V: C12.1, U3.5 (OUT); also elsewhere on the board
+5V: C10.1, C11.1, U2.3 (OUT), U3.1 (IN), U3.3 (EN); also elsewhere on the board
+12V: R11.1, TH2.1; also elsewhere on the board
/Connectors/VIN: TH1.2; also elsewhere on the board
/MCU_PIC18/ADC_V_IN: R8.2, R9.1; also elsewhere on the board
/MCU_PIC18/ADC_V_IN_IO: R10.2, R11.2; also elsewhere on the board
GND: C8.2, C9.2, C10.2, C11.2, C12.2, D2.2 (A), R9.2, R10.1, U2.2 (GND), U3.2 (GND); also elsewhere on the board
unnamed: C8.1, D2.1 (K), L1.2, TH1.1
unnamed: C9.1, L1.1, R8.1, TH2.2, U2.1 (IN)



Board: 2 copper layers, 58.2 x 64.0 mm, 83 parts (6 on the bottom side), 82 nets.

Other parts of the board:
 : MountingHole_2.5mm
 #2: MountingHole_2.5mm
Term.: Jumper; PinHeader_1x02_P2.54mm_Vertical

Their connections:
/Connectors/RS485-A: Term..1; also elsewhere on the board
unnamed 64: Term..2; also elsewhere on the board

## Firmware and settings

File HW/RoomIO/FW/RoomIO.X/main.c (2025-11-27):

/**
  Generated Main Source File

  Company:
    Microchip Technology Inc.

  File Name:
    main.c

  Summary:
    This is the main file generated using PIC10 / PIC12 / PIC16 / PIC18 MCUs

  Description:
    This header file provides implementations for driver APIs for all modules selected in the GUI.
    Generation Information :
        Product Revision  :  PIC10 / PIC12 / PIC16 / PIC18 MCUs - 1.81.6
        Device            :  PIC18LF57K42
        Driver Version    :  2.00
*/

/*
    (c) 2018 Microchip Technology Inc. and its subsidiaries. 

    Subject to your compliance with these terms, you may use Microchip software and any 
    derivatives exclusively with Microchip products. It is your responsibility to comply with third party 
    license terms applicable to your use of third party software (including open source software) that 
    may accompany Microchip software.
    
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
    IN NO EVENT WILL MICROCHIP BE LIABLE FOR ANY INDIRECT, SPECIAL, PUNITIVE,
    INCIDENTAL OR CONSEQUENTIAL LOSS, DAMAGE, COST OR EXPENSE OF ANY KIND
    WHATSOEVER RELATED TO THE SOFTWARE, HOWEVER CAUSED, EVEN IF MICROCHIP 
    HAS BEEN ADVISED OF THE POSSIBILITY OR THE DAMAGES ARE FORESEEABLE. TO 
    THE FULLEST EXTENT ALLOWED BY LAW, MICROCHIP'S TOTAL LIABILITY ON ALL 
    CLAIMS IN ANY WAY RELATED TO THIS SOFTWARE WILL NOT EXCEED THE AMOUNT 
    OF FEES, IF ANY, THAT YOU HAVE PAID DIRECTLY TO MICROCHIP FOR THIS 
    SOFTWARE.
*/

#include "mcc_generated_files/mcc.h"
#include "app.h"

/*
                         Main application
 */
void main(void)
{
    // Initialize the device
    SYSTEM_Initialize();

    // If using interrupts in PIC18 High/Low Priority Mode you need to enable the Global High and Low Interrupts
    // If using interrupts in PIC Mid-Range Compatibility Mode you need to enable the Global Interrupts
    // Use the following macros to:

    // Enable the Global Interrupts
    INTERRUPT_GlobalInterruptHighEnable();

    // Disable the Global Interrupts
    INTERRUPT_GlobalInterruptLowEnable();
    
    app_Init();

    while (1)
    {
        // Add your application code
        
        
        app_Task();
        
        
        
        
    }
}
/**
 End of File
*/

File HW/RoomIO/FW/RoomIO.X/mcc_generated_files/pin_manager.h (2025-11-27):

/**
  @Generated Pin Manager Header File

  @Company:
    Microchip Technology Inc.

  @File Name:
    pin_manager.h

  @Summary:
    This is the Pin Manager file generated using PIC10 / PIC12 / PIC16 / PIC18 MCUs

  @Description
    This header file provides APIs for driver for .
    Generation Information :
        Product Revision  :  PIC10 / PIC12 / PIC16 / PIC18 MCUs - 1.81.6
        Device            :  PIC18LF57K42
        Driver Version    :  2.11
    The generated drivers are tested against the following:
        Compiler          :  XC8 2.30 and above
        MPLAB 	          :  MPLAB X 5.40	
*/

/*
    (c) 2018 Microchip Technology Inc. and its subsidiaries. 
    
    Subject to your compliance with these terms, you may use Microchip software and any 
    derivatives exclusively with Microchip products. It is your responsibility to comply with third party 
    license terms applicable to your use of third party software (including open source software) that 
    may accompany Microchip software.
    
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
    IN NO EVENT WILL MICROCHIP BE LIABLE FOR ANY INDIRECT, SPECIAL, PUNITIVE, 
    INCIDENTAL OR CONSEQUENTIAL LOSS, DAMAGE, COST OR EXPENSE OF ANY KIND 
    WHATSOEVER RELATED TO THE SOFTWARE, HOWEVER CAUSED, EVEN IF MICROCHIP 
    HAS BEEN ADVISED OF THE POSSIBILITY OR THE DAMAGES ARE FORESEEABLE. TO 
    THE FULLEST EXTENT ALLOWED BY LAW, MICROCHIP'S TOTAL LIABILITY ON ALL 
    CLAIMS IN ANY WAY RELATED TO THIS SOFTWARE WILL NOT EXCEED THE AMOUNT 
    OF FEES, IF ANY, THAT YOU HAVE PAID DIRECTLY TO MICROCHIP FOR THIS 
    SOFTWARE.
*/

#ifndef PIN_MANAGER_H
#define PIN_MANAGER_H

/**
  Section: Included Files
*/

#include <xc.h>

#define INPUT   1
#define OUTPUT  0

#define HIGH    1
#define LOW     0

#define ANALOG      1
#define DIGITAL     0

#define PULL_UP_ENABLED      1
#define PULL_UP_DISABLED     0

// get/set ONE_WIRE_1 aliases
#define ONE_WIRE_1_TRIS                 TRISAbits.TRISA0
#define ONE_WIRE_1_LAT                  LATAbits.LATA0
#define ONE_WIRE_1_PORT                 PORTAbits.RA0
#define ONE_WIRE_1_WPU                  WPUAbits.WPUA0
#define ONE_WIRE_1_OD                   ODCONAbits.ODCA0
#define ONE_WIRE_1_ANS                  ANSELAbits.ANSELA0
#define ONE_WIRE_1_SetHigh()            do { LATAbits.LATA0 = 1; } while(0)
#define ONE_WIRE_1_SetLow()             do { LATAbits.LATA0 = 0; } while(0)
#define ONE_WIRE_1_Toggle()             do { LATAbits.LATA0 = ~LATAbits.LATA0; } while(0)
#define ONE_WIRE_1_GetValue()           PORTAbits.RA0
#define ONE_WIRE_1_SetDigitalInput()    do { TRISAbits.TRISA0 = 1; } while(0)
#define ONE_WIRE_1_SetDigitalOutput()   do { TRISAbits.TRISA0 = 0; } while(0)
#define ONE_WIRE_1_SetPullup()          do { WPUAbits.WPUA0 = 1; } while(0)
#define ONE_WIRE_1_ResetPullup()        do { WPUAbits.WPUA0 = 0; } while(0)
#define ONE_WIRE_1_SetPushPull()        do { ODCONAbits.ODCA0 = 0; } while(0)
#define ONE_WIRE_1_SetOpenDrain()       do { ODCONAbits.ODCA0 = 1; } while(0)
#define ONE_WIRE_1_SetAnalogMode()      do { ANSELAbits.ANSELA0 = 1; } while(0)
#define ONE_WIRE_1_SetDigitalMode()     do { ANSELAbits.ANSELA0 = 0; } while(0)

// get/set ONE_WIRE_0 aliases
#define ONE_WIRE_0_TRIS                 TRISAbits.TRISA1
#define ONE_WIRE_0_LAT                  LATAbits.LATA1
#define ONE_WIRE_0_PORT                 PORTAbits.RA1
#define ONE_WIRE_0_WPU                  WPUAbits.WPUA1
#define ONE_WIRE_0_OD                   ODCONAbits.ODCA1
#define ONE_WIRE_0_ANS                  ANSELAbits.ANSELA1
#define ONE_WIRE_0_SetHigh()            do { LATAbits.LATA1 = 1; } while(0)
#define ONE_WIRE_0_SetLow()             do { LATAbits.LATA1 = 0; } while(0)
#define ONE_WIRE_0_Toggle()             do { LATAbits.LATA1 = ~LATAbits.LATA1; } while(0)
#define ONE_WIRE_0_GetValue()           PORTAbits.RA1
#define ONE_WIRE_0_SetDigitalInput()    do { TRISAbits.TRISA1 = 1; } while(0)
#define ONE_WIRE_0_SetDigitalOutput()   do { TRISAbits.TRISA1 = 0; } while(0)
#define ONE_WIRE_0_SetPullup()          do { WPUAbits.WPUA1 = 1; } while(0)
#define ONE_WIRE_0_ResetPullup()        do { WPUAbits.WPUA1 = 0; } while(0)
#define ONE_WIRE_0_SetPushPull()        do { ODCONAbits.ODCA1 = 0; } while(0)
#define ONE_WIRE_0_SetOpenDrain()       do { ODCONAbits.ODCA1 = 1; } while(0)
#define ONE_WIRE_0_SetAnalogMode()      do { ANSELAbits.ANSELA1 = 1; } while(0)
#define ONE_WIRE_0_SetDigitalMode()     do { ANSELAbits.ANSELA1 = 0; } while(0)

// get/set ADC_1 aliases
#define ADC_1_TRIS                 TRISAbits.TRISA2
#define ADC_1_LAT                  LATAbits.LATA2
#define ADC_1_PORT                 PORTAbits.RA2
#define ADC_1_WPU                  WPUAbits.WPUA2
#define ADC_1_OD                   ODCONAbits.ODCA2
#define ADC_1_ANS                  ANSELAbits.ANSELA2
#define ADC_1_SetHigh()            do { LATAbits.LATA2 = 1; } while(0)
#define ADC_1_SetLow()             do { LATAbits.LATA2 = 0; } while(0)
#define ADC_1_Toggle()             do { LATAbits.LATA2 = ~LATAbits.LATA2; } while(0)
#define ADC_1_GetValue()           PORTAbits.RA2
#define ADC_1_SetDigitalInput()    do { TRISAbits.TRISA2 = 1; } while(0)
#define ADC_1_SetDigitalOutput()   do { TRISAbits.TRISA2 = 0; } while(0)
#define ADC_1_SetPullup()          do { WPUAbits.WPUA2 = 1; } while(0)
#define ADC_1_ResetPullup()        do { WPUAbits.WPUA2 = 0; } while(0)
#define ADC_1_SetPushPull()        do { ODCONAbits.ODCA2 = 0; } while(0)
#define ADC_1_SetOpenDrain()       do { ODCONAbits.ODCA2 = 1; } while(0)
#define ADC_1_SetAnalogMode()      do { ANSELAbits.ANSELA2 = 1; } while(0)
#define ADC_1_SetDigitalMode()     do { ANSELAbits.ANSELA2 = 0; } while(0)

// get/set ADC_0 aliases
#define ADC_0_TRIS                 TRISAbits.TRISA3
#define ADC_0_LAT                  LATAbits.LATA3
#define ADC_0_PORT                 PORTAbits.RA3
#define ADC_0_WPU                  WPUAbits.WPUA3
#define ADC_0_OD                   ODCONAbits.ODCA3
#define ADC_0_ANS                  ANSELAbits.ANSELA3
#define ADC_0_SetHigh()            do { LATAbits.LATA3 = 1; } while(0)
#define ADC_0_SetLow()             do { LATAbits.LATA3 = 0; } while(0)
#define ADC_0_Toggle()             do { LATAbits.LATA3 = ~LATAbits.LATA3; } while(0)
#define ADC_0_GetValue()           PORTAbits.RA3
#define ADC_0_SetDigitalInput()    do { TRISAbits.TRISA3 = 1; } while(0)
#define ADC_0_SetDigitalOutput()   do { TRISAbits.TRISA3 = 0; } while(0)
#define ADC_0_SetPullup()          do { WPUAbits.WPUA3 = 1; } while(0)
#define ADC_0_ResetPullup()        do { WPUAbits.WPUA3 = 0; } while(0)
#define ADC_0_SetPushPull()        do { ODCONAbits.ODCA3 = 0; } while(0)
#define ADC_0_SetOpenDrain()       do { ODCONAbits.ODCA3 = 1; } while(0)
#define ADC_0_SetAnalogMode()      do { ANSELAbits.ANSELA3 = 1; } while(0)
#define ADC_0_SetDigitalMode()     do { ANSELAbits.ANSELA3 = 0; } while(0)
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

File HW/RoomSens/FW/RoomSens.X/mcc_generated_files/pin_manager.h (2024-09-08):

/**
  @Generated Pin Manager Header File

  @Company:
    Microchip Technology Inc.

  @File Name:
    pin_manager.h

  @Summary:
    This is the Pin Manager file generated using PIC10 / PIC12 / PIC16 / PIC18 MCUs

  @Description
    This header file provides APIs for driver for .
    Generation Information :
        Product Revision  :  PIC10 / PIC12 / PIC16 / PIC18 MCUs - 1.81.6
        Device            :  PIC18LF57K42
        Driver Version    :  2.11
    The generated drivers are tested against the following:
        Compiler          :  XC8 2.30 and above
        MPLAB 	          :  MPLAB X 5.40	
*/

/*
    (c) 2018 Microchip Technology Inc. and its subsidiaries. 
    
    Subject to your compliance with these terms, you may use Microchip software and any 
    derivatives exclusively with Microchip products. It is your responsibility to comply with third party 
    license terms applicable to your use of third party software (including open source software) that 
    may accompany Microchip software.
    
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
    IN NO EVENT WILL MICROCHIP BE LIABLE FOR ANY INDIRECT, SPECIAL, PUNITIVE, 
    INCIDENTAL OR CONSEQUENTIAL LOSS, DAMAGE, COST OR EXPENSE OF ANY KIND 
    WHATSOEVER RELATED TO THE SOFTWARE, HOWEVER CAUSED, EVEN IF MICROCHIP 
    HAS BEEN ADVISED OF THE POSSIBILITY OR THE DAMAGES ARE FORESEEABLE. TO 
    THE FULLEST EXTENT ALLOWED BY LAW, MICROCHIP'S TOTAL LIABILITY ON ALL 
    CLAIMS IN ANY WAY RELATED TO THIS SOFTWARE WILL NOT EXCEED THE AMOUNT 
    OF FEES, IF ANY, THAT YOU HAVE PAID DIRECTLY TO MICROCHIP FOR THIS 
    SOFTWARE.
*/

#ifndef PIN_MANAGER_H
#define PIN_MANAGER_H

/**
  Section: Included Files
*/

#include <xc.h>

#define INPUT   1
#define OUTPUT  0

#define HIGH    1
#define LOW     0

#define ANALOG      1
#define DIGITAL     0

#define PULL_UP_ENABLED      1
#define PULL_UP_DISABLED     0

// get/set RA0 procedures
#define RA0_SetHigh()            do { LATAbits.LATA0 = 1; } while(0)
#define RA0_SetLow()             do { LATAbits.LATA0 = 0; } while(0)
#define RA0_Toggle()             do { LATAbits.LATA0 = ~LATAbits.LATA0; } while(0)
#define RA0_GetValue()              PORTAbits.RA0
#define RA0_SetDigitalInput()    do { TRISAbits.TRISA0 = 1; } while(0)
#define RA0_SetDigitalOutput()   do { TRISAbits.TRISA0 = 0; } while(0)
#define RA0_SetPullup()             do { WPUAbits.WPUA0 = 1; } while(0)
#define RA0_ResetPullup()           do { WPUAbits.WPUA0 = 0; } while(0)
#define RA0_SetAnalogMode()         do { ANSELAbits.ANSELA0 = 1; } while(0)
#define RA0_SetDigitalMode()        do { ANSELAbits.ANSELA0 = 0; } while(0)

// get/set ONE_WIRE_1 aliases
#define ONE_WIRE_1_TRIS                 TRISAbits.TRISA1
#define ONE_WIRE_1_LAT                  LATAbits.LATA1
#define ONE_WIRE_1_PORT                 PORTAbits.RA1
#define ONE_WIRE_1_WPU                  WPUAbits.WPUA1
#define ONE_WIRE_1_OD                   ODCONAbits.ODCA1
#define ONE_WIRE_1_ANS                  ANSELAbits.ANSELA1
#define ONE_WIRE_1_SetHigh()            do { LATAbits.LATA1 = 1; } while(0)
#define ONE_WIRE_1_SetLow()             do { LATAbits.LATA1 = 0; } while(0)
#define ONE_WIRE_1_Toggle()             do { LATAbits.LATA1 = ~LATAbits.LATA1; } while(0)
#define ONE_WIRE_1_GetValue()           PORTAbits.RA1
#define ONE_WIRE_1_SetDigitalInput()    do { TRISAbits.TRISA1 = 1; } while(0)
#define ONE_WIRE_1_SetDigitalOutput()   do { TRISAbits.TRISA1 = 0; } while(0)
#define ONE_WIRE_1_SetPullup()          do { WPUAbits.WPUA1 = 1; } while(0)
#define ONE_WIRE_1_ResetPullup()        do { WPUAbits.WPUA1 = 0; } while(0)
#define ONE_WIRE_1_SetPushPull()        do { ODCONAbits.ODCA1 = 0; } while(0)
#define ONE_WIRE_1_SetOpenDrain()       do { ODCONAbits.ODCA1 = 1; } while(0)
#define ONE_WIRE_1_SetAnalogMode()      do { ANSELAbits.ANSELA1 = 1; } while(0)
#define ONE_WIRE_1_SetDigitalMode()     do { ANSELAbits.ANSELA1 = 0; } while(0)

// get/set PIR_SIGNAL aliases
#define PIR_SIGNAL_TRIS                 TRISAbits.TRISA2
#define PIR_SIGNAL_LAT                  LATAbits.LATA2
#define PIR_SIGNAL_PORT                 PORTAbits.RA2
#define PIR_SIGNAL_WPU                  WPUAbits.WPUA2
#define PIR_SIGNAL_OD                   ODCONAbits.ODCA2
#define PIR_SIGNAL_ANS                  ANSELAbits.ANSELA2
#define PIR_SIGNAL_SetHigh()            do { LATAbits.LATA2 = 1; } while(0)
#define PIR_SIGNAL_SetLow()             do { LATAbits.LATA2 = 0; } while(0)
#define PIR_SIGNAL_Toggle()             do { LATAbits.LATA2 = ~LATAbits.LATA2; } while(0)
#define PIR_SIGNAL_GetValue()           PORTAbits.RA2
#define PIR_SIGNAL_SetDigitalInput()    do { TRISAbits.TRISA2 = 1; } while(0)
#define PIR_SIGNAL_SetDigitalOutput()   do { TRISAbits.TRISA2 = 0; } while(0)
#define PIR_SIGNAL_SetPullup()          do { WPUAbits.WPUA2 = 1; } while(0)
#define PIR_SIGNAL_ResetPullup()        do { WPUAbits.WPUA2 = 0; } while(0)
#define PIR_SIGNAL_SetPushPull()        do { ODCONAbits.ODCA2 = 0; } while(0)
#define PIR_SIGNAL_SetOpenDrain()       do { ODCONAbits.ODCA2 = 1; } while(0)
#define PIR_SIGNAL_SetAnalogMode()      do { ANSELAbits.ANSELA2 = 1; } while(0)
#define PIR_SIGNAL_SetDigitalMode()     do { ANSELAbits.ANSELA2 = 0; } while(0)

// get/set RA3 procedures
#define RA3_SetHigh()            do { LATAbits.LATA3 = 1; } while(0)
#define RA3_SetLow()             do { LATAbits.LATA3 = 0; } while(0)
#define RA3_Toggle()             do { LATAbits.LATA3 = ~LATAbits.LATA3; } while(0)
#define RA3_GetValue()              PORTAbits.RA3
#define RA3_SetDigitalInput()    do { TRISAbits.TRISA3 = 1; } while(0)
#define RA3_SetDigitalOutput()   do { TRISAbits.TRISA3 = 0; } while(0)
#define RA3_SetPullup()             do { WPUAbits.WPUA3 = 1; } while(0)
#define RA3_ResetPullup()           do { WPUAbits.WPUA3 = 0; } while(0)
#define RA3_SetAnalogMode()         do { ANSELAbits.ANSELA3 = 1; } while(0)
#define RA3_SetDigitalMode()        do { ANSELAbits.ANSELA3 = 0; } while(0)
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

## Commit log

2023-12-19 RoomIO - PCB design and FW for PIC MCU
    [Connectors.kicad_sch, Digital_IO.kicad_sch, MCU_PIC18.kicad_sch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]
2023-12-19 RS4852USB - PCB design
    [Power.kicad_sch, RS485USB.kicad_pcb, RS485USB.kicad_sch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]
2024-09-08 Add RoomSens Device, Add SW Majordomus Control - RS485 to MQTT Bridge
    [Connectors.kicad_sch, Digital_IO.kicad_sch, MCU_PIC18.kicad_sch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]
2024-11-29 FW - Room Sens v0.3, fix touch long press, display initialization, serial interface update
    [app.c, lcd_NHDC12832.c]
2024-12-10 Create Protocol Majordomus Rs-485 ASCII.md
    HW device RS485 protocol ASCII
2025-03-19 Tiny sensor PCB and FW
    [Connectors.kicad_sch, Digital_IO.kicad_sch, MCU_PIC18.kicad_sch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]
2026-06-19 Add support for BoxIO HW, configuration - new autodetect all devices on bus, add double, tripple click, long click, HA integration
2026-07-27 Majordomus control - bullet proof autodetect devices
